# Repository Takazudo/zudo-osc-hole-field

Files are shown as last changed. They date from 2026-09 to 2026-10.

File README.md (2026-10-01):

# zudo-osc-hole-field

A standalone, cable-patched analog synthesizer on one flat 318 × 298 mm front panel, with 180 jacks above 144 controls and 33 module instances. Documentation domain: [zudo-osc-hole-field.zudolab.dev](https://zudo-osc-hole-field.zudolab.dev).

**Status:** pre-release design; no fabrication release exists.

The site is built with [zudo-circuit-doc](https://github.com/Takazudo/zudo-circuit-doc) on top of [zudo-doc](https://github.com/zudolab/zudo-doc). Authored project documentation lives under `doc/src/content/docs/`; exact-component evidence lives under `.claude/skills/`, and the component pages are generated from that evidence.

GitHub Actions runs the evidence validation, documentation checks, site build and built-site checks, plus Python unit tests under `scripts/` and `design/`, for pull requests and pushes to `main`. CI also replays aggregate source regeneration, including pinned native schematic and display checks, and retains any generated diff when that replay fails. These checks need no secrets and do not deploy the site; they do not establish electrical or physical qualification.

## Commands

| Command | What it does |
| --- | --- |
| `pnpm install` | Install dependencies |
| `pnpm dev` | Dev server, regenerating component pages as evidence changes |
| `pnpm build` | Publish selected models, generate component pages, build the site |
| `pnpm check` | Validate evidence, check generated output is current, type-check the site |
| `pnpm check:site` | Post-build checks: references, publication scope, links |
| `pnpm circuit:check` | Validate the component evidence (offline) |
| `pnpm circuit:generate` | Regenerate the component pages and the preflight report |
| `pnpm circuit:doctor` | Report required and optional tools |
| `pnpm previews:generate` | Render footprint previews (optional; needs Docker) |

Agent-facing commands (new component bundles, online source refresh) are listed in [circuit/WORKFLOW.md](circuit/WORKFLOW.md).

## Tool requirements

| Tool | Required | Used for |
| --- | --- | --- |
| Node.js ≥22.18 | Yes | Everything |
| pnpm 11 (via corepack) | Yes | Install and scripts |
| Python ≥3.10 | Yes | Evidence validation (standard library only) |
| git | Yes | History and review diffs |
| Docker with the pinned KiCad image | No | Footprint previews |
| Chrome | No | Browser smoke check |
| Network | No | Downloading sources and assets only; the build is offline |
| easyeda2kicad | No | Importing CAD assets for LCSC-listed parts |

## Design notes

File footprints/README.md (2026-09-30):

# KiCad footprints

The project has one footprint library at
`footprints/kicad/zudo-osc-hole-field.pretty/`. Keep each `.kicad_mod` there
once; do not maintain a second byte-identical master copy. Place associated 3D
models under `footprints/kicad/zudo-osc-hole-field.3dshapes/` and use the
project's `${KIPRJMOD}` model prefix.

Footprint origins follow the part's functional datum. For panel hardware, the
origin is on the panel-hole axis so the fixed panel placement remains the
reference. This seed set contains generic parts and does not move any panel
hardware.

Courtyards are generated, never hand-drawn. `scripts/libgen/gen_courtyards.py`
replaces only `F.CrtYd` artwork with a rectangular outline enclosing pads and
body artwork plus 0.25 mm, using a 0.05 mm stroke. Run
`bash scripts/libgen/regen.sh` after footprint changes and regenerate after a
merge conflict; preserve any non-courtyard artwork edits.

Each imported symbol, footprint, and model is covered by a receipt in
`circuit/cad-receipts/`. A receipt records the pinned source path and commit,
hashes of inspected source bytes and output bytes, plus a fidelity class. The
seeded package footprints are classified as `family`; they are not proven
manufacturer-specific geometry. The white LED footprint's source model was
unavailable in the pinned commit, so that footprint has no 3D-model reference.

The seed importer refuses to overwrite existing assets. To intentionally
refresh them from the read-only sibling checkout, review the current diffs and
run `python3 scripts/libgen/seed_assets.py --source-repo <path> --replace`,
then run `bash scripts/libgen/regen.sh --check`.

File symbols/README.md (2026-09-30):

# KiCad symbols

Each authored symbol has one fragment at `symbols/src/<SymbolName>.kicad_sym`.
The committed `symbols/zudo-osc-hole-field.kicad_sym` library is generated from
those fragments in sorted symbol-name order.

Do not hand-edit the assembled library. Update the affected fragment, then run
`bash scripts/libgen/regen.sh`. If a merge conflicts in the assembled library,
keep either version long enough to resolve the fragments and regenerate it.

Every symbol carries `MPN`, `Manufacturer`, and `LCSC` properties. A blank LCSC
value records that no supplier code was verified; do not fill it from a guess.
Non-orderable utility symbols may use blank MPN and manufacturer values. Any
non-empty footprint reference uses the `zudo-osc-hole-field` nickname and must
resolve inside the project's single `.pretty` library.

Seed fragments were extracted from the pinned zudo-pd commit recorded in their
CAD receipts. `python3 scripts/libgen/seed_assets.py --source-repo <path>` is an
explicit import operation; ordinary regeneration does not read the sibling
repository.

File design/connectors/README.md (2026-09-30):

# JST GH conditional harness candidate

Issue #63 retains the JST eGH primary drawing and owns the exact BM top-entry 3-, 7-, and 8-contact header CAD and evidence. `jst-gh.json` is the machine-readable handoff to #35. The 7.3 mm mated height is a reference dimension, without an installed stack tolerance. The generated WRL is a nominal header body prism, with KiCad's model Y axis inverted relative to the mounting-surface footprint drawing; it is not a vendor solid or a housing/cable model.

The drawing's top-entry PC layout gives 0.6 mm pad width, 1.25 mm pitch, 1.0 × 2.8 mm reinforcement lands, 1.35 mm from pin 1 centre to the reinforcement land's inner edge, 5.6 mm total vertical land span, and 3.9 mm from the signal-land bottom to reinforcement-land bottom. These imply 1.7 mm signal-land length. No drills occur in this SMT pattern. The project courtyard adds 0.25 mm beyond the outer pad or body bound.

With the header centred on the adapter x axis, the unchanged selector mounting pad's inner copper edge is x=8−2.6/2=6.70 mm. The GH7 generated courtyard reaches x=6.35 mm, leaving 0.35 mm nominal x clearance. GH8 reaches x=6.97 mm after the courtyard generator's two-decimal rounding and overlaps copper by 0.27 mm. This is a nominal geometric comparison only; #35 owns connector y/rotation placement, routing, cable paths, support and packing.

The GHR housing and SSHL contact symbols/footprints named `EXTERNAL_NOT_FOR_PCB` exist only to verify cavity/contact numbering through the evidence pin-map contract. They must never be placed on a board. Primary ratings cover 1 A with AWG26, 50 V and −40..+105 °C including current rise. Simultaneous-contact derating, crimp quality, pull retention, loom bend/strain relief, installed stack and physical fit remain OPEN / NOT RUN. No board or harness is qualified.

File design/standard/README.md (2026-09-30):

# OSC-ES-1 electrical proposal

Authority is **PROPOSAL (planning, owner-delegated)**. These remain design inputs, not captured circuits, accepted system behavior, or manufacturing data. Issues #15, #18 and #21 retained source bytes, audited selected pin maps, ran draft cell checks, and promoted exact component evidence into the generated catalogue.

- `electrical-standard.json`: named role-to-part mapping, signal limits, 19 functional cell definitions, remote-control/island and calibration contracts, and explicit disposition of all fourteen planning defaults.
- `parts-shortlist.json`: 36 exact shared-family representatives. Blank supplier codes and `UNVERIFIED` availability are intentional. A listed identity does not establish factory stock.
- `rail-budget-preliminary.json`: planning module counts, conservative additions, package rounding, load assumptions and arithmetic. **The negative rail exceeds its design ceiling by 72.655 mA.**
- `source-receipts.json`: primary PDF byte receipts used for amplifier current choices and the retained Analog Devices Rev. C ADG5412F source. The exact selected identities and source facts are promoted in #21's component owner bundles.
- `../../project/osc-hole-field/electrical-decisions.json`: E01–E09. Existing D01–D12 remain untouched.

Run `python3 design/standard/check_standard.py` from any directory. A consistency pass includes an explicit over-budget finding; it does not certify a passing rail budget. It checks IDs, exact-family references, cell parts/values, amplifier allocation arithmetic, ideal threshold/gain/RC/fault calculations and truthful budget flags.

Cell terminals are functional names. The #21 component owner records map numeric symbol/footprint pins to #15 and #29's retained manufacturer evidence. ALFA RPAR's retained 2020 v.7 PDF confirms AS3340D SOIC-16 identity and pin functions; schematic nets, supply suitability, oscillator behavior, calibration, physical fit, and procurement remain open. Cells request amplifier roles; do not embed amplifier MPNs in Python cell implementations.

Passive entries are exact shortlist series representatives in one shared owner bundle. The generated catalogue publishes the real `RC0603FR-07100KL` record as that bundle's landing page; the other ten exact representative MPNs remain separate inventory/owner records. A 100 kohm representative is not the orderable MPN for a 10 kohm resistor. No pseudo family MPN or per-value expansion is introduced; unknown order codes remain open.

## Work note

Requested: decide the instrument-wide electrical standard and downstream contract. Initial `regen-all.sh` and `pnpm circuit:check` passed, with no tracked regeneration. Inventory and integration rules were empty; CAD checking was disabled. Read the imported R21 contracts and the planning size/current table, then recomputed a deliberately conservative package budget with every additional input, reference, remote-pot, wiper and indicator buffer charged explicitly.

The design adds source-facing power-off isolation, lowers bulk amplifier quiescent current, reduces the 48 DC pot loads, specifies factory calibration and keeps sensitive nodes local. No panel geometry, imported handoff, generated component page, or sibling-owned document was edited.

Remaining work includes AS3340D commercial orderability, full electrical/supply suitability and physical fit, exact Murata lifecycle/evidence gaps, the Fenghua exact-MPN gap, physical/temperature/tolerance checks and value-specific passive identities for precision-output stability, module capture, #24 power-off/rail sequencing and startup, #29 octave error and oscillator calibration, #33 a netlist-derived budget, and #34 resolving the 72.655 mA preliminary negative-rail deficit before #35 partition. The revised precision-output cell passes 12/12 TI OPAx197 model cases at 27 °C, but no hardware qualification follows from that result. The ADG5412F project-supply fault response/current budget, physical fit, cable stability, thermal behavior and procurement remain open. Full site build belongs to the manager's merged-base guarded verification.

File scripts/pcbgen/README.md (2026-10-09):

# PCB draft sync

Run `bash scripts/kicad/run.sh python3 scripts/pcbgen/sync.py <board-id>` after the matching KiCad schematic netlist has been exported. Board definitions live in `design/boards/<board-id>.json`; the checked-in `fixture-jacks` definition demonstrates the format. The generator reads panel hardware coordinates only from `design/grid/placements.lock.json`, then translates them with `scripts/geometry/panel_frame.py:to_kicad()`.

The definition contains a panel-frame outline polygon, optional convex corner radius, 2/4/6/8 copper-layer count, preliminary layer stackup and thickness, NPTH mounting holes, copper keepout polygons, board domains, and the exact selected lockfile UIDs. Those domains and UIDs are eligibility and coordinate inputs; the exported netlist controls which footprints are populated. A netlisted `FootprintOriginMm` seeds the exact panel-frame centre, and `KiCadOrientationDeg` sets the native angle after a `BoardSide` flip. Parts without a source origin begin on a bounded off-board staging grid. Fixed panel hardware must stay on `F.Cu`. `F.Cu` faces the panel and `B.Cu` faces away. The shared panel origin is translated to `(100, 50)` mm and used for both drill/place and grid origin. Board sheet size is A2.

A footprint belongs to this generator only when its UUID equals the UUIDv5 derived from the board ID and reference. The same rule applies to outline segments, declared mounting holes, and rule-area keepouts. Sync can remove those items when the source removes them. It never removes an unowned footprint, track, via, zone, text or graphic; a conflicting unowned reference fails before the generator takes it over. Existing free footprints retain their current location. Fixed hardware footprints return to their lockfile position and are locked. Library footprints are loaded once per type, then cloned. KiCad's random generated UUIDs are rewritten after save; the postpass also sorts only owned footprint/keepout blocks so repeated syncs are byte-identical. Schematic paths use the netlist sheet and symbol UUIDs.

Fixed hardware always returns to F.Cu before the exact lockfile angle is applied.
An explicit B.Cu or conflicting `KiCadOrientationDeg` fails without saving the
board; equivalent full turns are accepted but the lockfile angle is retained.
For free components, changing the library footprint preserves position, side,
native angle and locked state. Explicit `BoardSide` then applies KiCad's native
flip, followed by an explicit `KiCadOrientationDeg` if supplied. Source-origin
locking still applies when `FootprintOriginMm` is present without `BoardRegion`;
sync never unlocks an existing free footprint. Nonfinite source angles fail.
New hidden source fields explicitly use KiCad's 0.15 mm default text thickness
so their first saved form survives reload unchanged; existing field strokes remain untouched.

`bash scripts/pcbgen/check.sh <board-id>` runs the pinned KiCad 10.0.6 DRC with schematic parity, zone refill and all severities, then writes JSON, top/bottom PNG renders and an SVG to `boards/<board-id>/reports/`. The summary separates rule violations, unconnected items and parity issues, and exits nonzero for DRC errors or parity issues. It does **not** claim that a clean rule check qualifies the PCB or its mechanical fit.

Run `python3 -m unittest scripts.pcbgen.test_pure -v` for board-definition and UUID tests and `bash scripts/pcbgen/test_fixture.sh` for the ten-jack oracle fixture. The fixture tests exact lockfile placement, zero schematic parity issues, byte-identical repeat sync, owner track/via/zone/text/graphic preservation, component re-netting, and component removal. Its jacks are deliberately unrouted; unconnected items are expected. The synthetic circuit and board are unvalidated drafts and are never fabrication order files.

The fixture also runs `fixtures/check_sync_pose.py` through the pinned oracle:
saved B.Cu hardware is repaired to its fixed front pose, conflicting fields leave
board bytes unchanged, replacement preserves both lock states and B.Cu placement,
explicit source overrides take precedence, and repeat sync stays byte-identical.
`python3 -m unittest scripts.pcbgen.test_pose -v` checks the pure source policy.

Current limitations: the stackup JSON records intent while KiCad receives thickness and copper count; detailed dielectric/material rule values await the board-stack decision. Fillets require a strictly convex polygon. The fixture cannot establish physical jack-panel fit or electrical function.

## Reviewed routing translations

`design/partition/routing-placement-translations.json` is an explicit source input to the floorplan generator. Its default empty list changes no placement. A reviewed translation binds the complete expected source row, a nonempty evidence reference and a nonzero 0.1mm-grid delta within ±2mm. It is restricted to movable JL/JR resistors outside bypass clusters; side and orientation cannot change. The generator rejects stale source rows, duplicate entries, source-edge clearance below0.30mm and courtyard separation below0.35mm. It does not repack other components.

This source geometry mechanism does not accept routed copper. Any activation still needs native10.0.6 placement, DRC/parity, warnings, original pad-group membership, settled/fresh agreement and full retained-copper checks after schematic/source regeneration. Fixed panel hardware remains bound to the original lockfile. Never edit the generated floorplan JSON to adopt a movement.

## Region placement for repeated clusters

After sync, `place.py` positions generator-owned, unlocked free footprints within the optional `regions` in a board definition. Each region names a schematic `Block` instance and a repeated `family`, plus a panel-frame `rect` `[left, top, right, bottom]` in millimetres, `side` (`F.Cu` or `B.Cu`), `edge_clearance_mm`, and `mounting_clearance_mm`. See `fixture-place-six.json` for six 17 mm translated regions. One block may declare both faces when each part has an explicit `BoardSide`. A part with `FootprintOriginMm` is checked at that exact source coordinate against its native courtyard and obstacles; it is never searched onto a different position. The placement UIDs and fixed hardware coordinates still come solely from the grid lockfile. Locked or unowned free footprints keep their locations; an absent or moved fixed footprint is an error.

Export the schematic netlist, run sync, then run `bash scripts/kicad/run.sh python3 scripts/pcbgen/place.py <board-id>`. `--board`, `--netlist`, and `--report` select alternate paths. The report defaults to `reports/placement.json` beside the board. Each schematic `Block` must have a matching region. A family is placed once from its courtyard boxes, and each repeated instance receives the same relative positions translated to its region. A component with an `Island` field naming a selected panel UID is anchored near that hardware. `DecouplingOf` can name an IC `Role` or reference; otherwise shared signal nets assign nearby passives to an IC cluster. Courtyards, both-side through-hole pads, mounting holes, keepouts, and outline edges constrain legal positions. There is no spill outside the named region. An impossible placement exits nonzero and writes an `OVERFLOW` report with the instance, needed area, and available area; it does not save the board.

Courtyard containment checks every outline edge against the complete courtyard rectangle, including concave cutouts and the closest distance to an edge or notch tip. Boundary contact is rejected; positive edge clearances retain the existing 1e-6 mm comparison tolerance. Every chosen region must agree with the native footprint face and any explicit `BoardSide`. Explicit `FootprintOriginMm` anchors retain precedence over a searched template and are never relocated; an anchored base supplies the template for later repetitions without an explicit anchor.

Run `bash scripts/pcbgen/test_placer.sh` for one-instance, six-instance, island, and overflow oracle fixtures. It checks second-run byte identity, exact 17 mm translations, zero courtyard violations, and zero schematic parity issues in KiCad 10. The fixture is unrouted, so unconnected DRC items are expected. The placer uses conservative axis-aligned courtyard boxes and a 0.5 mm search grid. The suite also rejects repeated templates on the wrong native face without changing board bytes and checks anchored-base template reuse. Its report remains `PLACED DRAFT`; final layout and mechanical/electrical qualification require later checks.

## Draft routing pipeline

Add `routing` to a board definition with `min_track_width_mm`, `net_classes`, and `zones`. Each class names exact nets and gives `track_width_mm`, `clearance_mm`, `via_diameter_mm`, and `via_drill_mm`. The `Default` class covers all other nets. A zone specifies its net, copper layers, local clearance, minimum fill thickness, and `pad_connection` (`thermal` or `full`). Its optional `polygon` selects an explicit split-plane shape; absent it, the board outline is used. KiCad applies copper-edge clearance during fill. Two-layer fixtures use ground pours; the four-layer fixture uses `In1.Cu` ground and `In2.Cu` +12 V planes. The dense fixture additionally uses an `F.Cu` ground pour to join inner-plane regions cut by connector escapes. These dimensions are draft routing inputs, not fabrication limits.

Run `bash scripts/pcbgen/route.sh <board-id>` after netlist export, sync, and placement. `--board` selects a fixture or other repository-local board path; `--threads`, `--heap-mb`, and `--timeout-sec` override the defaults in `router.env`. The default router has at most half the host's CPU threads (capped at six), a 2 GiB JVM heap, a bounded container memory limit, and a 180-second wall limit. It disables Freerouting's optional optimization stage so a bounded autoroute can write its SES result. `--no-fanout` is available for continuation runs whose existing copper already escapes SMD pins. `route.sh` enters the machine-wide heavy-run queue. Freerouting runs offline in a digest-pinned container. The pipeline updates project net classes and minimum track width, creates owned zones without deleting owner zones, fixes existing tracks/vias, fills zones, exports Specctra DSN, routes headlessly (`-de`, `-do`, `-mt`), imports SES, checks every pre-existing track/via and zone, refills, and runs KiCad 10 DRC with schematic parity. Freerouting's 2.4.1 [CLI options](https://github.com/freerouting/freerouting/blob/v2.4.1/docs/command_line_arguments.md) and [release](https://github.com/freerouting/freerouting/releases/tag/v2.4.1) are the primary command source.

The default report is `reports/routing.json` beside the board, with routed/unrouted net counts and names, via count, total track length, run time, sampled container memory peak, and separate KiCad error/warning/unconnected/parity counts. `reports/ratsnest.json` also records the complete native KiCad unconnected-edge count; large-board DRC JSON can truncate its item and net-name list, so names from that JSON are only a sample when the counts differ. `ROUTED DRAFT` requires zero KiCad rule errors, unconnected items, and parity issues. Exit 3 means `TIMEOUT DRAFT`; the report names nets from the router's final log when available and otherwise labels the pre-route DRC snapshot. Other incomplete or failed routes exit 2. A fully routed board skips the router and leaves board bytes unchanged; rule and parity errors still fail. Prepared source copper and refilled planes are also checked before invoking the heuristic router. Silkscreen warnings can remain on synthetic fixtures and are reported separately.

`--max-passes` raises Freerouting's pass limit (default 20) for a single bounded run. Before importing a session, the pipeline drops its `(placement ...)` block: routing never moves footprints, and Freerouting writes board-only NPTH footprints without an image name, which KiCad's SES parser rejects.

`finish_routes.py` is an optional finishing pass for the few connections a heuristic run leaves open. Run it through `scripts/kicad/run.sh` after `route.sh`. It finds nets that still have more than one native connectivity cluster and adds tracks and vias with a two-layer 0.1 mm grid maze search. The search keeps each net-class width and clearance, the board hole and edge clearances, and track/via keepouts, and it never places a via over an SMD pad. When no path exists, it may rip up the tracks and vias of the fewest blocking signal nets, then route them again in a new process (bounded by `--max-rips`). Rail and ground copper is never ripped up. Pads, footprints, holes, zones and keepouts never move. It writes `reports/finish-routes.json`. Re-run `route.sh` or `check.sh` afterwards; only native KiCad DRC with schematic parity decides whether the result is acceptable.

`replicate.py` copies **local-net** tracks and vias from one `Block` to translated instances of the same region family. It matches source and target parts through their `Role`/footprint signatures, pin numbers, nets, and exact footprint/pad translations. Shared rail/ground tracks and already routed target nets are left alone. The remaining shared nets should then be routed by `route.sh`. Run it through `scripts/kicad/run.sh` with `--source` and optional `--targets`; it writes `reports/replication.json`. It refuses a placement that differs from the template.

`bash scripts/pcbgen/test_route.sh --quick` builds and checks the two-layer, four-layer, six-instance replication, rerun, and timed-out barrier fixtures. `--dense` reproducibly builds the full 3 × 10 jack stress slice from retained copper sources, adds the explicit ground stitching, checks the complete DRC gate, repeats generation, and exercises missing-via and stale-geometry regressions. `--dense-route` performs a new bounded source-column/full-slice heuristic experiment and archives prior cache attempts. The accepted repair, measured failures, and ownership boundary are documented in [dense-evidence/README.md](fixtures/dense-evidence/README.md). The fixture uses audited jack footprints, one OPA4196 quad-amp **section** per synthetic indicator (one package per cell for independent routing stress), an LED and passives, and one 40-pin KiCad stock connector. It is deliberately a routing stress topology, not the proposed indicator circuit or a package-count decision. The pinned KiCad stock connector symbol fragment is retained in `fixtures/Conn_02x20_Odd_Even.kicad_sympart` (SHA-256 `247f848336a03a540f21f6ca8cd6fd064ef3f38b89cdef1e6d7a947aa7ae2d57`). `fixtures/dense-slice-report.json` records measured completion and resource results. Every autorouted PCB remains an unvalidated draft for human routing, thermal, mechanical, and fabrication review.

## Draft ground extraction numerical setup

`bash scripts/pcbgen/test_native_prerequisites.sh` runs the standalone control/core
terminal-access, enabled-foil export and core package-field regressions through
the pinned KiCad oracle under the heavy guard. These executable native fixtures
use `*_native_regression.py` names; they are not ordinary Python unittest modules.
Each run retains fresh local fixture receipts and leaves earlier evidence intact.

Use a disposable local environment; the pinned KiCad oracle exports native
geometry separately. Numerical extraction never changes a PCB or qualifies
materials, soldering, temperature, or hardware.

```sh
python3 -m venv .circuit-cache/ground-solver-venv
.circuit-cache/ground-solver-venv/bin/python -m pip install -r scripts/pcbgen/numerical-requirements.txt
.circuit-cache/ground-solver-venv/bin/python -m unittest scripts.pcbgen.test_ground_access scripts.pcbgen.test_ground_annular
```

The pins are also installed before Python unit-test discovery in CI. The separate
`power_locality_native_regression.py` runs explicitly through the pinned oracle in
CI; it proves that a pad and orphan zone cannot pass a main-network audit. Full-board
resistance solves run through `bash $HOME/.codex/scripts/heavy-guard.sh --` and
retain the board/source hashes, finite interface definitions, material conditions,
convergence limits, and exact failure reason. Native electrical connectivity,
numerical screens, and physical qualification are distinct gates.

## Grid router and cut-line capacity

`grid_dump.py` (KiCad oracle, read-only) exports pads, tracks, vias, keepouts, the outline and the native open pad islands of a four-layer board. On the host, `grid_router.py` joins each open island to its net's largest island with a grid A* path over F.Cu/In1.Cu/In2.Cu/B.Cu and through vias. `--rip` removes and reroutes named signal nets around boxed-in pins. It writes an unchecked proposal of explicit segments and vias with stable UUIDs. `grid_apply.py` (KiCad oracle) writes that proposal into a candidate board copy. Accept a proposal only after native DRC/parity, refill, ratsnest and ground checks on the candidate. Put the candidate two directories below the repository root, for example `.circuit-cache/<name>/` with the board's `fp-lib-table`, `sym-lib-table`, project, schematic and `sheets/`. Elsewhere `${KIPRJMOD}/../../` does not resolve and DRC reports spurious `lib_footprint_issues`. The raster is conservative by one cell half-diagonal; zone pours are not obstacles because they refill around new copper, so cut pours need their own ground check.

`cut_capacity.py` reads the same dump and scans vertical and horizontal lines. Demand is the number of signal nets with pads on both sides; capacity per layer is the ideal number of track centrelines at the chosen width plus clearance in the line's free runs. A signal-layer ratio below 1 proves those layers cannot carry the crossing nets; ratios near 1 are still unroutable in practice. Both tools need `numerical-requirements.txt`. `python3 -m unittest scripts.pcbgen.test_grid_router` covers synthetic routing, via use, clearance, boxed pins and capacity.

## Neck-down areas at IC pin rows

`design/partition/neckdown-areas.json` holds the neck-down rule (0.15 mm Default-class track width and signal-to-signal clearance; rails and AGND keep their net-class clearance) and, per board, the ICs that get a rule area. Inside the KiCad image, `neckdown_areas.py <board> --select` records every IC (reference `U*`) with a pad on an open Default-class net; the board's `.kicad_pro` must sit next to the board so net classes resolve. `neckdown_areas.py <board>` then draws one rule area named `pcbgen:<board>:neckdown` (nothing disallowed) over each listed IC's pads plus 2 mm on the signal layers, and writes `<board>.kicad_dru` with the matching custom rules. `route_jack_grid.py` passes the rule to `grid_router.route` and `negotiate` for listed boards: raster cells inside the areas use the neck clearance to other signal copper and full clearance to the grown rail/ground nets, path points carry a neck flag, and `copper_rows` draws segments touching an area at the neck width. Stage workspaces copy the `.kicad_dru`. Each stage's native check refills zones until the per-net island counts settle, because a single refill of fresh copper can under-count open pour islands.

## Grid routing on CI

`.github/workflows/route.yml` runs `route_jack_grid.py` on a GitHub-hosted runner (4 vCPU, 16 GB, 6 h job limit) instead of the local machine. Dispatch it from the default branch with `board`, an existing `branch`, `from_stage`, optional `to_stage`, `workers` (default 3) and `max_minutes` (default 330, at most 335). The job uses CPython 3.10 with `numerical-requirements.txt`, compiles `grid_astar.c` with the runner's `cc`, and runs KiCad through `scripts/kicad/run.sh` with the pinned image. `--max-minutes` stops the driver between stages and caps negotiation deadlines, so resumable negotiate and region state (`.circuit-cache/<board>-*.pkl`) is saved to the Actions cache under the board and branch and restored by the next dispatch. Adopted stages are committed to `branch` with the stage range and open-edge counts; if the branch moved and a rebase fails, the commit goes to `ci-route/<board>-<run id>`. Logs, receipts and the host memory peak are uploaded as a seven-day artifact.

Pushes made with the workflow token do not trigger other workflows, so push again or reopen the PR to run the gate. `bash scripts/pcbgen/dispatch_route.sh <board> <branch> <from> [<to>] [--workers N] [--max-minutes M] [--no-wait]` dispatches the workflow and waits for the run. Pause local routing of the same board while CI routes it.

`.github/workflows/route-shards.yml` splits the hotspot-region stages of one board over parallel jobs. `route_jack_grid.py --shard I/N` plans the start board's stranded-pin regions once. Regions are spread over N shards by stranded-pin load, and every signal net is owned by exactly one shard, the one whose regions hold it most often. A shard renegotiates only its own nets in its own regions. Overlapping groups stop growing at an even share of the stranded pins. For a range of only signal/rrr stages (`signals-local`, `signals-NN`, `rrr-NN`, `signal-escapes`), the plan instead bisects net centroids by board area, balanced by open edges. A shard routes only its own open nets and passes `rip_only` to `grid_router.route`, so rip-up never touches another shard's nets. `route_shards.py delta` records the segments and vias each shard removed and added. In the merge job, `route_shards.py merge` applies all deltas to the pinned base commit, runs the native DRC/parity/refill gate once, reverts whole nets whose new copper fails or splits a plane, and promotes the result only if native open edges fall. It writes `reports/grid-routing/shards-<run id>.json`. Dispatch it with `gh workflow run route-shards.yml --ref main -f board=<board> -f branch=<branch> -f shards=<N>`. It shares route.yml's concurrency group, and shard state is not resumed between dispatches. `python3 -m unittest scripts.pcbgen.test_route_shards` covers the plan, the delta and the text merge.

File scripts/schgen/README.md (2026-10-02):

# Functional schematic generator

`bash scripts/schgen/regen.sh` writes the draft master project under `schematic/`. The source is `design/spec/instrument.py`. **Never hand-edit a generated `.kicad_sch`**; change the spec or generator and regenerate. The checked-in synthetic circuit is a generator fixture, not an electrical design.

## Spec API

`specification()` returns `(families, instances)`. A `Family(name, parts, global_nets, sensitive_nets)` owns one or more shared child sheets. Set `Part.page` to 2 or higher when the module is too large for one sheet; each instance receives the same page set. A local net cannot span pages; declare an intentional cross-page net in `global_nets` or redesign the split. An `Instance(family, name, index)` places that sheet in the master. The current example in `design/spec/modules/synthetic.py` has three instances of one family and a separate, single instance power flag sheet. Local labels acquire paths such as `/SYN1/AOUT`; names in `global_nets` stay global across instances. `sensitive_nets` is carried into each component's hidden `Sensitive` field for later partition checks.

Each `Part` has a stable `key`, library `symbol`, reference `prefix` and `ordinal`, explicit `unit`, position in mm, and a complete `pins` map. A pin value is a net name or `None` for an explicit no-connect flag. Set `rotation` to 0, 90, 180 or 270. `value`, `footprint`, `attributes`, `panel_ref`, `panel_refs` and `dnp` are optional. `panel_refs` maps sheet-instance names to exact locked references on a shared sheet; `dnp=True` emits a not-fitted schematic component. `attributes` accepts `MPN`, `Manufacturer`, `LCSC`, `Role`, `PanelUid`, `Island`; `Block` is `${SHEETNAME}`, expanded per instance by KiCad. `Family.paper` may choose a larger sheet such as `A1`. A package's units use keys `U1.1`, `U1.2`, etc., the same prefix and ordinal, and **every populated unit must appear exactly once**, including the power unit. Unused amplifier/comparator pins still need `None` entries.

Circuit designators use `<prefix><instance index × 100 + ordinal>`, so part ordinal 3 in instance 2 is `R203`. Reserve instance indexes 1–999 and ordinal 1–99. Panel hardware instead sets `panel_ref` to the exact designator from the placement lockfile; collisions are rejected. The package scheme makes each instance's local references stable even though the schematic file is shared.

`LibrarySymbol.from_fixture()` reads a complete stock symbol expression extracted with `scripts/kicad/extract-stock.sh`. The fixtures are solely for the synthetic example. The project's real symbol and footprint libraries are separate entries in the project-local tables, using `${KIPRJMOD}`-relative paths. Authors add real symbols through the library workflow; do not copy the fixture into the project library.

## Verification

```sh
python3 -m unittest discover -s scripts/schgen -p 'test_*.py'
bash scripts/schgen/smoke.sh
```

The verifier compares every exported component pin with the spec, including deliberate no-connect pins. KiCad excludes power symbols and flags from the exported component list, so ERC covers those. This proves connectivity parity and ERC rule cleanliness for the selected instrument spec; it says nothing about electrical suitability.

## How to write a module: H1/H2 sample-and-hold pilot

`design/spec/modules/sample_hold.py` is the first real family. Its `family()` composes the OSC-ES-1 functions from `design/spec/cells/` with explicit net mappings. `design/spec/instrument.py` instantiates that one family twice, as `H1` and `H2`; `scripts/schgen/generate.py` loads each project symbol fragment alongside the test-only power flags. `bash scripts/schgen/regen.sh` regenerates the root and shared `schematic/sheets/sample_hold.kicad_sch`. Do not edit either schematic by hand.

Start from `design/grid/placements.lock.json`. The pilot's `panel_bindings()` resolves three jacks, SAMPLE, SLEW and three magnitude LEDs for each instance, checks that all sixteen UIDs are unique, and provides exact per-instance designators. A `Part.panel_refs` map sets those exact references on the shared sheet: for example `J:H1.TRIGGER → J509`, `J:H2.TRIGGER → J510`. Panel parts carry `PanelUid` as a `${SHEETNAME}` template because KiCad shares their source file; the binding audit resolves the template for H1 and H2. Other components leave `PanelUid` empty. `Part.dnp=True` marks the parallel 100 nF hold-footprint option without fitting it.

Use `cell_parts(cell_id, panel_uid, nets, ordinal_start=..., instance_tag=...)` to allocate unique component ordinals and local keys. Map every port that joins another cell, such as LF398 `RAW_HELD` into the slew pre-buffer, by name. A cell's private nets are deterministically namespaced. Complete all physical units of each IC package, including power and explicit no-connect units. `Part.attributes` should carry source-backed MPN/manufacturer/LCSC where available, plus Role and any Island. When a passive value differs from the selected series representative, leave the instance MPN blank until an exact orderable part is captured.

Declare timing/storage nets in `Family.sensitive_nets`: this pilot marks `HOLD_CAP`, `SLEW_STORAGE`, `SLEW_POT_IN`, `TIMING_C` and `TIMING_RCX`. Its `C:${SHEETNAME}.SLEW` island groups the panel pot, 2.2 kΩ minimum resistor, five lag capacitors and both buffers on one board. Keep `RAW_HELD` local to each KiCad sheet instance. A global label used merely to span child pages joins H1 and H2; the pilot therefore keeps the handoff's capture and post-hold stages as separate circuit groups on one A1 family sheet. Rails alone are global until the real power interface replaces test flags.

Run `bash scripts/schgen/smoke.sh` after regeneration. It requires KiCad 10 ERC zero errors, exact identity parity for the 228 documented pin-type warnings in `design/reports/master-erc-warning-baseline.json`, full exported netlist parity, and rejection of a deliberate hold-node mutation in both instances. Warning identity compares the sheet path, severity, type, description, and sorted symbol/pin descriptions; it omits KiCad UUIDs and schematic coordinates. `python3 -m unittest scripts.schgen.test_core` covers the shared-sheet panel-reference and DNP generator features; `python3 -m unittest discover -s design/spec/modules -p 'test_*.py'` checks pilot binding and topology. These are connectivity checks, not bench validation. Canonical schematic regeneration also refreshes `design/reports/current/sample_hold.json` from the current family. `python3 -m design.spec.modules.build_sample_hold_current --check` and the pilot regression tests reject a stale package population. This report gives partial per-instance rail planning values and leaves complete maxima NOT ESTABLISHED; `design/reports/spice/sample_hold.json` records only ideal RC behavior.

## M5A/M5B and M4A/M4B mixer families

`design/spec/modules/mix5.py` and `mix4_vca.py` compose standard OSC-ES-1 cells through `mixer_common.py`. The two family sheets are each reused twice; instance indices 81–84 reserve collision-free internal component references while `panel_refs` binds the exact fixed M5A/M5B and M4A/M4B hardware. `panel_bindings()` asserts 19 unique UIDs per instance. Input and OTA current nodes are local; only instrument rails are global. Regenerate with `bash scripts/checks/regen-all.sh`, then export the KiCad 10 netlist and run `scripts/schgen/verify_netlist.py`. The module tests check panel identity, audio/CV isolation, protected input order, clip monitor, OTA termination and planned rail counts. `design/spec/modules/run_mixer_spice.py` generates bounded ideal and vendor OTA fixtures with one frozen in-range calibration across the command/input matrix. It exits nonzero on a model headroom, zero-bias shutoff or gain-law failure; the report retains feedthrough and real-hardware limitations.

## Whole-instrument integration audit

Run `bash scripts/schgen/regen-master-reports.sh` to regenerate the instrument, export its KiCad netlist, and write `design/reports/master-audit.json`, `design/reports/netlist-stats.json`, `design/power/rail-budget.json`, and `design/power/rail-ledger.json`. Run the same command with `--check` to fail on regeneration or report drift. `scripts/schgen/audit_master.py` gates the exact 35-instance roster, all 438 locked panel UIDs, designator and physical-unit uniqueness, KiCad pin-net parity, and sensitive panel-net island membership; its report lists every sensitive net and island member. It also rejects an all-NC active unit, a missing multi-unit package section, a blank island on a Sensitive pin, and a panel part outside its Sensitive island. `scripts/schgen/build_master_budget.py` sums the eleven authored module current reports and the power-inlet bleeders. It labels all sums as reported planning/assumed subtotals and leaves complete typical and guaranteed maxima unresolved where source reports do. `scripts/schgen/build_rail_ledger.py` checks the current fitted IC package supply-pin traces against exact worksheet package counts and audits all 347 per-load feed/rail assignments in `design/power/rail-allocation-input.json`; its separate conditional cases and extra inlet/SH assumptions never promote the original subtotals to guaranteed maxima.

Run `bash scripts/schgen/export-master.sh` for the 36-page hierarchy PDF, one root SVG, and one SVG for each of the thirteen distinct generated child-sheet sources under `schematic/exports/`. The child SVGs show the shared source sheet; the PDF shows every instance. KiCad exports are draft documentation, not fabrication files. `normalize_exports.py` replaces only PDF/SVG creation timestamps after the oracle export so repeated exports are byte-identical; SVGs otherwise retain KiCad's whitespace formatting.

## Source I/O allocation (#60)

The module family decorators in `design/spec/modules/io_partition.py` assign candidate jack/control/core regions and repack equivalent physical amplifier/Schmitt channels. Every source function is compared by canonical channel signature before and after packing. The A/B control driver uses local unity feedback plus two 499 ohm isolation resistors into its jack-region precision receiver. The native source now has 640 fitted IC packages. `design/reports/io-partition.json` is the source-level package/unit/island/area handoff to #35; it is not a selected PCB partition.

After aggregate and master-report regeneration, run `python3 scripts/checks/io_partition60.py --netlist .circuit-cache/master-audit/netlist.net --require-cut` and then the same command with `--check`. Run `python3 -m unittest scripts.checks.test_io_partition60` for missing/duplicate package assignments, swapped units, raw-TIP and sensitive-island crossing, and impossible-area mutations. `python3 -m design.spec.modules.run_manual_ab_spice` screens the fixed A/B path with the retained TI model. Exact protection stays OPEN in #59 and no physical fit is inferred.

## Current power documentation

`build_supply_documentation.py` renders marked current requirement, rejected-source
comparison, return/loss and master-capacitance sections from
`design/power/supply-architecture.json`. It runs after that report's producer in
`regen.sh`; use `--check` to reject documentation drift. Edit the authored contract
or producer, then regenerate those sections. The surrounding historical narrative
remains authored. These source-derived planning values do not establish source
capacity, complete load maxima or physical qualification.

`build_schematic_status.py` renders marked rail and family-current tables from
`design/power/rail-budget.json`. Canonical regeneration refreshes the mixer
worksheets and master budget before these tables. `--check` rejects publication
drift; unknown complete maxima and partial worksheet scopes remain explicit.

Canonical `bash scripts/checks/regen-all.sh` now runs full-master ERC, exact warning-identity checks, native netlist parity and the complete master audit through `smoke.sh --generated`, then refreshes the retained draft PDF/SVG exports. The `--generated` flag avoids a second source generation; direct smoke use still regenerates by default. Export checks require exactly the active child SVG set plus the root view, and one PDF page per hierarchy instance plus the root. `regen-all.sh --check` rejects stale exports through its tracked-byte comparison. These source/consistency checks do not establish electrical or physical qualification.

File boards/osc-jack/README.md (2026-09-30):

# Historical single-J experiment

This directory retains the rejected #38 nine-board-era schematic, PCB and route receipts at base commit `1fc6e5347308fe5e8166d5828ba3ba6fa8e101c7`. It is excluded from the current ten-board manifest. No copper was imported after 180-second fanout and 900-second no-fanout attempts; 5,611 native open edges remained.

Current source projects are `osc-jack-left` and `osc-jack-right`. The historical definition is retained at `design/partition/history/osc-jack-before-66.json`; use the original commit for exact historical lock metadata/reproduction. Do not run current generation over this historical board or treat its reports as half-board evidence.

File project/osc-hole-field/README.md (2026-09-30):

# Project source inputs

`current-spec.json` is the scope/constraint summary; the workbench grid is geometry authority. Block and board contracts, decision log, issues and sheet plan are engineering task inputs, not a native netlist or a second component-evidence validator. Preserve the official `circuit/WORKFLOW.md` as the agent entry contract.

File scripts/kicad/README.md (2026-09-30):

# KiCad 10 oracle

All headless KiCad commands for `zudo-osc-hole-field` run through `scripts/kicad/run.sh`. The wrapper requires KiCad 10.0.x and selects an available oracle in this order: `KICAD_CLI_BIN`, Docker with the digest in `pin.env`, then the standard macOS application path. If it cannot find a compatible oracle, it exits with an error. Missing KiCad is never treated as a skipped check.

## Use

From the repository root:

```sh
bash scripts/kicad/run.sh kicad-cli version
bash scripts/kicad/run.sh python3 -c 'import pcbnew; print(pcbnew.GetBuildVersion())'
bash scripts/kicad/run.sh ngspice -b path/to/model.cir
bash scripts/kicad/extract-stock.sh Device R
bash scripts/kicad/smoke.sh
```

`run.sh` mounts the repository at `/work`, sets it as the working directory, uses the caller's UID and GID for Docker, and gives KiCad a temporary writable home. Docker runs with `--rm --platform linux/amd64 --network none`. The temporary home is removed after each command, and files written into the repository remain owned by the caller.

`extract-stock.sh Library Name` prints a stock symbol S-expression if that symbol exists, or a stock footprint S-expression otherwise. For example, `bash scripts/kicad/extract-stock.sh Device R` prints the resistor symbol and `bash scripts/kicad/extract-stock.sh Resistor_SMD R_0603_1608Metric` prints that footprint. The command does not copy or modify project files.

## Platform notes

- **WSL/Linux:** install Docker and use the pinned image from `pin.env`.
- **macOS:** Docker Desktop runs the pinned `linux/amd64` image with emulation. A native KiCad 10.0.x CLI can be selected by setting `KICAD_CLI_BIN` to its executable path. Native `python3` and `ngspice` commands also need to be available on `PATH`; for Python board generation, that Python must import `pcbnew`.
- **CI:** install Docker and run the same scripts. Do not silently skip oracle checks when Docker or the image is missing.

The schematic and PCB files produced by these tools are unvalidated drafts. A clean ERC or DRC result reports rule checks only; it does not validate circuit behavior or board fit. Never generate or send fabrication order files from this workflow.

## Known pitfalls

- KiCad 9 cannot open the project's KiCad 10 file formats. The wrapper rejects versions outside `10.0.x`.
- ERC results can change when a fresh user home has no KiCad library tables. Keep project-local symbol and footprint library tables in fixtures and projects that reference stock libraries.
- KiCad CLI has no command to update a PCB from its schematic, and the IPC API needs a running GUI. Build or synchronize boards through `pcbnew` in the oracle.
- The pinned image contains KiCad, `pcbnew`, and `ngspice`, but no Java. Java-dependent tools do not belong in this oracle workflow.
- On macOS, native `KICAD_CLI_BIN` selection checks the CLI version. Commands such as `python3` and `ngspice` still use the corresponding executables on `PATH`.

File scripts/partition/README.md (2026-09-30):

# Conditional board partition generation

`bash scripts/partition/regen.sh` exports the current master with pinned KiCad10.0.6, checks native source parity and generates the I/O, stage, exact GH, courtyard, loom, support, ten-board definition and decision reports. It ends with an in-memory native footprint transform oracle. `--check` rejects drift. No KiCad PCB is drawn or saved.

Inputs are `design/partition/partition-input.json`, `stage-optical-input.json`, current schematic sources, retained mechanical/connector/wire evidence, and the fixed placement lock. Edit those inputs/generators, then regenerate. The aggregate `scripts/checks/regen-all.sh` calls this sequence after schematic generation; #35 itself intentionally leaves panel regeneration to #37.

The floorplan's source rotations are clockwise after an X reflection on B.Cu. Use `kicad_orientation_deg` when creating actual footprints. The native oracle verifies all used footprint/face/rotation classes. Drawn courtyards get a 0.35 mm free-placement separation and 0.30 mm board-edge allocation; KiCad's observed0.045 mm cached expansion per edge is bounded by 0.05 mm. Do not shrink a footprint or lower these margins to force a placement.

`floorplan-candidate.json` is a complete capacity proposal, not a routed PCB or a locality-optimized final layout. #38 must consume the new halves through its merged per-reference source-placement tooling; the current strict board-definition parser already accepts the regions. Preserve all whole packages, same-board Sensitive islands and close bypass loops while doing actual placement/routing.

The historical `diagnostic35` and reference-fanout records are superseded snapshots. They are not current BLOCKED verdicts. Physical #55/#57/#64/#65 gates and exact #59 protection remain open independently of conditional source arithmetic.

Issue #66 uses0.10 mm J search cells without changing0.35 mm drawn separation/0.30 mm edge. IC/bypass clusters use actual supply pads and all414 same-face capacitor pad distances are <=3 mm (project screening, not a manufacturer guarantee). Native full J clearance is0.260 mm after0.045 mm expansion per facing edge. Exact handoff: `design/partition/downstream-handoff-66.md`.

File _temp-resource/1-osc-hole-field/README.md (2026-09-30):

# OSC Hole Field — planning resources

Input for the OSC Hole Field epic, committed so every implementation session reads the same bytes.

| Directory | Content |
| --- | --- |
| `handoff-r21/zudo-osc-playground-r21-handoff/` | The pristine R21 design handoff, 161 files, with its own `SHA256SUMS.json`. **Do not modify it and do not run its scripts in place**: they write report files. Work on a copy. |
| `exploration/` | Nine planning-time research reports. |

The handoff carries the project's former name, `zudo-osc-playground`. The project is `zudo-osc-hole-field`.

This directory is temporary. It is removed before the epic's root pull request merges; by then the handoff is imported under `project/osc-hole-field/`, `research/osc-hole-field/` and `doc/`, and the reports live under `research/osc-hole-field/planning-exploration/`.

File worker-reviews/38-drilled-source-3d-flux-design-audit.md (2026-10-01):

# Issue 38 drilled-source 3D flux: smallest constructive next step

Read-only design audit, 2026-09-30. No code or board source was changed. The retained nominal receipts report 213 single-drill SMD, 5 multiple-drill SMD, and 305 PTH geometry certificates with zero unresolved rows. They certify historical geometry only; the PTH receipt reports zero qualified finished walls. Current-epoch UUID/geometry transfer is a separate obligation.

## A common cut-plane contract

Make one *source-to-foil cut* per local field, with a source trace on the actual exterior metal boundary and a specified **pointwise** return profile on an internal copper cut. These are field interfaces, not necessarily disjoint partitions of material: a PTH wall field and a face field can occupy the same metal. The downstream conductor field must supply the opposite **sum of all local profiles** at every geometric cut. Record its physical face, orientation, support, and exact source/native epoch. Current equality alone is insufficient. Charge all fields on overlapping metal by a Gram bound or by `(sum sqrt(E_i))^2`; do not sum diagonal energies. For the paired lower witness, use one continuous H1 potential, constant over the **entire possible wetted support** of a terminal (including the PTH wall and both exterior annular faces), with that same constant through its lead/contact metal. The constant is a trial-space restriction, not a physical equipotential assertion. Its trace on every cut must equal the downstream potential trace; otherwise supply a finite-energy transition and charge it. The source functional then equals `I*V_terminal` for every allowed flux shape.

### Drilled SMD: one planar cover lift extruded in actual foil

For each of the 218 certificates, let `D` be the union of its actual same-face annulus and convex domains, excluding every drill; let `S` be the exact disjoint first-domain partition of the possible source support. Choose a positive contained reference patch `O` on an *internal cut within the same foil*, and `b=1_O/|O|`. Its cut must be below a strictly positive source slab thickness `h` and leave strictly positive foil thickness for the downstream conductor. For any signed external `q in L2(S)`, `I=int_S q`, set `f=q-I*b` on `D` (zero extension). Thus `int_D f=0`, including `I=0` with nonzero redistribution. Solve `Delta psi=f` with insulated boundary on each cover domain, using the existing exact overlap tree to cancel all internal mean transfers. With local depth `z=0` at the internal cut and `z=h` at the exterior, use

```
J_xy=grad(psi)/h,       J_z=-I*b-(z/h)*f.
```

It has zero divergence; exterior outward trace `-q`, internal outward trace `+I*b`, and zero trace on the actual drill wall and lateral boundary. The field may live on the union of pad and via-land copper; all overlaps are one metal volume, not duplicated copper. `finite_cover_flux.cover_poincare_upper` provides a conservative planar `C` once each local convex/annular Poincare bound, an upper bound on the **whole support of f** (including O), and every exact overlap-square lower area are supplied. The 3D energy satisfies

```
E <= rho_max * ( |I|*sqrt(h/|O|)
                + ||f||_L2(D)*sqrt(C/h+h/3) )^2.
```

This form includes base/correction cross energy. The declared flux-shape class must bound `||f||`, either directly or by a proved transformation from the existing `q-I/|S|` norm. Do not substitute a sampled q. Verify the actual foil band, face reversal on B.Cu, cut location, and the reference patch against the current native board; historical cover digests alone cannot admit it.

### PTH: close the wall-to-foil trace, then use the same face lift

The existing `barrel_source_flux` mean-wall field exits at **the exterior B annulus**. Its B-face positive trace cannot be treated as a downstream foil port: it must be cancelled or rerouted in real copper. A finite constructive reroute is possible without a point electrode. Let `ri` be the actual finished inner radius, `ro=ri+t_plating` a proven contained full shell, `L` the board depth, and choose `0<d<t_B` in the actual B foil band and a complete annular land radius `R>ro`. Let `q0=I_wall/(2*pi*ri*L)`, `D=ro^2-ri^2`, `s(r)=(r^2-ri^2)/D`, `g(z)=1/d` on `[L-d,L]` and zero elsewhere, `G(z)=int_0^z g`. The stream function and shell field are

```
Psi=q0*ri*((1-s(r))*z+s(r)*L*G(z)),
J_r=(1/r)*partial_z Psi,
J_z=-(1/r)*partial_r Psi,       J_theta=0.
```

These give `div J=0`, wall outward trace `-q0`, zero end-face trace at `z=0,L`, and outer-shell radial flux `q0*ri*L/(ro*d)` only inside the upper `d` of B.Cu. Add the existing periodic/Neumann mean-zero wall correction for `q_wall-q0`; it has zero outer/end traces. On the adjacent physical B annular sleeve `ro<r<R`, `L-d<z<L`, let `D2=R^2-ro^2`, `C0=q0*ri*L/d=I_wall/(2*pi*d)` and

```
J_r=C0*(R^2-r^2)/(D2*r),
J_z=2*C0*(z-L)/D2,             J_theta=0.
```

Its inner radial trace matches the shell **pointwise**, its outer radial and exterior B-face traces vanish, and it exports `I_wall/(pi*D2)` uniformly through the internal B-foil cut at `z=L-d`. The exterior wall is never replaced by top-face injection. A simple safe wall-mean resistance coefficient is `rho_max*D/(4*pi*ri^2*L)*[max(1,L/d)^2+(2*ri*L/D)^2]`; the sleeve coefficient is `rho_max*D2/(4*pi*d)*[1/ro^2+(2*d/D2)^2]`. Evaluate with outward rational bounds, then apply the square-root sum across shell, sleeve, wall correction, exterior-face fields and downstream field. These are deliberately loose coefficients; improve only after a verified need.

Treat the F and B **exterior** annular source densities as two independent L2 traces. Apply the drilled-face cover lift above to each real exterior foil band, with cuts inside those bands and their own current `I_F,I_B`. At B, superpose the face field with the wall/sleeve fields on the same actual conductor and charge the cross energy; at F reverse the local depth. Retain all interior foil attachments but assign no external source there. The wall field continues through the shell below the B cut; its axial trace there must be retained when summing all fields on that section. The sleeve's stated uniform port is only on `ro<r<R`, not the whole cut. The downstream model sees every exact composite cut profile, and the terminal current is `I_wall+I_F+I_B`. If the current model accepts only one numerical port, construct and charge a further real-foil transfer to that port instead of identifying profiles by their totals. Validate the full physical domain/ownership and interface cancellation: shell/foil overlap is shared material, not two copies.

## One finite fixture and failure gates

Start with a synthetic two-drill rounded SMD pad whose exact receipt has two annuli and at least one convex child, plus a PTH fixture with `ri=.61 mm`, conditional `ro=.635 mm`, `L=1.6 mm`, `R>.635 mm`, `t_B>d>0`. Use signed trigonometric modes with nonzero mean and a nonzero zero-mean mode, and independently set `I=0` with a nonzero mode. Check analytic divergence and **all** normal traces (both drill walls, exterior faces, internal cuts, annulus outer radius, shell/foil radial interface, F/B orientation, angular seam) by symbolic expressions or interval-backed quadrature; integrate interface flux exactly and compare the energy integral with the outward bound. Test source partition and every overlap edge with exact rational predicates. Mutate one drill radius, remove one overlap square, set `d>=t_B`, reverse B orientation, omit B face flux, and perturb a radial interface profile; every mutation must fail before publication.

After this finite fixture, build per-contact receipts for all 523 drilled contacts at the **current** native epoch. Require complete source and material dependencies, unique UUIDs, exact source-to-cut profile hashes, no unresolved geometry, and replay rejection after a source/board mutation. The local construction alone does not qualify manufactured plating, etch/registration, solder/wetting support, resistivity intervals, lead and contact currents, or joined electrical limits. Those remain `NOT RUN`/open pending independent physical evidence and the paired whole-network model.

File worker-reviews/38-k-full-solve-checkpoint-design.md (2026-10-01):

# K full solve: restart-safe column checkpoints (read-only design audit)

## Finding

`current_trial_matrix.current_matrix` and `potential_trial_matrix.potential_matrix` already compute the 2,287 finite profiles in fixed, eight-column batches. Each batch finishes a rectangular `energy[:, start:stop]` block plus per-profile residual-work inputs and numerical gate receipts. The expensive per-column solve can be resumed after reconstructing the same mesh, full operator, factorization, source projection, and initial current source-lift Gram. The current `solve_conductor_volume.py` only caches meshes; losing its process loses all completed profile columns. A completed batch is **not** a result certificate by itself: the full unsymmetrized Gram must still pass reciprocity, the assembled current/potential matrices must pass the final bracket eigenvalue gate, and the existing source/prerequisite rechecks and exclusive result publication must still occur.

## Recommended implementation

1. Add one optional checkpoint sink to each matrix function, called **after** all existing per-batch work and the `local_residual <= 1e-8` gate. Do not alter source projection, LU/refinement, current reconstruction, correction, residual-work calculation, profile order, batch size, or summation order. On resume, place a verified column block directly into the same preallocated `energy` matrix and restore exactly the arrays and receipt rows that the existing loop would have appended. Keep the current starting `S.T @ diag(reciprocals) @ S + lift` and potential zero matrix recomputed afresh; checkpoint the **post-addition** columns so the original `+= basis.T @ field` is not repeated.
2. Bind one immutable run key to SHA-256 of frozen native export; the complete `model_source_sha256` map (including the new checkpoint code); all prerequisite receipt bytes/hashes; exact `profile_bytes` and ordered `(layer, patch.wkb, signed current)` profiles; all mesh parameters, `rho`, thickness, mode, batch size, and NumPy/SciPy/Shapely/Python versions. Also hash the **constructed operands** before admitting any checkpoint: canonical CSR/CSC shape, dtype, `indptr`, `indices`, `data` for solve matrix, energy matrix where distinct, `basis`, and `S`; hash the initial current source-lift Gram or its components. This detects changed mesh or operator construction even when the source inputs appear equal. Existing mesh cache keys alone are insufficient to bind completed numerical columns.
3. Save one file per exact `[start, stop)` range, containing the entire `energy[:, start:stop]` float64 block, per-profile `field_max`, residual-work one-norm, current correction energy where applicable, and the existing refinement, residual-work, physical KCL, and conservation receipts. Use a non-pickle format (`np.savez` with `allow_pickle=False` on read, plus strict JSON for receipts). Commit with a temporary file, flush/fsync, atomic rename, and a small manifest containing run key, range, schema version, payload byte count, and SHA-256. A batch whose file/manifest pair is incomplete, corrupt, nonfinite, wrong shape/dtype/range, or has a mismatched key is rejected and recomputed; it must never be counted as passed. Reject duplicate or overlapping ranges. Do not write a checkpoint before the batch's numerical gate passes.
4. At resume, verify every checkpoint against the **newly assembled** operands and profile receipt, then restore only a contiguous prefix of full eight-column batches (the last batch may be shorter). Refuse gaps or overlaps; recompute the first incomplete batch. Restore each per-batch receipt at its original index and verify `start`/`stop`. Recompute the scalar maximum residual from the restored physical-gate components (current) or full equation residual receipts (potential), checking every restored component against `1e-8`. Recompute `residual_work_diagonal`, `conserving_upper`, reciprocity, gap eigenvalue, and publication gates using the complete matrix, exactly once, after all columns are present. No precomputed accepted final Gram should be loaded.
5. Recheck the run-key source hashes and native/prerequisite bytes before **each** checkpoint commit and at final publication. Keep checkpoint files under the ignored `.circuit-cache` output stem, never publish them as result receipts. Preserve the existing fresh-stem rule for the final JSON/profile pair; a restart may reuse the same stem only while both final files are absent. A completed or partial public receipt still requires a fresh stem or explicit investigation.

## Practical guard interaction

Use `bash $HOME/.codex/scripts/heavy-guard.sh --max-run <bounded-seconds> --min-mem-mb <normal-gate> --label ... -- <solver-command>` in the foreground. The guard holds the machine-wide slot for each attempt and kills the command tree on timeout or daemon death; a checkpoint committed before that interruption survives. Exit 75 means the solver never ran. `ENV_SUSPECT` is not a numerical pass and receives the policy's one rerun; an actual residual, conservation, reciprocity, or bracket failure is `FAIL` and must be fixed. Choose a max run that includes the expected batch work or use the policy's bounded attempt; never bypass or weaken the guard merely to complete K.

## Risks and validation before relying on it

- The key must include the checkpoint implementation itself. Adding it to the source hash list invalidates historical receipts by design; do not rebind them.
- Hashing only source filenames and the native board is inadequate because mesh cache corruption or changed numerical libraries could otherwise reuse incompatible columns.
- A resumed run must match an uninterrupted run within the existing numerical enclosure; exact float equality is a useful test on a small fixture, but the real contract is preserved gates and no narrower bounds. Test interruption after one batch, deliberate mutation of payload/manifest/operator/profile/source hash, duplicate/gapped batches, current KCL failure, potential residual failure, and final reciprocity/bracket failure.
- Atomic files with a checksum protect interrupted writes and accidental corruption, not a malicious actor able to rewrite both payload and manifest. These checkpoints are local diagnostics only; final source and native gates remain mandatory.

No solver edits or heavy runs were made for this audit.

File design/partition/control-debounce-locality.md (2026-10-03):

# Envelope debounce placement proposal

The source moves all thirty complete envelope debounce triplets (ninety
non-panel passives) beside their existing SN74HC14DR input pins. Each triplet
contains the contact pull-up, series resistor and input-to-ground capacitor.
All six Schmitt ICs, their bypass capacitors, panel hardware, headers, net
assignments and component identities stay unchanged.

The prior first-fit packing placed the thirty capacitors 30.127–144.626 mm
from their corresponding input pads, with a median of 93.580 mm. The proposed
source placement has a maximum of 7.665 mm and median of 4.039 mm. These are
straight-line pad distances, not routed lengths or a functional result.

The 8 mm capacitor-to-input and 4 mm resistor-to-neighbor limits are project
layout targets. They are not manufacturer limits. Input identities use the
retained `fact-schmitt-pinout` / `src-schmitt-datasheet` evidence for Texas
Instruments SN74HC14DR, SCLS085 revision L. The source helper derives each
complete triplet from actual IO pin/net records and refuses changed input
identity, incomplete groups, fixed hardware moves, courtyard conflicts or
out-of-bounds positions.

The source courtyard study preserves the existing board and support geometry.
Fresh native construction and all 418 reference placements pass with zero
DRC/parity findings. Native comparison covers all 1,740 pads: exactly the
180 passive pads move, while all other pads and every pad identity, net,
shape and layer remain unchanged. The bare layout still has 872 open edges.
Compatible-copper rebuilding starts at 199 open edges; separately checked
routing batches reduce this to 0, retaining all 344 grounds, 81 source
AGND copper objects and sixteen local bypass pairs after independent refill.
The previous 72-open-edge checkpoint remains the recovery source in git.
Old routes to moved pads are not accepted for this proposal. Current/resistance, protection, component qualification and
installed fit remain open; no fabrication or order files are generated.

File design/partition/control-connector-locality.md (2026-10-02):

# Paired K/P connector locality proposal

The source assigns 123 K/P harness pairs to existing connector sites using the
explicit bijection in `control-connector-locality.json`. Both ends move together.
The exact JST BM03B-GHS-TBT(LF)(SN), GHR-03V-S and SSHL-002T-P0.2 identities and
all pin maps remain unchanged. The four JL/P utility headers stay fixed.

The initial assignment consumed alphabetically sorted signal chunks in physical
site order. Against baseline commit 141b508e89030e8465bf750147d529426c60b91f,
a nearest-signal-pad distance study selected a paired-site assignment with a
summed estimate of 6,664.254 mm on P and 25,747.667 mm on K, compared with
29,898.178 mm and 29,695.754 mm. P used retained native pad positions; K used
current source footprint-pad transforms. These are placement-distance proxies,
not routed lengths, noise measurements or proof of routability.

`control_connector_locality.reassign` requires the complete bijection, checks
the baseline header digest and exact part identities, preserves every non-geometric
header field, and proves identical multisets of occupied header and service-hole
geometry. Native P comparison covered all 1,740 pads: exactly the five pads of
each of the 123 headers move; all non-header pads and occupied AGND pad geometry
remain unchanged. The generated netlists retain every pin/net assignment and
change only 123 header origin fields on each board. The component floorplan is
byte-identical. All 195 modeled cable-route geometries and 18 load-power routes
remain unchanged as sets.

The JST eGH evidence bundle retains nominal mounting and mating geometry; it
does not qualify installed clearances, retention, crimping or derating. The
existing K depth and enclosure allocation remain proposals. Old header routes
and electrical receipts are not accepted for the new source. Native K and P
routing, actual copper compliance and installed assembly remain open.

The source-only transition is retained in `peripheral-source-epoch-20261002-connector-locality.json`. It proves complete partition equality after the declared permutation, keeps EL/octave geometry unchanged, and preserves historical native/model receipts. The historical K field audit is checked against its original netlist and explicitly rejected for the new source; the current source has a separate field projection.

Native K comparison also covers all 13,406 pads and 207 physical hole sites.
The 123 moved header groups and their service-hole ownership follow the exact
permutation; occupied geometry and non-header component pads are unchanged.
Both bare K projections report 9,650 open edges, zero DRC errors and zero
parity findings. They retain 477 reported annotation warnings, with capped
categories; neither annotation nor routing is complete. This comparison does
not reuse or update historical current/resistance receipts.

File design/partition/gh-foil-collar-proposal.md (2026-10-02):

# Proposed isolated foil collars for JL–K return 1, pin 2

**UNSELECTED engineering proposal.** The retained native local projection admits the finite geometry below without moving a header, panel item or existing pad. This is not a reconstructed board, qualified process, tested assembly, source/model admission or closure of issue #38. The proposal adds no canonical copper and changes no accepted electrical target.

The companion JSON is the source for `python3 -m scripts.pcbgen.foil_collar_geometry`. The command emits proposed copper polygons, named zone set differences, current-cut coordinates, conservative interval clearances and an open cost ledger. Its portable mode checks the retained projection and source hashes. It explicitly reports native revalidation **NOT RUN**. Add `--native-root /path/to/preserved/recovery/worktree` to verify the exact full board/export byte hashes and recompute the complete local item, hole and zone projections. Even that mode checks archived geometry only; new native reconstruction remains **NOT RUN**. Ignored native artifacts are not portable test dependencies.

## Actual source and native binding

The selected conductor is `JL-K-1`, AGND pin 2: BM08B-GHS-TBT(LF)(SN) headers, GHR-08V-S housings, SSHL-002T-P0.2 contacts and Alpha Wire 6821 BK005 wire. Other AGND pins are not merged with this test domain. Native coordinates below are millimetres, translated from the partition source by `(100, 50)`.

| Endpoint | Source connector / native reference | Face / native footprint pose | Native pad centre | Pad UUID |
| --- | --- | --- | --- | --- |
| JL | JL-K-1-JL / J900001 | B.Cu / (123, 86.05, 180°) | (119.875, 86.05) | 3f388439-96b8-5e20-aa1d-16ee31561d83 |
| K | JL-K-1-K / J900002 | F.Cu / (123, 89.95, 180°) | (119.875, 89.95) | 835eae24-7f0d-5918-8d54-859e5053df59 |

Both pads retain their full native 0.6 × 1.7 mm rectangle. Footprint UUIDs, native/export SHA-256 values, faces, rotations, board outlines, stackups and exact nearby item identities are retained in the JSON. The JL artifact is `osc-jack-left-white-current-v1.kicad_pcb`; K is `osc-core-ground-feasibility-v7.kicad_pcb`. They are historical unselected drafts, not replacements for current canonical geometry. The JSON separately hashes the source partition, locked placements and exact GH footprint; a changed source epoch fails rather than silently borrowing this projection.

## Finite geometry and actual conflicts

| Parameter | Nominal CAD | Prospective finished interval / bound |
| --- | --- | --- |
| Straight neck width | 0.200 mm | [0.180, 0.220] mm |
| Straight neck length | 0.760 mm | [0.740, 0.780] mm |
| Outer foil thickness | 0.070 mm | [0.063, 0.077] mm |
| Pad-side shoulder length | 0.330 mm | [0.310, 0.350] mm |
| PCB-side flare length | 0.480 mm | [0.460, 0.500] mm |
| Flare end width | 0.600 mm | [0.580, 0.620] mm |
| Neck centre displacement | −0.050 mm in x | Additional relative registration ±0.025 mm |
| Existing copper/pad edge uncertainty | — | ±0.025 mm |
| Copper isolation | — | At least 0.250 mm |

These are positive proposed acceptance intervals, not manufacturer guarantees. Nominal 0.200 mm meets the retained K native minimum-track rule; finished etch width is a separate requirement. A finite geometry/material pullback, full-section inner containment, outward envelope and dielectric/etch capability still need evidence. The connected copper pattern is one source union: joins are not independently displaced solids. No zero-tolerance fit is claimed.

The nominal neck centre is x=119.825. JL runs from y=84.870 to 84.110, outward in −y. K runs from y=91.130 to 91.890, outward in +y. The worst dry-collar boxes are JL `[119.690,84.045,119.960,84.915]` and K `[119.690,91.085,119.960,91.955]`. Complete nearby explicit copper is tested using conservative outer bounding boxes, including opposite-foil pads. Minimum axis separation is JL 0.270 mm and K 0.265 mm, leaving margins of 0.020 and 0.015 mm over 0.250 mm. No Euclidean diagonal clearance is invented from overlapping boxes. K's rear U4218/U4219 pads explain the −0.050 mm neck offset: the unshifted nominal gap can look adequate while its finite interval fails.

JL's existing AGND stitch overlaps the pad and bypasses the collar. The proposal explicitly retires only via `0e98d896-7f4b-529e-bb8d-5d0672d24f52` and its B.Cu segment `a93acaf3-1753-5d6e-b340-4ae1bc5472cc`. They remain untouched in the preserved board. Omitting either proposed retirement fails the screen. No existing component pad may be retired.

All native zones intersecting the bounded region receive explicit proposed local set differences. Own-face pours are removed around the full pad/shoulder/collar island; other-foil pours are removed around the full collar projection. The proposed pad, shoulder, neck and flare are retained as connected AGND copper. Every unretired barrel entering the island/collar is rejected. Cross-layer XY overlap by itself is not a DC short: this candidate deliberately uses the stronger clear-projection condition at the collar. Dielectric isolation and absence of other conductive coupling still need physical qualification.

The interval flare reaches 0.080 mm beyond its own-face pour exclusion in the worst case. This is geometric reach, not proof of filled-plane connectivity or a zero-resistance boundary. The exported target-plane identity only identifies the intended landing; filled-contour intersection and actual topology must be proved after reconstruction.

JL B.Cu is **+5V**, not AGND. Its paid return therefore needs a new 0.200 mm dogleg through `(119.825,83.750) → (120.750,83.750) → (120.750,84.500)` and a proposed 0.700/0.300 mm via at the last point to In1.Cu AGND. Finished drill [0.280,0.320] mm and barrel copper [0.025,0.035] mm are prospective. The compiler emits +5V clearance for the entire flare/dogleg and new-via antipads on F.Cu +12V, In2.Cu −12V and B.Cu +5V. It preserves the intended In1 AGND landing. New via and dogleg stay outside the isolated island and require native routing, mask, annular, plane-access and electrical proof. K's flare targets actual F.Cu AGND; spreading into that foil is also paid.

## Dry support and complete trace

Retain existing pad mask openings only. Add no opening on the shoulder, collar, flare, dogleg or new via. The full possible wet support is each same-face pad's entire copper box, expanded by 0.025 mm copper-edge uncertainty + 0.050 mm mask expansion + 0.050 mm mask registration + 0.050 mm over-mask solder extent. It remains at least 0.110 mm from the worst dry collar, above the required 0.100 mm separation. The live archived check verifies zero native baseline mask expansion and no nonzero local pad/footprint overrides. Actual mask seal, three-dimensional solder support, component-metal interference and process capability remain unqualified. The unknown header interior is not replaced by invented metal dimensions.

The output cut is the collar's complete actual width through its complete actual foil thickness. Nominal native depth is JL [1.530,1.600] mm and K [0,0.070] mm. The signed trace is `I / (actual width × actual thickness)` over the entire section, with normals JL `(0,−1,0)` and K `(0,+1,0)` and opposing endpoint net currents. It is not a trace on an ideal plane, pad centre or partial surface. A potential comparison must be constant on the complete possible cut support and extend through the adjoining real domain; this is a trial restriction, not a claim of physical equipotential. Geometry/material metric bounds and both matched field constructions are still open.

## Once-only cost and test boundary

The possible future tested assembly contains both isolated pads, both pad-side shoulders, both full collars, the actual contacts/crimps and the entire selected wire. Each collar is included in that assembled test domain once; its separate axial estimate must not be added again. The reference prism calculation at the proposed worst resistivity 0.000023 Ω·mm gives 1.582011 mΩ per neck. This is only a straight homogeneous reference diagnostic, not a manufactured-class upper bound or a whole-branch result.

JL's PCB-side flare, dogleg, new barrel, annular transfer and In1 spreading lie outside that tested domain and require separate finite current/potential energy bounds. K's flare and F.Cu spreading likewise remain paid. The other branch/K copper remains in the common network. The original combined 0.5 mΩ common requirement, GH 0.5 A/contact, rail 1 mΩ, distribution 20 mV and full-path 0.20 V requirements are unchanged. Parallel paths require a joined network proof; equal sharing cannot be assumed.

**No qualifying harness certificate exists.** Every excitation ampere must cross both selected collars, with no other electrical ports or unmodelled internal interface energy. Other GH AGND pins, other harnesses, board planes and main wires create bypasses in the installed system. A whole-board `V/I_total` cannot certify this conductor. The fixture must isolate the selected path or provide an independently valid local power certificate. A detached fixture test does not automatically certify later remated contacts: temperature/current/contact-state coverage, fixture power, instrument terminals and test-to-installed process applicability remain open. No catalogue contact maximum is promoted to this assembled-domain certificate.

The next constructive step is a bounded native reconstruction of these exact named retirements, zone clips and source copper/mask unions, followed by refill, local and whole-board connectivity/DRC, and full-section extraction under the pinned oracle. It must verify the PCB-side landing and preserve all fixed pads, obstacle copper and nets. Only then can this pair supply actual cut geometry to an isolated-assembly fixture/process design and a matched access-energy proof. This proposal supplies neither that reconstruction nor electrical/hardware acceptance.

## Source-owned K native priority correction

The first native realization is retained in `foil-collar-native-receipt.json` as a rejected historical experiment. Its K collar and F.Cu AGND landing both used priority 0, causing a real `zones_intersect` error. The source now specifies K collar priority **1**, with retained landing priority **0**. The compiler rejects equal priorities for a same-face landing, and the native constructor checks the actual target priority before applying the owned value. JL's explicit planned priority remains 0; its historical candidate is neither refilled nor rebound to this revised proposal hash.

K's declared native scope is `full_refill_draft_epoch`. A native rule/connectivity result may pass while the historical local-only criterion remains failed. This does not suppress any KiCad rule or admit a material class, electrical model or physical build. Every refilled copper change belongs to the new K artifact, and fresh whole-geometry electrical witnesses remain required. All dimensions, fixed hardware, source copper allowances and original electrical limits are unchanged by this priority correction.

## JL frozen-source replay

JL now also declares `full_refill_draft_epoch` before a new native run. The
historical local-only delta failure and failed in-flight source-stability check
remain in `foil-collar-native-receipt.json`; neither is relabelled as passing.
The new run must freeze its source inputs and check the entire refilled board,
including nonlocal copper changes, complete connectivity and the full untrimmed
dry section. This scope change makes no dimensional, net, clearance, priority
or electrical-limit change. The completed source-stable native result is
recorded separately in `foil-collar-jl-replay-receipt.json` and its Markdown
companion. Its rule/connectivity scope passes; its local-only, electrical and
physical admission do not.

The historical K receipt keeps its original global proposal hash. K-local
construction is unchanged, but no K replay or rebinding is implied by this
JL-only continuation. Fresh electrical witnesses remain required for each
candidate's complete geometry, and no physical or material admission follows
from a passing native rule/connectivity result.

The 2026-10-02 paired K/P header-source transition is separately bound in
`peripheral-source-epoch-20261002-connector-locality.json`. The complete partition
comparison permits only that explicit pair/site permutation and its service-hole
associations. Both collar endpoint records are unchanged. This updates only the
portable source binding; the retained native projections remain historical,
unselected drafts. It does not rebind a native or electrical model receipt.

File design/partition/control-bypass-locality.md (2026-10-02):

# P-board bypass locality repair

A fresh native inventory of the partial control-board copper found all sixteen
assigned IC/bypass rail pairs disconnected. Twelve bypass capacitors were
22.53–171.01 mm from their own IC supply pads. The four previously compacted
slew-amplifier bypasses were within 2.30 mm. The existing generic capacity
packing did not enforce local P-board bypass groups.

The source now places the remaining ten complete IC/bypass groups together:
eight logic ICs with one capacitor each and two quad amplifiers with two each.
All twenty-two moved parts are unfixed internal B-side packages. All panel
centres, headers, supports, the other packages and the existing slew groups
remain unchanged. The source guard checks complete group membership, retained
geometry, courtyard clearance and all sixteen same-face supply-pad distances.
The source geometry puts the logic pairs at 2.535 mm and the analog pairs at
2.2975 mm. This 3 mm project screen is not a manufacturer qualification.

A disposable native placement comparison found zero rule errors and zero
schematic-parity findings for this candidate. It initially retained 42 silkscreen
warnings. Source-driven label regeneration then placed all 418 references
and the full native layout replay passed with zero violations. Obsolete
signal routes and dangling rail branches were removed. Sixteen local bypass
connections and ten signal links were added, followed by seventeen additional
local signal links using short layer changes. The bypass-repair checkpoint has
905 segments, 278 vias and 389 open edges, zero DRC/parity findings, and all
344 ground contacts connected after independent refill. Combined final
replay, 26 targeted tests, documentation build and publication checks passed
in 83 seconds, with the existing workbench link exception retained. All 482 PCB tests and 281 source/check tests pass. CI is pending. The previous 366-open-edge copper checkpoint remains in git
history and is not evidence for the new placement. Current-source connectivity,
resistance/current limits, protection and physical qualification remain open.
No fabrication or order files are produced.

The seventeen layer-change links passed a separate full replay, 26 targeted
tests and publication checks in 81 seconds. All sixteen bypass rail pairs
and all 344 ground contacts remain connected after independent refill.

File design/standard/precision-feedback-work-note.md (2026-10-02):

# Exact precision-feedback passive identities

The 16 captured precision-output feedback networks now select Yageo
RC0603FR-07100RL (100 ohm, 1%, 0.1 W at 70 C, 0603) and KEMET
C0603C102J5GACTU (1 nF, 5%, 50 V, C0G, 0603). Their retained manufacturer
product sheets were generated and inspected on 2026-10-02. Supplier order
codes, stock and factory allocation remain unverified.

Dedicated `r_feedback` and `c_feedback` roles preserve the previous generic
100 kohm and 100 pF representative identities. Circuit values, connectivity,
footprint geometry and all fixed panel positions are unchanged. Derived
symbols use the existing R0603 and C0603 family assets. The existing models
are nominal body illustrations, not maximum tolerance or installed-fit
proof. In particular, the capacitor's existing land geometry and model offset
remain unqualified; neither is promoted to exact vendor fidelity.

The resistor's 0.1 W rating applies at 70 C. The family voltage ceiling is
not permission to apply 75 V across 100 ohm; power, derating and fault duty
must all be satisfied. Physical output stability, tolerance, temperature,
protection, thermal behavior and assembly qualification remain open.
No fabrication or order files are created.

Validation completed before the first commit:

- Clean baseline regeneration: PASS, 268 seconds. Final full regeneration:
  PASS, 303 seconds, including native board ERC (zero errors, 673 retained
  warnings). The first runs exposed missing receipt hashes and stale master
  statistics; both were corrected from actual source/native outputs.
- Component contract: PASS, 68 manual inventory lines, no declared placement
  binding. Exact shortlist capture: 38/38. Fresh isolated native ERC: all 38
  symbols, 71 units and 244 pins, zero violations.
- Fresh simulations: 12/12 precision cases, 24/24 protection-candidate
  diagnostic cases and 13 mixer cases, PASS in 39 seconds. None is physical
  stability or protection qualification.
- Publication, regenerated footprint-selection manifest, documentation build
  and strict site checks: PASS, 39 seconds, retaining the existing single
  workbench-link allowlist exception.
- All 1,122 discovered unit cases are covered by passing group runs and
  targeted reruns. The legacy blank-MPN assertion was replaced with the two
  exact identities. Python 3.12 was used for report comparisons, matching
  regeneration; the retained numerical environment is Python 3.10. Its two
  floating-result report differences were not adopted. Three genuinely stale
  dependent candidate reports were regenerated and their tests rerun.
- The complete IO comparison changes only 32 symbol/MPN pairs and the bound
  native-netlist hash. A separate source-only epoch proves that the peripheral
  definitions remain unchanged. Historical native/model receipts are retained
  unchanged and are not made current by this proof. Historical local-artifact
  integration was NOT RUN in this clone.

The first CI run caught a stale generated standard-cell precision-output
sheet. The harness was regenerated from the exact roles, and its generator
was added to the aggregate regeneration command so future identity changes
cannot omit this output. A fresh native cell-harness check and CI rerun are
pending. Supplier allocation, factory solderability, installed
clearance, fault/thermal duty and physical output stability remain open.

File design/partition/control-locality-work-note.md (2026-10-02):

# Control-board slew locality and current native placement

The P source previously scattered the H1/H2 slew capacitors across the upper packing strip, with one capacitor more than 136 mm from its fixed control courtyard. This change groups each complete nine-package slew circuit near its unchanged potentiometer. The 18 moved packages are the two complete quad-amplifier packages, their four bypass capacitors, two minimum-resistance parts and ten storage capacitors. Every other package and all 438 panel centres are unchanged.

The source generator requires both complete circuit groups, exact source roles, no fixed/DNP/non-P parts, finite orthogonal poses, courtyard/through-hole/reservation clearance, 25 mm component-centre locality and 3 mm supply-pad distance. The resulting maximum centre distances are 21.8597 and 21.3594 mm; all four bypass supply-pad distances are 2.2975 mm. These are geometric screens, not routed parasitic or physical qualification.

The entry component contract and 288-second baseline regeneration passed. Post-change aggregate regeneration completed, retaining zero master ERC errors/228 exact warnings and zero board ERC errors/673 warnings. The combined 272-second preflight wrapper then failed because the final ratsnest command used an unsupported --output option. Correcting that invocation and running the actual placer passed in six seconds: 146 free footprints retain their source poses; all 418 source packages, 36 support footprints and 139 fixed controls match. Full native connectivity finds 872 open edges. The unmodified outline/reservation draft has 35 native rule errors, 428 silkscreen warnings and 12 representative-field parity warnings.

A fresh candidate with the existing reviewed local RV601 tab and six individual power-terminal reservations clears all rule errors. Its exact source-backed per-unit field projection clears all schematic-parity warnings. This native candidate run passed in seven seconds; it remains unrouted and cannot enter a conductor model. Historical ground/contact/current results have not been rebound to the moved contacts.

Silkscreen placement is being improved using visible references outside same-face courtyards, pad projections and board edges. Initial 0.8 mm trials cleared native DRC but are not the final proposed text policy. The 0.8 mm rotation-aware candidate fits all 418 references outside same-face courtyards and has zero native DRC/parity findings. The 1 mm trials still have placement failures, so the label work remains local and unselected. No native board from these experiments is included in this source checkpoint.

Remaining work includes canonical adoption of the reviewed P outline and reservations, source-bound board generation, routing and actual copper/current analysis, exact protection and supply implementation, manufacturing process selection and physical qualification. The original four-layer 2 oz stack and fixed mechanical depth remain proposals. No fabrication/order files are created.

All 1,117 portable unit tests pass. The first run passed 529 cases then stopped at missing NumPy in system Python; the remaining six discovery directories passed in the existing environment with pinned NumPy 2.2.6 and SciPy 1.15.3. The 66-line component contract passes before and after. Integrated CI remains pending.

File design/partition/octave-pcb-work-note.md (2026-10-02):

# Five passive octave adapter PCB drafts

The five source-defined SRBV160803 adapters now have actual two-layer PCB layouts. Each contains the fixed switch and two JST BM07B-GHS-TBT(LF)(SN) headers. Source outlines, stack proposals, component/pad poses and all panel centres are unchanged. These are unvalidated drafts, not fabrication files.

All five routed on their first bounded attempt. O1/O3/O5 use 33 tracks and 7 vias, with 111.7603 mm total track length; O2/O4 use 22 tracks and 3 vias, with 69.9345 mm. Each has eight connected functional nets, zero actual native open edges, zero all-severity DRC findings, and zero schematic parity findings. The complete current checker also verifies all 30 native pad/net mappings, source poses, fixed outline, zones and full project rule/class settings. It runs fresh DRC after capturing source bytes and rejects stale clean reports, physical changes and weakened rules. CI rechecks disposable copies without heuristic routing.

The placer now accepts boards whose entire inventory is already source-anchored, while rejecting unaccounted/free footprints and incomplete/nonfinite poses. It does not serialize a board when it moves no footprints. Untouched rear-switch reference labels are moved onto the existing top tongue; edited label positions are preserved.

## Validation history

- Initial aggregate baseline: PASS, 364 seconds, no tracked drift.
- First O1 preflight: FAIL, 2 seconds, because the placer unconditionally required a region; no routing occurred. The fixed-only path corrected that contract.
- Five-board native preflight: PASS, 20 seconds; each initially had 14 expected open edges over eight functional nets.
- First O1/O2 routes: PASS, 27 seconds. O3–O5: PASS, 34 seconds. No subsequent heuristic routes were required.
- Early stability harnesses: FAIL at 10 and 16 seconds. Raw native serialization needed deterministic owned-item ordering; complete parsed item comparisons found no geometry changes. A transient intermediate was not retained, so no speculative normalizer defect is claimed or patched.
- Two complete standalone sync/place/check passes finished for all five boards with byte-identical PCBs and clean DRC. That 285-second wrapper subsequently failed in the new terminal checker because KiCad UTF8 wrappers were compared directly to Python strings. The checker now compares full library-qualified string identities.
- Fourteen native fixed-only controls and eight current-board rejection controls exercise the actual KiCad oracle. The latter include a copied clean report plus a new short, altered drill, ignored short rule, extra assignment, moved outline, added cutout and changed zone clearance.

Historical peripheral ground receipts remain byte-identical and stale for physical/current acceptance. A separate routing-only transition proves that the five canonical board definitions change only by the declared routing object; it does not promote those historical model results. Actual current PCB evidence is separate.

## Remaining scope

The SRBV body and stepped carrier/shaft assembly, final solder process, harness handling and installed fit remain NOT RUN under #55/#65. The three front and two rear adapters preserve the selected mechanical proposal; renders are not physical qualification. The control board P is still incomplete under #39. Jack/core ground-current limits, rail/protection implementation and whole-instrument electrical acceptance remain open. No Gerber, drill, BOM or placement order files are generated.

Latest corrected native finish: PASS, 51 seconds; all five unchanged routing gates, 14 fixed-only and eight current-geometry/rule controls, fresh source checks and rear-label renders.

Final aggregate validation passed in 275 seconds. It legitimately changed AGND's exported net class from Default to Ground in the five netlists; the final native source checks are repeated against those actual outputs. No connectivity or component value changed. A high-quality fresh O3 top render replaced a basic render that omitted portions of the visible model/text; its board bytes did not change. All ten native copper SVG views and all front/back body arrangements were inspected.

Post-regeneration native/source checks and documentation build/site checks: PASS, 49 seconds. The existing single allowlisted workbench link exception is unchanged. Twenty-six related portable tests pass; label and native rejection controls pass. Source and DRC hashes were checked again before commit. Final integrated CI is pending.

Integrated-main verification found the source transition also needed to account for the five regenerated AGND net-class declarations. The transition now permits exactly `Default` → `Ground` on the single AGND declaration and rejects every other byte change. Historical receipts are unchanged. All 46 integrated portable checks pass; all five native source/DRC receipts still match current bytes. One attempted direct script invocation lacked the repository module path; regeneration was rerun successfully as `python3 -m scripts.pcbgen.peripheral_source_epoch`.

Initial integrated CI run 36991212915 failed in the existing face-disagreement fixture: it rewrote fixed panel hardware to B.Cu while intending to test only free repeated parts. The fixture now preserves fixed source faces. The complete native placer suite passes (20 seconds), including the intended opposite-face rejection, anchored-base translations, unchanged bytes after a rejected plan, overflow, and manually locked parts. Component evidence validation also passes. The corrected integrated CI run remains pending.

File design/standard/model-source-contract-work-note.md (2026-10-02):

# Captured circuit to model binding

This batch repairs two reproduced correctness gaps in the precision-output and
MIX4 model producers. Grounding the captured precision amplifier's noninverting
input previously left the simulated input unchanged. Changing captured MIX4
TIA feedback from 100 kΩ to 200 kΩ also left its simulated 100 kΩ resistor
unchanged. The current captured circuits and retained decks agree; these were
missing guards against circuit/model drift, not observed hardware failures.

The precision producer now checks the complete five-part template and its nine
compiled units, including exact selected amplifier, primitive types, physical
pin maps, supplies and instance identities. The 100 Ω feedback resistor and
1 nF capacitor still have unresolved exact-value MPNs. A change to a valid
feedback value reaches the deck; unsupported topology or identity changes fail
before invoking the oracle. The historical 10 kΩ/100 pF failing fixture remains
independent of the current source.

The MIX4 producer now checks the captured summer, OTA divider, offset trim,
IABC series resistor, physical OTA1 pins and TIA connections. Its resistor
values and trim ranges are intentionally locked to the reviewed fixture;
retuning the source requires reviewing and regenerating that fixture. Extra
fitted branches on modeled internal nodes fail. Four coherent input sources,
ideal references, imposed current servo, ideal amplifiers and the 100 kΩ load
at SUM_POSTVCA remain explicit model substitutions. This is not a complete
input-to-jack or servo/headroom model.

Reports retain the evaluated source projection and exact model/deck hashes.
Portable checks compare those projections and decks with the current source;
missing or duplicate vectors and nonfinite simulator measurements fail. Source
bytes are checked for changes during execution. This does not reinterpret
historical source epochs or extend the model boundary to excluded circuits.

Validation results are recorded after the fresh pinned runs. The original
failure fixtures, fixed calibration, numerical limits and all physical gates
are preserved. Issues #49 and #50 remain open pending acceptance reconciliation;
actual protection in #59 and physical circuit/PCB qualification remain open.
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

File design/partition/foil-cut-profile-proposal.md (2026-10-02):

# Finite foil-cut current and potential functional

Status: **standalone source primitive and synthetic analytic checks only**. No actual candidate cut, physical geometry/material/contact/current class or assembled solver is admitted. Historical model files and receipts are unchanged. This supplies a missing mathematical interface for the unselected [foil-collar route](./gh-foil-collar-proposal.md); it does not select that route or establish issue #38 electrical acceptance.
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

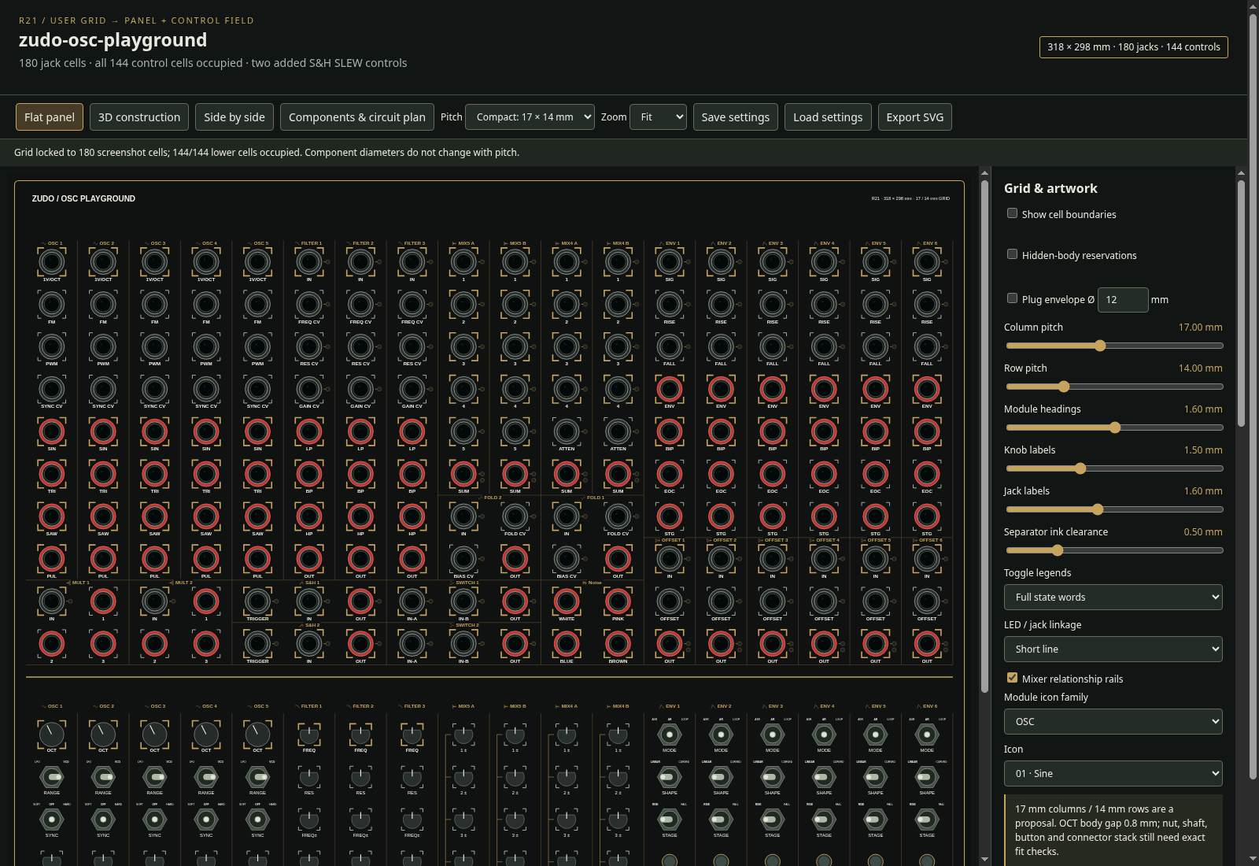
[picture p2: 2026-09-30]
_temp-resource/1-osc-hole-field/handoff-r21/zudo-osc-playground-r21-handoff/payload/project/osc-playground/workbench/reports/desktop.png

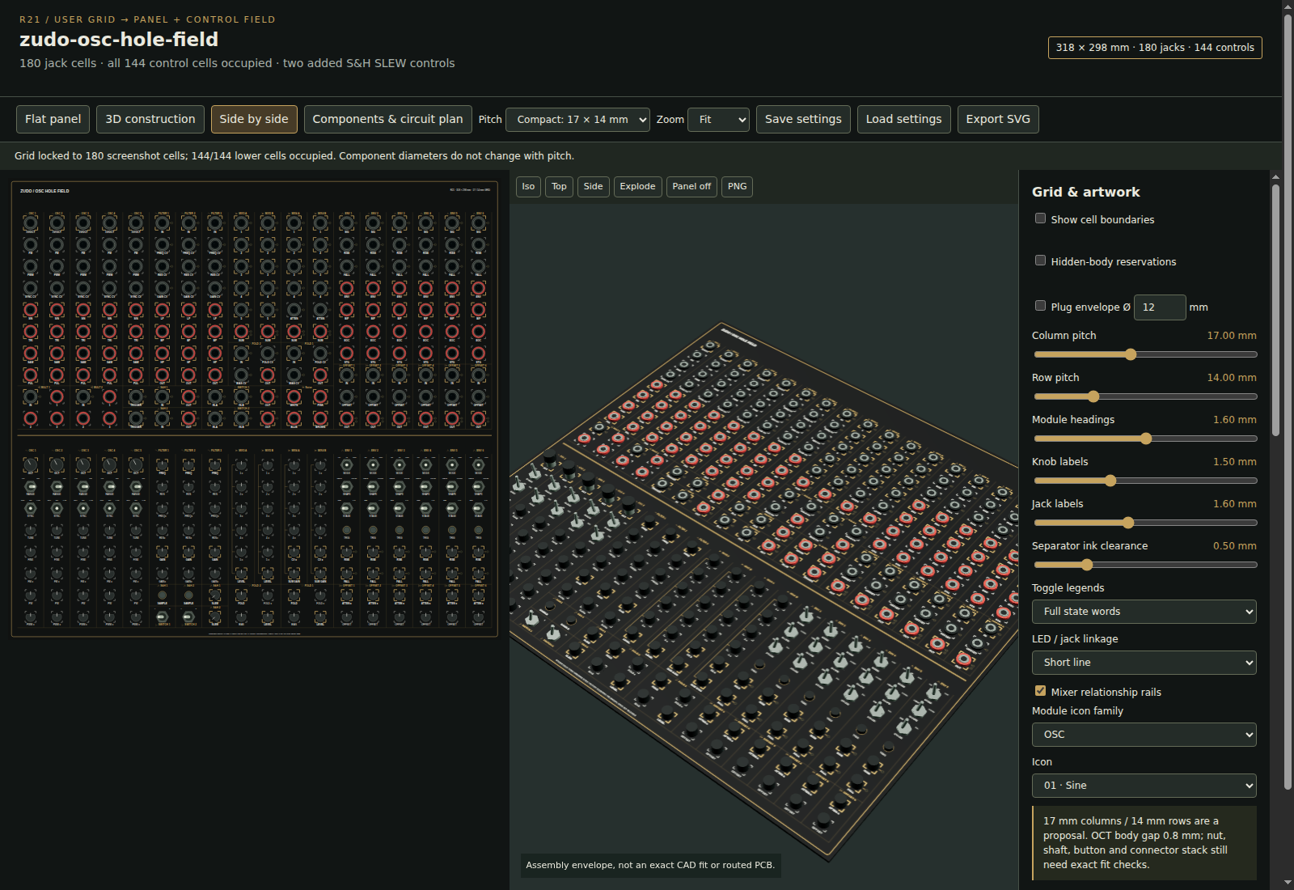
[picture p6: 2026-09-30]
project/osc-hole-field/workbench/reports/split.png

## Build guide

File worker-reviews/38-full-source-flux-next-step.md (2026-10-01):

# Issue 38 full source flux: next bounded step

**Status: NOT ACCEPTED.** This is a read-only gap audit of the current worktree. Native geometry and nominal conductor diagnostics do not establish manufactured contact support, physical source flux, 3D transfer, a paired primal witness, material/process bounds, current classes, or joined electrical limits.

## Smallest useful source-first implementation

Build a fail-closed **current-epoch own-source boundary manifest** before applying another flux coefficient. Reconcile every fitted own AGND source contact from `design/partition/partition.json` and `design/reports/io-partition.json` through `scripts/pcbgen/source_contact_inventory.py` and `scripts/pcbgen/source_flux_boundary_inventory.py` to the *current* native board/export/receipt. Retain exact board, source, stack, outline, pad and hole digests and each ref/pad/net/UUID/face/primitive/drill identity. Require 4,143 distinct contacts: JL 1,070, JR 896, K 1,903, P 214, EL 60. The recorded historical family split is 3,620 drill-free convex SMD, 218 drilled SMD (213 single drill and five multiple drill), and 305 PTH; recompute it from current authoritative exports and fail on any difference rather than carrying it forward as an assumption.

The result should distinguish **current nominal geometry verified** from **physical support NOT QUALIFIED** per row. Only after the current manifest passes, calculate conditional local bounds for the drill-free convex subset with `scripts/pcbgen/convex_source_flux.py:coefficient_bounds`. That function still requires a source-selected contained profile, a positive actual foil slab height/material interval, and a drill-free domain. If those physical inputs are unavailable, record the row as unresolved; do not supply a guessed value or infer a physical slab from a KiCad pad.

## Existing receipts and admission APIs

- Historical source/family map: `.circuit-cache/issue38-recovery/own-source-flux-boundaries-v2.json` (SHA-256 `bc766e053d76791c68afd41f65ea9ce184b93fdf11725d9b019c7d018e9b9ad4`). Historical local geometry: `single-drill-cover-certificate-v2.json` (`9750c2e223e963e2ce2bf344967a5a78fb687be9fd263369cd1568e8e461dd79`), `multi-drill-cover-certificate-v2.json` (`1e2bd5decc29c5ed003e92222c5952a7a5cc1b5ce7ba47715ca5f036b090fc53`), and `pth-source-geometry-certificate-v2.json` (`777af6fb22334f140a9b4a649e843c62957ed093ba4004835f45933d330cd245`), all under `.circuit-cache/issue38-recovery/`. Their constructors bind the frozen `.circuit-cache/issue38-recovery/white-land-review/` source epoch; they are not current model-entry receipts.
- JL/JR current native exports and receipts: `.circuit-cache/issue38-recovery/white-current-boards/osc-jack-{left,right}/native-geometry.json` and `current-native-receipt-v6.json`, with `current-own-source-inventory-v1.json` beside each. `scripts/pcbgen/jack_white_current_binding.py:verify` checks the current native authority. `scripts/pcbgen/verify_jack_source_geometry_epoch.py:verify` binds the historical local covers to the current J geometry; retained result `.circuit-cache/issue38-recovery/jack-ground-source-epoch-bridge-v4.json` says local nominal geometry equivalence only.
- K v7 current export/receipt: `.circuit-cache/issue38-recovery/core-feasibility-v7/ground-feasibility-geometry.json` and `ground-feasibility-native-receipt.json`. `scripts/pcbgen/core_model_gate.py:require_native_prerequisite` is its native admission API; `.circuit-cache/issue38-recovery/core-feasibility-v7/full-ground-basis-v2.json` is the separate complete nominal contact basis. A source-bound K v7 bridge for historical source-family cover rows still needs an explicit retained check in the new manifest.
- P current export/receipt: `.circuit-cache/issue38-recovery/control-feasibility-v3/ground-feasibility-geometry.json` and `ground-feasibility-native-receipt.json`; source definition receipt `design/partition/control-ground-feasibility/osc-control.receipt.json`. `scripts/pcbgen/control_model_gate.py:require_native_prerequisite(native_path, receipt_path, manifest_path)` checks the full current P prerequisite, including all 344 native ground contacts; 214 are own source contacts. Check historical family rows against that current export.
- EL current export/receipt: `.circuit-cache/issue38-recovery/optical-ground-prerequisite-v3/native-geometry.json` and `native-receipt.json`; source definition receipt `design/partition/peripheral-ground-feasibility/optical-ground-v2/osc-stage-optical.receipt.json`. `scripts/pcbgen/peripheral_model_entry.py:enter(source, native_bytes, receipt_path, manifest_path, include_loads, port_limit)` checks the 72-contact native basis, including 60 own source contacts; call with complete loads and port limit zero. Check historical family rows against that current export.

The manifest should recheck dependency bytes at entry and before publication, reject duplicate/omitted identities and contradictory digests, and never rewrite any historical receipt. Existing tests to extend are `test_source_flux_boundary_inventory.py`, `test_jack_ground_source_epoch.py`, `test_convex_source_flux.py`, `test_pth_source_geometry.py`, and `test_barrel_source_flux.py`. Useful mutations include a deleted/duplicated source contact, changed UUID/face/primitive, moved or inserted foreign drill, changed stack/outline/board after initial read, and nonzero redistribution at zero net current.

## What remains after this step

The finite drilled-SMD and PTH covers are nominal 2D geometry. `scripts/pcbgen/barrel_source_flux.py` supplies inner-wall zero-net and mean-to-one-annulus fields, but there is no complete annulus-to-foil/reference transfer or exterior annular-face source lift. The shell/foil overlap square in `scripts/pcbgen/pth_source_geometry.py` proves positive nominal geometric overlap, not a 3D current field, material ownership, or cross energy. A complete dual source field must be glued to the full conductor and accompanied by a continuous primal witness. Actual lead/solder/GH/main support, process tolerance, plating, material and flux/current class evidence remain unqualified; the 25 µm finished plating in `design/partition/pth-boundary-geometry-class.json` is a conditional project requirement. The independent 4.6 A current and redistribution budgets in `design/partition/contact-flux-class.md` are project requirements, with physical qualification NOT RUN (#57/#65).

References: `design/partition/source-boundary-lifting.md`, `design/partition/pth-source-boundary-geometry.md`, and `design/partition/contact-flux-class.md`.

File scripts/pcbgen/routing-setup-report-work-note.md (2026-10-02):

# Routing setup failure report lifecycle

Issue #23 requires a report for failed routing runs. On main 0673460, malformed retained JSON raised before the report lifecycle began, and an invalid heap bound left a previous ROUTED DRAFT report untouched. Pure temporary-fixture reproductions performed no KiCad or router work. The prior dense/native acceptance from #53 remains separate and unchanged.

The setup phase now starts after resolving safe repository-local board/report paths. Prior report parsing/type checks, board definition/load availability, router configuration and resource bounds either prepare a normal run or return a fresh PIPELINE FAILED DRAFT report. A setup failure explicitly marks DRC, parity, native connectivity and routing NOT RUN and leaves unmeasured counts null. Explicit zero bounds fail rather than silently selecting defaults. Valid routing/native results still use the existing mandatory final native gate.

Before replacing a previous report, its exact bytes are retained in a content-hash archive. If that archive cannot be created or conflicts with an existing artifact, the fresh failure report includes the prior bytes as base64 plus their hash and an archive-error diagnostic. Conflicting retained artifacts are never overwritten. Report destinations that collide with native CAD/net files, the selected board definition, or hardlinks to the board/project/schematic/net are rejected before writing. If the destination itself cannot be written, the command fails with an explicit stderr diagnostic; it cannot claim to have produced a fresh report.

Regression scope covers malformed/non-object retained JSON, resource bounds including explicit zero, absent previous reports, circuit-file collisions, archive conflict/permissions and an unwritable report. Setup failures must invoke no native checker, KiCad process or router. Existing native gate tests retain their statuses and coverage. No board geometry, component facts, copper, routing targets or retained dense/failed native evidence changes.

Verification receipts are recorded in the PR. Hardware, electrical, thermal, mechanical and fabrication qualification remain NOT RUN; all boards remain unvalidated drafts.

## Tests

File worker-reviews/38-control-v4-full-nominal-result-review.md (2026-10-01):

# P v4 complete nominal matrix — independent bounded artifact review

## Conclusion and limits

No concrete artifact/source/profile binding defect or unsupported acceptance wording found. This closes the bounded retained-result review only. The receipt correctly says NOT ACCEPTED: nominal finite-profile full-native diagnostic only. Physical contact classes, manufacturing/registration/material envelopes and common/private/K allocation remain unaccepted or NOT RUN. No actual source-current/terminal-flux, full physical 3D/primal, joined J/P/K or electrical-target acceptance follows.

No full solver, native run, mesh or field reconstruction was rerun. Checked actual retained files, source/native hashes, contact/profile identities and a small343×343 dense matrix consistency calculation with one BLAS thread. The latter is a floating diagnostic check, not a new outward numerical certificate. Root's guarded563s execution is separate retained evidence; receipt runtime536.577s excludes guard/process overhead.

## Exact bindings and basis

- Result: `.circuit-cache/issue38-recovery/control-feasibility-v4/ground-full-nineteen-v1.json`, SHA `d3c701ba9688011e31d253c167564967e8e496ece63493ea0801b1b924760a52`.
- Exact sidecar path/name and SHA `84e256396be65e616ed2a66dc94cf68f202f60a3328bc33e793872c2c5e426c2` matched.
- Native export SHA `977997bd280e438940f5b39916233e355f2834cb903845524bb50d33e1d693f9`; PCB SHA `781b2e2c9b6d28c103a644281334f4dbb0b07d2455a11ad9e6bf958f301b00b0` matched actual fresh P v4 artifacts.
- All43 model-source and111 native/source prerequisite hashes independently matched, with a final repeat check. Full P include-loads authority is True; unrelated K/J/peripheral/rail prerequisites are None.
- Sidecar/native/model/prerequisite/reference/layer metadata equals the matrix receipt. Exact ordered sidecar profiles equal matrix ports plus one final reference entry.
- Complete344 unique native/source contacts:214 fitted loads,127 GH,3 mains. All native UUIDs, kinds, physical foil memberships and main-component memberships match the current source inventory. Excluding actual reference TP990031:1/B.Cu gives343 balanced functions. No fitted P load or utility GH is omitted.

Every saved patch is valid, nonempty, finite and positive-area, and is covered by that contact's inward native analytic pad envelope. Three main patches each consist of19 disjoint0.24mm squares(total1.0944mm²); main_strands=True. This independently checks finite profile geometry within the pad, not manufactured support or a replacement for full drill/collar/source-continuity proofs. Minimum saved profile area is approximately0.04mm².

All195 barrel ownership UUIDs are unique and their count matches195 actual AGND holes in the native main component. All344 native ground contacts are retained in the mapping; source-free component omission audit is empty. The potential receipt explicitly labels the three maximum-wetting terminal restrictions as H1 trial restrictions, with no physical equipotential claim.

## Numerical receipt consistency

Both matrices are finite343×343 and exactly symmetric as stored. Independently calculated eigenvalues of sym(U−L) have minimum `3.229086209026091e-5` ohm and maximum `0.013558413096056786` ohm, satisfying the existing−1e−9 ohm diagnostic check. This checks internal bracket consistency, not mesh convergence or actual electrical targets.

| Mode | Maximum equation residual(A) | Maximum residual-work allowance(ohm) | Nodes | Triangles |
|---|---:|---:|---:|---:|
| Current | 5.906901731313595e-10 | 7.690057556796692e-7 | 282497 | 421225 |
| Potential | 2.2203694072404067e-9 | 9.473168966451175e-7 | 282982 | 422232 |

Both residuals are below the unchanged1e−8A gate. Both have43 batches and zero refinement corrections. Reported current physical-gate maxima: operator5.906901731305125e−10A; shared-face continuity5.906901731313595e−10A; sheet source balance5.551115123125783e−17A; barrel balance2.0435042547006788e−15A. These are read from the hash-bound producer receipt, not independently recomputed fields.

Parameters are adaptive coarse2mm/fine0.25mm, refinement1, origin[0,0], four physical/active foils and nominal material assumptions. No refinement/convergence, manufacturing, real terminal-current density or common-path allocation conclusion is implied by process PASS or the PSD-gap check.

## Principal model source hashes

- solve_conductor_volume.py: `3b8c536bfb2b92b3bef8959845b51543cfd3c5b4d3b9fedb73ca3ac1f58ed1de`
- control_model_entry.py: `d262936612c9d5ea5ba8226514800504b1c092c24808dbdf0323b40bd6f393d5`
- ground_volume_geometry.py: `94ff1bc7f7f315566cb401e016ba867cc61624a7891390cb9f09ea3385573b84`
- sheet_volume.py: `b9dd9579d0d79b34beaf867725f0076ab13a9a5b36498077a147272e9f8cc035`
- current_trial_matrix.py: `f5e1d92543b53bdaf181a6463de5ac1a95e2057ea3d0d01c47baf25f7afd3fd5`
- potential_trial_matrix.py: `0fcdaceada6df26f73a2dd60cda1236cec1fdb5bfcadd437d9b144bde06871e2`

No shared code or retained result files were edited. Review notes only; circuit:check PASS49 before writing.

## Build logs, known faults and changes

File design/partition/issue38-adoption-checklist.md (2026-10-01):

# Issue 38 source-adoption gates

Status: **OPEN / unselected source variant.** The canonical boards are unchanged.
Numerical diagnostics and native connectivity passes do not yet establish the
required electrical limits. All CAD remains an unvalidated draft.

## 1. Complete the numerical coverage

- [x] Source-replay native equivalence: JL/JR rule and parity errors zero,
  exact 507/475 warning identities, 599/553 fitted rail feeds, 214/200 complete
  bypass loops/feeds/returns, zero open AGND pads, and unchanged complete named
  signal-edge inventories of 1063/1109.
- [x] JL full nominal ground basis: 1176 profiles. The latest paired result has
  explicit original-current/new-potential provenance. Its unrestricted
  all-reference upper intervals are 0.497505 / 0.492558 / 0.511111 mOhm.
- [x] JL +5 full nominal rail basis: 59 profiles. R3306:1 is the worst full
  pad-to-main upper, 8.429654 mOhm, or 4.214827 mV at the full 0.5 A envelope.
- [x] Historical JL +12: the reviewed current refinement completes all 271
  profiles. Worst U1416:4 full upper is 5.124917301 mOhm. The actual shared
  IC/bypass exit then motivated source-owned parallel feeds.
- [x] Historical JL -12: all 269 profiles complete; worst U109:4 full upper is
  4.752883211 mOhm. These values retain their original geometry hashes.
- [ ] New parallel-feed JL/JR geometry: recompute applicable ground/rail
  witnesses. The 214 JL and 156 JR added vias change holes and fills, so none
  of the earlier electrical receipts is rebound to the new geometry.
- [ ] JR +12/-12/+5 full fitted-contact matrices and path accounting.
- [ ] JR full ground basis, including every physical load/observation/main
  contact and the source-independent UUID inventory.
- [ ] Fixed physical geometry/profile refinement and origin checks with a
  positive numerical margin. Do not change a physical contact when refining.

The smallest useful numerical improvement is to reduce demonstrated trial
error, not invent lower currents. In the actual 0.3 mm drill / 25 um barrel,
a local fixed-geometry diagnostic gives F-to-In1 upper/lower gaps of 0.141694,
0.098275 and 0.076956 mOhm for 2/4/8 radial subdivisions with other subdivisions
fixed. B-to-In1 gaps are 0.059826 / 0.043091 / 0.035633 mOhm. These are template
diagnostics, not whole-board results; they identify a concrete convergence
cost. Current row-specific work bounds are now available as well. Use the
full unrestricted load envelope first so resistor caps are unnecessary if a
tighter certificate suffices.

## 2. Select a finite material and manufacturing class

**Computation required before electrical acceptance:** define the actual
conditional class and evaluate valid upper and lower witnesses across it.
Nominal F/In1/In2/B copper is 70/140/70/70 um and the seven-band stack totals
1.6 mm. A valid class needs finite positive foil/dielectric/plating intervals,
maximum conductivity as well as minimum conductivity, and compatible drill,
etch/registration and collar/interface geometry maps. A minimum copper or
barrel thickness alone cannot justify the potential witness for thicker metal.

Do not promote the unselected 100 MS/m normal all-metal ceiling or a uniform
70 C hot floor to a guaranteed all-temperature class. Fixed-domain global
resistivity scaling is only an enclosure diagnostic: a +/-5% pointwise range
already widens the resistor-conditioned JL intervals to 0.508885 / 0.523013 /
0.542353 mOhm. This is not a physical failure and does not justify narrowing a
material floor to fit the target. Correlated material/process parameters or
more precise matched-domain witnesses must be represented explicitly.

**Later physical qualification (#65):** supplier/pressed-stack feasibility,
actual copper and plating, etch/registration, solder/process coverage and hot
measurements. No service is selected and no manufacturing claim is made. Any
as-built re-extraction obligation must be named separately from the finite
class actually proved by the design calculation; it cannot replace that class
with impossible zero tolerances.

## 3. Close the physical contact and current functionals

**Computation required:** the lower and upper operators must represent the
same actual source and observation functionals. Current numerical GH/load
patches are not a solder or lead-current guarantee. A 0.25 mm square cannot
be asserted to fit the nominal 0.2 mm GH lead width.

The preferred existing route is a constructive finite contact/wire class:

- Compose the nineteen supported main currents through finite solder, tips,
  fans, adapters and complete wires. Keep the continuous primal constant over
  the complete allowed wetting support. These are trial constraints, not an
  ideal physical pad or cut.
- Extend the same principle to actual GH and fitted-load interfaces using
  supported finite contact geometry. Preserve both minimum current-path
  support and maximum possible contact-metal extent. Include every finite
  transfer charge and possible passive contact shunt.
- Prove which resulting observable is common PCB/K spreading and which terms
  are separately paid private access/wire/termination costs. Do not subtract
  private uncertainty from an unrelated transfer interval.

A profile-independent continuum alternative needs a real finite-to-continuum
bound. Covering the pad with sample patches, a surface average, or zero net
terminal current does not alone establish that bound. Do not add another
whole-board nominal run merely to disguise this applicability gap.

**Current scope required:** map the normal signed branch currents to actual
source contacts, with every actual boundary flux included. The original 4.6 A
whole-return envelope applies to the sum of absolute load-to-balancing-source
coefficients, not to the L1 norm of the fully balanced contact vector. For one
+I/-I pair these norms are |I| and 2|I| respectively; 4.6 A of one-signed
returns plus its balancing source gives 9.2 A of full-contact L1. The exact
external incidence E and coefficient budget are defined in
`ground-network-composition.md`. Capacitive, leakage and permitted external
circulation coefficients require explicit mechanisms and total-variation
allowances; input rail caps alone do not bound them. Prefer circuit KCL,
source rail cuts and exact resistor/voltage mechanisms over planning currents.
If a local access cost needs a smaller current, establish that specific bound.

The example 75 V / operating R >=0.9 nominal resistor conditions bound only
resistive current. A total-terminal cap at the same value is a separate
unselected requirement, or needs additional quantified parasitic/leakage/edge
terms. The 153 exact source shunts preserve 112 x 100k and 41 x 5.6k values;
blank MPNs inherit no exact-part guarantee. Bypass, sleeve, input and IC currents
are not reduced by that example.

**Later physical qualification:** normal source/waveform realization #57,
patch/fault/transient limits #59, and actual material/contact/current behavior
#65. These links do not waive a computable design failure or imply fitted
current-limiting hardware.

## 4. Derive usable common and K allocations

**Computation required before #38 acceptance:** common branch plus K ground
spreading/shared neck/main transfer <=0.5 mOhm, with finite positive common
and private K requirements. The resistor-conditioned nominal JL screen leaves
only 0.016608 mOhm at its worst reference before K and class/interface additions;
that leftover is not an accepted or demonstrated feasible K allocation.

Use the exact K source port locations and intended conductor class to assess a
constructible allocation. The actual K PCB in #43 must then extract and verify
that allocation. GH proof must include all individual accesses once, all four
utility returns, and candidate PCB/contact resistance zero. The retained
alternative wire/contact allowance is +0.100 Ohm, not +0.010 Ohm. The joined
operator requires actual J-GH to K-GH observations and compatible full traces;
the algebra helper does not supply an ideal K board.

The retained K v7 full nominal ground calculation now covers 2,287 profiles:
1,903 fitted own contacts, 376 GH returns and nine main lands, with 219 barrels.
Its completed paired result and historical source scope are recorded in
`core-nominal-checkpoint-20261001.json`. Earlier v6/214-profile coupling screens
remain historical subsets. No result completes K rail/signal routing or the
physical/joined common-current proof. The four utility returns still require
P/rest-network coverage. Native connectivity supplies no resistance or
equal-sharing credit. The latest partition epoch changes one retained native
prerequisite hash; no old receipt is rebound to it.

## 5. Close every voltage budget with the same source scenarios

**Computation required:** combined common rail <=1 mOhm, hot distribution
<=20 mV and total source/rail/return <=0.20 V. Include all land/foil/shared-neck,
barrel, local pad/escape, wire and termination costs. Local access may be charged
at a supported actual branch-current bound or conservatively at its applicable
source envelope; it cannot disappear as a private zero term.

For +5, adding the full nominal 4.214827 mV JL access result to the existing
12.1075 mV baseline gives a conservative 16.322327 mV screen. This intentionally
takes no credit for overlapping common terms. It does not prove the separate
common-rail/K cap, material/contact class or omitted return-access costs.
The +12 and -12 scenarios have different original baselines (16.6275 and
16.345 mV); do not reuse +5 headroom. Keep worst single main return at 4.6 A.

The proposed finite whole-wire witness can be used only after its physical
class and matching traces are selected. Its shorter geometric path does not
permit unproved extra credits against its historical 125 mm / 13 mOhm per m /
0.2 mOhm termination model contract. The current partition separately selects a
110 mm maximum main-wire cut requirement and checks preparation allowance.
That new source requirement improves the conditional distribution arithmetic;
transfer it to a complete wire witness only after proving matching length
boundaries and traces. The physical wire/contact model has not been rebound.
The wire helper compares all 18 conditional registered-reference bounds
against the current source-derived 1.630 mOhm whole-wire budget. Approximate
margins are 0.223412 mOhm (JL), 0.247414 mOhm (JR), and
0.268324 / 0.269829 mOhm (offset / zero-offset P). These are not physical
acceptance: mean strand arclength does not establish a finished cut-length
class, and endpoint containment, terminal traces and material requirements
remain unqualified. The mechanical and electrical helpers now share the
[registered geometry](main-wire-reference.md), including solder height and
axial endpoint tangents. The historical 125 mm comparison remains separately
labelled; the global joined certificate remains open. A separate
[individual-core certificate](individual-wire-cores.md) now checks global tube
injectivity, core separation and each registered reference length including
solder and preparation. Its worst reference allowance is 103.944852 mm;
actual containment and finished-cut qualification remain open.

## 6. Promote only the proved source and refresh all receipts

- [ ] Parent records the exact selected plane/stack/contact/current/class and
  downstream #39/#43/#57/#59/#65 contract deltas before canonical promotion.
- [ ] Regenerate the selected source and canonical native boards through the
  pinned KiCad 10.0.6 oracle; preserve fixed hardware, prior copper, owner style
  and every explicit retirement receipt.
- [ ] Bind electrical models to the final board/native/project/definition,
  source/current/profile/operator and model hashes. Reuse only explicitly
  proved physically identical inputs, never a blind hash substitution.
- [ ] Refresh native full named signal edges, warning identities, exact source
  placements, power/return inventories, renders, source documents and reports.
- [ ] Run required affected checks and foreground self-review; commit only the
  concrete reviewed result. Remaining routing must be precisely bounded SIGNAL
  routing with the issue-policy follow-up, not a power/model waiver.

The current critical path is physical-function/class applicability plus a
meaningful common/K certificate. Additional nominal matrices provide coverage
and expose concrete access costs; they do not by themselves close that path.

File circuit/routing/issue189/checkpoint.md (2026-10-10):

# Current continuation — 2026-10-10 02:49 UTC

Canonical **JL118 / JR134 / core1441**, zero native DRC/parity errors; warnings remain. Main bf2daa9a62d3ce173363b5f3f25211965926fc02. Issue189 stays OPEN. PR220 branch agent-fix/189-jr-neighbour-pilot contains this correction; no board changes.

JR full-warning38016800065 at86a4233a01a2244a16c8eabe65821e5e1de9a46b is TERMINAL REJECTED. Bot386760705321ae33da416fe59e55e690199aeb5a adds two receipts only. Artifact11656548075 SHA256eea30c08925c060754a521868ef8f8b3766864bb2237d1efcd2212b8e7ca3dfd independently reconciled (guardPASS97s):134→133/fresh133,0DRC/parity, all51177old objects+79new,zero cuts,1080nonrouting objects unchanged. Both hole results exist; silk only started, zones did not produce a result. Exact failure: mask auditor hard-coded382copper/38vias. Raw gate eligibility does not override missing complete warnings. See jr-neighbour-return-repair/full-audit-rejection.json and reconcile_rejected_full.py.

Correction derives exact additive UUID/type scope from both source boards, rejects old copper changes/removals and ambiguous new UUIDs (retained historical duplicates allowed), writes source-SHA-bound scope manifest, and passes exact counts to native audit. Native objects must match the source scope. Legacy standalone defaults remain382/38. Every mask fixture, native version, text/context, report cap, holes/zones, original findings, retained copper and promotion gate remain required.32 targeted regressions pass. Both exact saved native source pairs also pass the scope regression (guardPASS77s): JR79/5 and core382/38, pinned archive and before/after hashes, complete UUID/type maps in saved-source-scopes.json. This is source coverage verification; new native acceptance is NOT yet run.

**CI approval blocker:** exact bot-head run38017605765 is action_required with zero jobs. Its GitHub page says “This workflow is awaiting approval from a maintainer in #220”. No approval or replacement CI dispatch was submitted. A repository maintainer must review and approve the pending workflow in https://github.com/Takazudo/zudo-osc-hole-field/actions/runs/38017605765 (or the current pending PR run after this reviewed fix). Do not bypass this gate. Source86a4233's all-five successful CI38016779017 does not cover bot3867607 or this correction. See ci-bot-approval-required.json and ci-86a4233.json.

**Sole core writer38011194282 remains active at44d1151cd41f285d5168c433c76664c44a3d97ac / PR218; do not duplicate, cancel or push its branch.** Other concurrent session refs remain unchanged. Preserve its terminal output even if rejected. The independent full-adoption checker is /tmp/issue189-reconcile-full-adoption.py; it is prepared, not yet executed on this run.

Next JR replay, only after verifying no active JR writer and resolving applicable workflow approval, uses the corrected immutable branch head:
`gh workflow run routing-benchmark.yml --ref agent-fix/189-jr-neighbour-pilot -f board=osc-jack-right -f replay_jr=true -f jr_replay=d7604-return-joint`
This starts all native passes and all four fresh audits with zone batch16; never use cached pilot evidence for adoption. Record exact run/source immediately and own it through terminal reconciliation. Compare artifact, receipt, retained copper, complete reports and bot blobs; require all five exact final-head checks/current base before authorized integration. /tmp full-adoption checker's JR run/source constants must be updated to the actual new run first. Keep original rejected receipt in history. No router budget increase, physical/electrical requirement change, Docker retry, recurring automation, fabrication or qualification.

---

# Current continuation — 2026-10-10 02:22 UTC

Main `bf2daa9a62d3ce173363b5f3f25211965926fc02` merges PR219 exact `c393ea416877950a064917a1c7f46b1a6b6ff8d9`; exact38014043304 and post-main38015093504 both pass all five checks. Canonical boards remain **JL118 / JR134 / core1441**, zero native DRC/parity errors, warnings remain. #189 remains OPEN; no qualification/fabrication claim.

**Sole active core writer remains38011194282 at44d1151cd41f285d5168c433c76664c44a3d97ac, PR218. Do not duplicate, modify or cancel it.** All complete audits and native gates must finish; cached1402 evidence is not canonical. The earlier checkpoint below gives exact artifacts and reconciliation order.

PR220 (`agent-fix/189-jr-neighbour-pilot`) preserves20current-input signal probes and a rejected three-case pilot, then prepares one explicitly repaired transaction. Rejected38014685459 at4c462ea:134→135 with original -12V/AGND splits, all51177old objects+118additions,0DRC/parity, no fresh check. Artifact11656065119 SHA25689d3b9b245998063c77e031190bd123e5b2abcb868129773626e75e5b57eb2d1; independent guardPASS45s. Do not replay the three cases unchanged.

Changed joint pilot38015774133 at0867a05a01f321d890847c5fa4b1bd6a8d6e866d passes baseline134x3/candidate133x3/fresh133x3: D7604.1–D7603.1 plus explicit U7607/C7615/C7622 ground return, all51177old objects retained+74segments/5vias, zero cuts/moves,1080nonrouting objects unchanged,0DRC/parity, no splits/new raw warning identities. Artifact11656122445 SHA256a42f92f62ba59b71b9321e0e1dce50e47c468ef5039c5fc49c5b236744ca9365 independently reconciled (guardPASS75s). Candidate22189b127579271b2f2c219da5e4b7e2af59673cb04e002b0dc4966afe2170dd and replayc4b7910f964b56f9231bf6dd3e21b07b4ce8c8bbca430f09f80ea08acdd34411 are **NOT canonical**. Complete silk evidence is still required because both raw categories cap at199.

This source prepares the dedicated `jr_replay=d7604-return-joint` fresh adoption with mandatory `--complete-native-warnings --native-zone-batch-size 16`, all original native/retention/publication gates and120-minute command bound.28 focused workflow/merge/warning tests pass. Before any dispatch, inspect PR220's current body and branch run list: **if an adoption run is already active, own that run and never duplicate or push over it**. Exact active run/source are recorded in the PR body after dispatch. A successful workflow alone is not adoption; reconcile complete fixture/report/context hashes, original groups, native counts, exact retained/new copper and bot blobs, then run all five checks on the final resulting head and current base before an authorized incremental merge.

Optional owner bundle is local `.circuit-cache/issue189-owner-pilot-20.zip`,19,200,162bytes, SHA256866d48c077fd38012efce88d58d7b694c6378879369395b0656b90c84a975227.209files/20signal-component pairs with exact accepted board/project/rules/schematics/libraries/native evidence/endpoints/failure traces; manifest verified. No human pilot performed. `jack-post-adoption-neighbours/bundle.py` reproduces it. Keep ZIP local/ignored; no LFS.

Continue bounded JL/JR/core work after terminal reconciliation. Full connectivity and final P/EL/O/regeneration/docs/renders remain unmet. Local pinned-image extraction remains blocked under214; supported native CI is available. No more Docker unpack/cleanup/auth/daemon changes or recurring automations. Do not restart unrelated watches.

---

# Issue 189 current checkpoint — 2026-10-10 01:33 UTC

**Issue #189 remains OPEN.** Canonical native connectivity is **JL118 / JR134 / core1441**, each with zero native DRC/parity errors, settled/fresh agreement and no original pad-group splits. Warnings are not zero. No qualification or fabrication claim is made.

Main is `fab639d790e453d4ff7af4a61d896f83730edf6f`. PR217 merged exact `c9d11adf4f302760bd82574ebd5019ce5a79c767` after all five checks in38008620676 passed; post-main38011121272 also passed all five. PR217 adds opt-in native paired zone batches, strict complete-evidence consumption and source-bound exact resumption;46 focused regressions passed. No canonical PCB changed.

## Sole active core writer

Draft PR218: https://github.com/Takazudo/zudo-osc-hole-field/pull/218
Branch `agent-fix/189-core-batched-warning-worker`, immutable source `44d1151cd41f285d5168c433c76664c44a3d97ac`.
Run https://github.com/Takazudo/zudo-osc-hole-field/actions/runs/38011194282 began00:57 UTC and remains in native recovery. Its command bound is335minutes, job355minutes. **Do not duplicate, cancel, modify or push to this worker while it runs.** All four complete warning audits rerun against this worker's exact native boards with zone batch16; no cached proof substitutes for acceptance. Initial source CI passed all five, but this does not certify a future bot commit.

The proposed1441→1402 change retains all133169 previous copper objects and adds344segments/38vias, zero cuts. The candidate is NOT canonical. Terminal reconciliation must verify source/artifact hashes, three settled baseline/candidate/fresh passes, all original pad-group memberships, zero DRC/parity errors, complete holes/silk/zones, warning identities and publication equivalence. Workflow success alone is insufficient; require the receipt's adoption result and exact published blobs.

## Completed independent warning evidence

Original core37984573591 was rejected with incomplete zone evidence (exit137, cause unknown); no PCB changed. Its exact artifact11650664778 has SHA256 `b5c112a5c9336a27cb08369ec42a11b7cc51a39bb569215d24075ccd3ab11567`. Reassembly/reconciliation is preserved under `core-complete-terminal/`.

Read-only paired38005209241 timed out after35/42batches. Exact continuation38008640020 at `ca1e681b7905dc76d735adff1582dab3c79c3569` completed all42 (35 exact reused,7 fresh), covering both stages of all144front/177back selected items with zero new zone identities. Artifact11653113141 SHA256 `f63fff8145c2033a7ab0d3da38f49e1aed6ff735f80aaafbf3cd435f6c8d9cd4` passed independent complete validation (guardPASS124s). Combined unchanged promotion-gate evaluation also passed (guardPASS330s): all1407hole identities and382added-copper silk fixtures retained,619original findings extended additively to1827each, no new identities or splits/errors. This is exact saved evidence eligibility, explicitly NOT adoption. Full receipts and replay scripts are in PR218's `native-zone-paired-batches/`.

Same16saved native fixture timing: single638.280514482s, batch4 174.569181217s, batch16 57.869251212s. Native positive controls preserve both injected identities and negative controls remain negative. This is an audit timing improvement, not a router speedup claim.

## JR changed-method results

Draft PR219: https://github.com/Takazudo/zudo-osc-hole-field/pull/219
Branch `agent-fix/189-jr-paired-placement`, evidence commit `eb4eb0a7fd1e269495e02a16008a050d5a135a1b` (checkpoint may advance it). No board/source placement changes.

Paired movement:1152 joint cases screened on identical saved JR134 inputs;40 static candidates. Twelve round-robin proposals tested direct/plane (24 bounded trials):zero complete,18search_exhausted,6no_legal_via_site; max43623 expansions of300000. The remaining28 static candidates are untested, not negative. Anchored90/180/270-degree rotations:27 cases,zero viable candidates. Four source-legal poses have foreign pad/via blockers; no small track-only restoration scope. Exact integer native/source centre binding handles the recorded1nm conversion effect without widening tolerance. Preserve negative evidence and change diagnosed cause/method before repeating; do not implement a source rotation or native pilot without a qualifying proposal.

Plane-fanout follow-up: the default hard-coded3mm window omits legal6mm via sites in the saved failed cases. An opt-in `plane_window_mm` retains the default and all constraints. Identical unchanged R8490/RB4615 comparisons at3/6mm produce zero complete routes;6mm searches exhaust21187/43982 states below300000.32router+15bounded/driver tests pass. `jr134-plane-window-diagnostic/` preserves hashes and results; no native pilot or geometry change is warranted.

## Exact continuation order

1. Refresh main, PR218/219 and concurrent branch heads before any adoption. Preserve unrelated work. Do not rerun the already consumed personal loader or attempt local Docker unpack/cleanup/auth/daemon changes. Supported pinned KiCad10.0.6 CI works; local image storage is still blocked under issue214.
2. Observe `gh run view 38011194282 --json status,conclusion,jobs`. Once terminal, obtain its exact artifact and native receipts; reconcile all gates above and the bot's published file blobs. Do not equate workflow success, cached1402 evidence or source CI with adoption. Keep the worker branch frozen until terminal.
3. For a successful adopted result, integrate only exact accepted copper/receipts into current main on an isolated review branch, preserving intervening copper and excluding worker-only workflow changes. Require all five exact resulting-head checks and review before an authorized incremental merge, then verify post-main checks. If rejected, retain exact native failure identities and change the cause/method, never waive the gate.
4. Only after terminal reconciliation, evaluate the prepared `core-supply-away-from-splits/rebase_proposal.py --accepted-sha256 ACTUAL_ACCEPTED_SHA256`. It requires exact known whole accepted additions and preserves all copper. Against the known ground382 additions it excludes the entire conflicting U4439.4 proposal, leaving93cases/118segments. This is not native acceptance. Use one isolated subsequent core writer with all full native gates; never overlap writers.
5. Continue JL/JR/core bounded routing to zero, final required P/EL/O/regeneration/docs/renders and repeated native evidence. The rejected JR source move RB4413[0,-0.2] violates header courtyard clearance (0.06<0.25mm); do not replay/apply it. Fixed panel/electrical constraints remain unchanged. Keep #189 open until all completion criteria, and keep all designs explicitly unqualified drafts.

---

# Historical checkpoint (superseded by the current checkpoint above)

# Issue 189 exact continuation checkpoint

Updated 2026-10-09 23:22 UTC. **Issue #189 remains OPEN.** Main `b850687830eb2a4c31b14f138aacf2288d223c81` accepts **JL118 / JR134 / core1441**. PR215 merged exact`5420104c164d748d8094bfd76761d01ab2ed7b92` after all five checks passed in38002434995 (`ci-5420104.json`). Post-main38004002105 is pending. PR213 exact803bba6 attempt2 and post-main d644b52 also passed all five checks. CI pinned-native access recovered; local image storage remains blocked. No canonical copper or source placement changed in PR213/215.

JR source pilot37999678014 at`acabdda6118fde6623defe811a0493ba3eeef830` is **REJECTED**: it reproduces ordinary nativeJR133, then partition regeneration finds J900069/RB4413 courtyard clearance0.06mm<0.25mm. Artifact11649741925 ZIP`d22721f7545bf34ef439805c6dbe61d8e78f1368b21478e7dc7051b2ff8acce7` is independently reconciled. Do not apply the partial source patch or rerun that move unchanged. Source sync/further native repeats did not run. Every canonical PCB still matches the inputs. Connector preflight now rejects the real case;14focusedtests and floorplan--check pass. Identical savedJR134 inputs:15,120 moves screened,30→26static candidates, no new candidates. RemainingRB4413 moves plus controls fail all6direct/plane comparisons. See`jr-source-adoption/rejected-receipt.json` and`jr134-movable-ground-connectors/summary.json`.

**Active ownership:** preserve sole core writer37984573591 at`a89ff33adc26675b7cdf2f22616dcb1a9826cb59`; no duplicate/cancel/change. Its335-minute command bound ends around01:40UTC Oct10. Reconcile its terminal ZIP/source/context/fixtures, full warning coverage, original pad groups, settled/fresh native gates, all133169prior objects+382proposed additions, and any published blob before adoption. Workflow success alone is insufficient.

Read-only native zone timing comparison38002541870 at`b19d387d62bb2a016638efff740051b8a0f15eb5` is running (native step23:05:06UTC,40-minute bound). It compares1/4/16batches on the same16saved before-board fixtures. No publishing step; not complete paired zone evidence. Independent reconciliation is prepared in`native-zone-batch-probe/reconcile.py` but NOT RUN until a terminal artifact exists. The134saved native fixtures have no zone-linked positive findings. Separate F.Mask/synthetic-silk positive/negative controls are prepared on`agent-fix/189-zone-batch-controls` (initialec3345c, now refreshed to main);11unit tests pass, nativeNOTRUN. Run once with10-minute bound only after the timing probe demonstrates exact identities and at least2x improvement. A missing positive must fail. Production acceptance is unchanged. Full connectivity and qualification remain unmet; no fabrication claim.

## Active work and hard gates

- **JL adoption37978945582 completed and independently verified**, isolated branch `agent-fix/189-jl-r8276-adopt-worker`, source `8b0a7701a680a9df7fd3272c4749365a5911ad74`. Bot534dd3e60985799502420dd326fe41bca9e15875 cherry-picked asd50853d3d56984c204c45ae5918dfa87d8956fee after exact3file blobs matched the SHA-verified artifact. Temporary worker-only workflow is excluded. No jack writer is active.
- **Read-only zone classification37976003780** was cancelled at its90minute job limit, and partial upload failed on a disappearing KiCad lockfile; no artifact exists. Source `bacd089f36a12d839a96cb6888640918cefe1e35`, worker `agent-fix/189-complete-silk-worker`. Same-input serializer-optimized comparison37983410773 timed out at its80minute bound at `d19bfa4bbcd91ee7534818d4e705f753d3d00a31`, worker `agent-fix/189-zone-classification-fast-worker`. It uploaded artifact11644814747, ZIP925d83879571b2127af73526ead4cef86472138f3093fc909dfcf19a22f54c1b:134completed before-board reports,135exact project/rule pairs, no completed paired coverage. ZIP and context are independently verified. Neither run publishes copper. Preserve the terminal receipt and inactive batching probe on `agent-fix/189-zone-batch-preparation` at821cffa66ecb2d0eb9bcedfaa71b8eef75ce34bf; eight focused tests and16byte-identical offline fixtures pass, native batching was not run at that historical preparation; active comparison38002541870 is tracked above. The saved core1402 candidate remains provisional until complete native warning evidence passes.
- Core19run37965185751 is terminal and rejected, fully reconciled below. Remote active/queued runs were reviewed at20:02: no competing core writer. **Sole active core writer:37984573591**, branch `agent-fix/189-core-complete-warnings-worker`, immutable source `a89ff33adc26675b7cdf2f22616dcb1a9826cb59`, uses exacta0e3cff1; rebasePASS20s preserves all133169prior objects and382proposed additions. It will generate every complete audit before the ordinary gate may publish on its isolated worker. This safely moves evidence collection inside the mandatory pre-publication gate; it does not treat the old provisional reassessment as eligible or skip any check.
- CLI API authentication expired at19:08 and recovered after host runtime refresh at19:25; a harmless repository API read succeeded. Git/connector access remained functional. Same container and snapshot verified; bridge already valid; loader not repeated. Regular workflow dispatch is available again. The temporary JL worker push trigger retained identical gates and is not part of PR211.

Parent steering at18:34UTC explicitly authorizes incremental merges once exact gates pass and requires core19reconciliation before a ground writer. Preserve other sessions and all branches. No unrelated watches. Previously checked other-session heads: `core-rrr-escalate`8315af554132b283e4e6e9b62d76bbfdcea560c0, `jack-replace-region-2`30db43e0c63cc4e380fd1525e74e76d27d8b0694, `jack-replace-jl-1`470b3f0e074b7f1254b529c58932e57ed456d195. Refresh them before any adoption/merge.

## Merges and validation

PR211 merged as835f4036c82aed4333f6323cf8571f085d1d767d at19:49UTC after all five exact-head checks37980437155 passed (`ci-57aa524.json`), with clean state and no comments/reviews. Other-session refs were unchanged immediately before merge. All five post-merge37982818544 checks passed (`ci-main-835f403.json`).

PR209 merged head2c3afdedf9e999ef0b091db74805d10fc5687d44 as98820acfefa293f7c2558aacb2059d3de8da5ae8 after all five exact-head checks37972341588 passed. It adopted JR134. Its post-merge run37975245292 was cancelled/superseded, **not passed**.

PR210 merged heada95f936cca551742267e36dde9276a8b813739f1 as2ca29f2550366d5b31f6eb2ce9dbdbfd9a6b27c2 after all five exact-head checks37974947048 passed. It changed verification, not canonical boards. Post-merge37977274128: all five checks passed, including native regeneration (`ci-main-2ca29f2.json`). Exact-head receipts are `ci-2c3afde.json` and `ci-a95f936.json`. Earlier main4db1d3c all-five post-check proof is `ci-main-4db1d3c.json`.

## Accepted immutable boards

| Board | Published SHA256 | Latest accepted evidence |
| --- | --- | --- |
| JL118 main | `a01df89dcab3d4fab8eb0ae80195b2825d2d47adc517cd73452d9b9aa6ea079a` | 37978945582:119→118,+75segments/2reviewed cuts,all33346uncut objects identical |
| JL119 historical | `554fa85a44d74c2ad2105e34f1bbc4de9b674e46dd7531ddc3e00c6d8e1c1291` | 37960073108:120→119,+58segments/4reviewed cuts,all33290uncut objects identical |
| JR134 | `35b52972dd70b4186cf3f3b7ee2ac3d70432f3476c2f56c9fcf9c1c4d7d4d445` | 37967123290:135→134,+37segments/5reviewed cuts,all51140uncut objects identical |
| Core1441 | `a0e3cff1ebc211564b8be10f6a993d50fb6d4372edde86a056ebc8dda3ea5932` | 37895925149:1509→1441,+216segments/zero cuts,all132953original objects identical |

All three have0native DRC/parity, no new reported warning identities, no original pad-group splits and fresh agreement. Reported warnings477/520/619. Native10.0.6 is pinned by `scripts/kicad/run.sh`; local9.0.2 is not acceptance. Fixed panel/placements/pads/outline/rule areas/layers and project/rules remain unchanged. Jack rails are fully joined. JL103signal+15AGND; JR111signal+23AGND; core80+12V/80−12V/252AGND/1029signal edges.

JR134bot a59ef3669cdac3d6ca31131722c082aefd92b507, cherry133f2f6; replay3c3495b6442d463366c39ccdee4c010f9ca3c030cb321cda4d1780c4a6971c61; artifact11633969149,ZIPafa07c7a1c2315162bcc62fa780a0e6e805f0082c4f59e5739ec000a097b8b5a. Proof `jr-c7413-endpoints/`.

`retention-ledger-d50853d.json` uses full-object multisets including legacy duplicates. From issue baseline: JL32607original retained/138reviewed changed or removed/814new; JR50287original retained/24reviewed changed or removed/890new; all132953original core retained/216new. Latest stages preserve every uncut object. Do not claim all original jack copper survives.

## JL118 native adoption verified and integrated

Pilot37976521780 atd1dd53fea72278434ae40e6ef4c4d02ac2c54afd:119→118,+75segments/zero vias/2reviewed cuts,all33346uncut full objects identical,33348→33421. Native0DRC/0parity,477unchanged warnings,no original splits,fresh agreement,physical/context invariance. Candidate `a01df89dcab3d4fab8eb0ae80195b2825d2d47adc517cd73452d9b9aa6ea079a`; replay `b1678187a5365202fe12a97e80ff4f33bc264a0616b8269af0ffa84aaa253f67`. Artifact11639497498,ZIP0d643e9bfa906f9f45f2daa8ec87835a64ca2ec8c05bbc9ad2d3071fb5fd12b6.

`jl-r8276-joint/` contains proposal, native pilot, full retention proof, exact source/UUID preparation and adoption plan. First reserve the permanent AGND join, then restore both actual native cut victim groups within the same14.9×16.45mm frame, F/In2/B at0.0125mm/300k. The earlier cut-and-restore pilot37973959441 was119→119 and rejected; the changed joint method is material. Adoption37978945582 reproduced both hashes and all native gates. Artifact11641021167,ZIP83335f6ba6e189458a6d5b66caa5ba0f96590a7838dabaf92f6d5b7f70f56610. `reconcile_adoption.py` passed under the guard in8s: all start/merge/fresh DRC/parity0,warnings477,exact physical/context invariance and full copper retention. Published candidatea01df89d is now on main viaPR211/835f403. All five post-merge checks passed.

## Native zone geometry profile and audit runtime

Read-only profile37983217779 at661f96a584e2944354725852a66935ee1c621ccd passed on four immutable native10.0.6fixtures. All source/fixture geometry is equal under both bidirectional native Boolean subtraction and exact native-coordinate fingerprints. Each1nm vertex mutation is detected; all shapes havezeroarcs. For420374–441282vertices per zone, old comparison1.40–1.88s versus fingerprints0.066–0.074s. Artifact11641402938,ZIPa53de5ab09df60f59ffb6102c3c67d90c0b30b6f123efa4433cabf65c5820686; all fixture hashes/context independently verified. See `native-zone-profile/` for primary-source hashes, results and scope.

Future audits use exact native-coordinate fingerprints and reject arcs because the native formatter omits them. Receipts bind per-stage source/fixture fingerprints; regressions reject unsupported arcs and mismatched signatures. Native DRC classification, full pair coverage and all ordinary gates remain unchanged. Progress scope/JSONL receipts are diagnostic only, never complete acceptance.26focused tests and100affected router tests pass; circuit/documentation checks pass.

## Core19 rejected and reconciled

Run37965185751 at08aec29e83d24d291f4d41a7bb10300e072a7260:1441→1432 rejected. All133169old full objects unchanged,+19outer segments/11nets/zero cuts or vias.0DRC/0parity,619unchanged warnings,fresh agreement. Original1928-padAGND group splits into1/1/2/1924: J900311.2, C4445.2, and U4606.5/C4623.2 isolated. AGND252→255. No board adopted.

Candidate40ace01e555e637a1faa369990fecc715ba8ee9b49dd5d717fddef004ddf8233, replayda1d5262b945e51aa45eb500e1296efd2324d515b164132c4da9e36cec67cf49. Artifact11638511202,ZIP60524fca152e069c17d8880e0a740df9b6a082273f7a879a88764d17f509e414. `core-short-no-via/{reconcile.py,retention,artifact}.json`. Bot9ac2677 contains exactly two receipt files, both whole blobs matched verified artifact; receipt-only cherry7028f17. Do not retry unchanged. `core-short-no-via/split-proximity.json` measures nearest new copper4.95–7.22mm from the four split pads: a3mm exclusion would miss them. `core-short-split-filter/` holds8whole cases/13segments after excluding the three closest transactions; this is a hypothesis only, not causal attribution or native acceptance, and must rebase after the current ground work.

## Complete core warning evidence: provisional, NOT eligible yet

Saved run37950004600:1441→1402,AGND252→213,+344segments/38vias/zero cuts,all133169prior objects retained.0DRC/parity,no original group splits,fresh agreement. Raw gate rejects a newly reported pair of unchanged old vias because native warning domains cap at199. Candidate `b9f5ca13f83c7ffdbe5836fd271e7c1099e04b901ca1798a7be06f025bd02d66`, replay25a3de5583c9bb61611a4e46d9463a581a09cba43c1dc23bf2d45c5203a3b08c. Artifact11631867897,ZIP8919c769bba2f17fc3d695a80590f6e75e618d8767f464baf2d39fb027ca90d6. Baseline native-filled hash95c815b2178511621f97cd7021938023b96d4ee19c9282ae99b35fb387ba10c5. Canonicalcore stays1441.

Exact10.0.6 source proves hole and both silk domains cap at199, and native silk checks include tracks and outer filled zones. `native-hole-audit/silk-scope-sources.json` pins URLs/hashes. Complete scope requires all of the following:

1. **Hole audit37972238437 PASS**,source2c3afde:9815/9853holes,128fixtures each,1407identical UUID and geometry-object identities,zero new/removed. All256raw reports and exact project/rules independently verified. Artifact11637606039,ZIP48c8b07dea13eeb4f2e257908e2ee49a80e460e6582e011a5d57cf8047d3e8db. `context-*.json` authoritative. Earlier37967430188 is invalid-context diagnostic, not acceptance.
2. **All382added-copper audit37975999346 PASS**,sourcebacd089:344segments/38vias,zero new silk_overlap/silk_over_copper identities;maximum80/0reports below199. All382raw report hashes/contexts verified. Artifact11639436792,ZIP9a3cd7c803a956cc5d5d82c426543f3f9717b6b4994dac0620dd3e2b6c7ef5f0. `all-copper-silk-{result,artifact}.json`. Earlier38via audit is partial and cannot establish complete scope.
3. **Zone classification37976003780 INCOMPLETE/NO ARTIFACT** (90minute limit; upload ENOENT on temporary KiCad lockfile). Optimized37983410773 also timed out; its verified artifact has only134before-board fixtures and is not acceptance. Growth-only37975143005 proves F.Cu grows25.535mm²/four regions and B.Cu23.415mm²/six regions. Metadata/outline unchanged; shapes are not subsets. Artifact11637879760,ZIPf676bb4b70145249e9f948df1410bc4749fbb20cc5c53aa6d44b752166b804a4. Current paired fixtures retain complete native zone shape and exact context, select conservative native bounding-box artwork near growth, and compare uncapped native identities.

`complete_native_warnings.py` fails closed on missing/stale/incomplete evidence, changed context, new native warnings, unsupported domains, missing copper or zone scope. It only appends complete hole observations and removes no original finding. Ordinary DRC/parity/membership/fresh/source-publication gates remain. Opt-in `route_shards.py merge --complete-native-warnings` regenerates all audits on actual sources. No core board has been adopted using this option. Conditional validation37984573591 is active; it must generate and pass all audits before publication. The saved core1402 candidate is still provisional.

`reassessment-before-zone-scope.json` is explicitly provisional. Current `reassessment.json` records the zone-scope block. Updated `reassess.py` expects both full382copper and zone classification evidence; do not run it against old partial evidence. 25focused audit/workflow tests and100affected router tests pass; `pnpm circuit:check` and `pnpm check` pass. A new serializer regression also passes. The exact saved-input fixture benchmark produces byte-identical outputs: two fixtures per source take11.106→7.125s and10.776→6.770s; no native acceptance is inferred from serialization timing. See `zone-fixture-benchmark/`.

## JR rejected successor and changed-method controls

Run37974220440 atb3ba58e8e4c1363efe08e55324cecd68455c9625:134→133 rejected,+22segments/2cuts,all51175uncut full objects identical,0DRC/parity,522unchanged warnings,fresh agreement. AGND joins improve but original X67A5B6E02FA33495DE9E splits: R7628.1/R7627.2, native groups4/58. Candidate d8765ecc82f188e7302ea4525b2aa446ac4aa68e4cf92b06e0577f837d02ab0b; replaye1e3011e587df334a6a44782311f526b70a08bb3d931c2ca14add11ffe257d57. Artifact11638981471,ZIPed1c64bb976d116756344c672d7743e8df811236f7df235b04bb24d488ce9f4b. `jr134-rb4614-2-ground-cut/` full proof.

Explicit endpoint routing at0.025and0.0125 finds no path; joint permanent-ground-first restoration at0.0125fails both declared victim orders. `jr-rb4614-endpoints/`, `jr-rb4614-joint/` preserve negatives. The additional `jr-rb4614-plane-joint/` control restores signals first then attempts explicit In1 AGND fanout; both declared orders still fail X67A5B6E02FA33495DE9E (guardPASS12s). No partial proposal submitted or unchanged-budget retry. JL C8142 joint/fanout and R8127/R8276 bounded source-defined move comparisons also preserve negative controls; no actual placement moved.

## JL118 source-defined movement controls

`jl118-r8127-placement-screen/` expands physical translations to±2mm at0.1mm steps:1,680cases, only the same seven feasible moves as the older±0.8mm screen; no unchanged route rerun. `jl118-movable-ground/` screens seven other source-defined movable resistors outside bypass clusters,1,680translations each, unchanged orientation/side, fixed outline,0.35mm source courtyards,0.25mm copper and full0.2mm signal landing bridge. R8105/R8173havezero static candidates; R8273/RB2214/RB2315/R8270/R8107have1/4/8/10/86. All228direct/plane-fanout comparisons including unmoved controls fail (guardPASS697s). A changed-target R8107→actual isolated R8105group comparison also fails all87cases (guardPASS280s). Diagnostics are exhausted searches/no legal via sites, not expansion-limit failures. No footprint moved, no copper changed, no native moved-board acceptance claimed. Preserve results and do not repeat unchanged scopes or raise the budget.

Future standalone zone-audit steps now have an80minute command timeout inside the90minute job, leaving time to upload incomplete evidence. This does not alter the active old run or classify incomplete evidence as passed.

## H1/H2 and identical-input benchmarks

Baseline1fe06ad50248d6434876fbf2bd6e32e1bfbb13bb. `hypotheses-before.txt` reproduces ghost drill occupancy after via removal(H1) and soft traversal through an immutable foreign pad(H2). Fixes/regressions are merged. Paired saved native inputs:

|Board|Old result/wall time|Fixed result/wall time|Acceptance|
|---|---|---|---|
|JL|140→140/325.5136s|140→139/328.8692s|one accepted edge|
|JR|162→162/327.2931s|162→162/321.9534s|no gain|
|Core|1509→1499/3545.3150s|1509→1499/4729.8022s|both rejected for2AGND splits|

No speedup claim. Immutable inputs/toolchain/source/results: `jl-benchmark.json`, `jr-benchmark.json`, `core-benchmark.json`, `benchmark-artifacts.json`. Later bounded raster optimization is separately tested; it does not imply whole-router speedup or native acceptance.

## Workspace recovery and continuation

Execution recovered at20:17UTC on October9. The local checkout was clean at a89ff33 and safely fast-forwarded to ffbe6698. Runtime snapshot a4fd2a5b and its instruction bridge are valid; no managed links needed restoration and the already-consumed loader was not repeated. A fresh saved-environment task is not needed. The earlier transport failure was real but is no longer blocking.

PR212 merged exact headffbe6698 as c1de561 at20:31:58 after all five checks37985352173 passed (`ci-ffbe669.json`). Main and all other-session heads were refreshed immediately before merge; no comments/reviews or concurrent-head changes. All five post-main37987629750 checks passed (`ci-main-c1de561.json`). The other-session heads above are unchanged and PR212 has no review objections. The sole active core writer37984573591 remains unchanged. Read-only zone audit37976003780 terminated at its job limit with failed artifact upload; optimized audit37983410773 remains active. No pending result is acceptance.

New isolated branch `agent-fix/189-jr-movement-continuation` preserves bounded JR134 movement comparisons in `jr134-movable-ground/`; these do not alter PR212 or worker refs. Static screening is complete (15,120 translations,30 compatible candidates across seven of nine eligible resistors); route comparisons completed:67trials,66negative and one complete virtual RB4413 route at[0,-0.2]mm, six segments/one via. Its unmoved direct control failed. No component or copper moved. `jr-rb4413-move/` pilot37986929982 is terminal/rejected and independently reconciled (guardPASS25s), isolated worker `agent-fix/189-jr-rb4413-move-worker`, immutable source6f516b09ff03845554f18fd4a5e451c6cacfdbed. Worker-only workflow delta must not be merged. Canonical hashes are guarded; no publication path exists. Source regeneration remains NOT RUN. The native result is134→134: one AGND join but original signal split/new dangling warning;0DRC/parity,fresh agreement,all51177old objects retained,7new,only reviewed footprint translation changes. Changed edge-landing pilot37988525124 at9a934f0484d369c0f95810743a6e44ee63be2b4b on `agent-fix/189-jr-rb4413-edge-worker` is terminal and independently verified (guardPASS33s):134→133,0DRC/parity,no new warnings/splits,all51177old blocks+8new,only reviewed physical translation,fresh agreement. JR133 remains provisional until source regeneration/native sync/placement and adoption.

## Exact continuation

1. Exec access has recovered; inspect local status and refresh the current continuation branch without discarding local work. Refresh main, PR212 and other-session refs. Query core37984573591 plus read-only zone37976003780/37983410773. Main835f403 post-CI37982818544 is fully passed. Never restart unrelated watches or create a duplicate core writer.
2. JL adoption is already integrated asd50853d; do not replay/cherry-pick twice. PR211 is already merged; verify post-merge37982818544 rather than replaying it. Keep worker-only workflow out and verify post-merge main.
3. For terminal zone classification: download SHA-verified artifact, retain raw DRC/project/rules and `result.json` at `.circuit-cache/issue189-downloaded/native-zone-classification/`. Run `bash "$HOME/.codex/scripts/heavy-guard.sh" -- .circuit-cache/route-venv/bin/python circuit/routing/issue189/native-hole-audit/reassess.py`. Full382copper data is at `native-all-copper-silk`, holes at `native-hole-context`, candidate at `core-finer-ground-batch/.circuit-cache`, under the same download root. Any new zone warning rejects; preserve exact identities and change the proposal, never waive them.
4. **Do not redispatch core37984573591.** Wait for its terminal result, download the artifact and verify its published ZIP SHA. Its input is a0e3cff1ebc211564b8be10f6a993d50fb6d4372edde86a056ebc8dda3ea5932; reviewed proposal382objects=344segments+38vias,zero cuts,all133169old objects retained. Reconcile raw and complete warning evidence, every source/context/fixture hash, all original-group memberships, native DRC/parity and settled/fresh agreement. A workflow success alone is not adoption. Compare the exact bot commit files against artifact blobs and preserve newer main copper before cherry-picking. If rejected, retain exact identities/splits and change the proposal/method; never waive or resubmit unchanged. The saved older candidateb9f5ca13/replay25a3de55 remain provisional and must not be published directly.
5. PR212 is merged; do not merge it twice. Current draft PR213 is https://github.com/Takazudo/zudo-osc-hole-field/pull/213 on `agent-fix/189-jr-movement-continuation`; mainc1de561 was merged into the continuation branch. Keep PR213 draft until all exact-head gates and review complete. After an authorized merge, verify main and post-merge checks; distinguish cancelled from passed. Preserve issue189OPEN until all3boards are zero edges with required settled/fresh repeats, final regeneration/P/EL/O/docs/renders.
6. Continue remaining JL/JR signals/grounds and core supplies/signals through bounded native checks. `core-supply-away-from-splits/` is only prepared:94wholecases/120segments,zero cuts/vias; conditional ground conflict removes one whole U4439.4 case only if ground is actually adopted. No native acceptance claimed. After two negligible comparable trials change cause/method, not just budget.

7. First JR movement pilot37986929982 is already rejected and reconciled; do not replay it. Changed landing pilot37988525124 is already reconciled; its proof is reproducible using `jr-rb4413-edge-bridge/reconcile.py`, a SHA-verified download.json and `.circuit-cache/issue189-downloaded/jr-rb4413-edge-bridge/`. Verify all51177old objects plus exactly8new, only RB4413[0,-0.2]mm movement, context, warnings, original groups and settled/fresh agreement. A positive native pilot is still not adoption: activate its reviewed source translation only after that proof, regenerate source/schematics and verify the resulting native board. No duplicate pilot while active.

## Native audit timeout evidence

Old serializer run37976003780 reached only F.Cu stage0 item88/144 at20:27:32, then its90minute job limit cancelled classification at20:28:22. Artifact ZIP creation failed at20:29:09 when a temporary ~osc-core.kicad_pro.lck disappeared; GitHub reportszero artifacts. No acceptance evidence was recovered. `native-hole-audit/zone-timeout-37976003780.json` records immutable source, times, full-log hash and diagnostic excerpts. Future adoption/local/zone uploads exclude transient ~*.lck only; required boards, native reports and context remain included. Two workflow regressions pass. Active optimized audit and core writer refs are unchanged.

## JR movement rejection and changed landing repair

Pilot37986929982 artifact11643528926 ZIPd039362231964844efbd9dc631f15000b44b5c62fc28008ce4052ff4662056ce is SHA-verified and reconciled. Candidate/fresh1244eabbc7210d0961c7fbe27a1d39cdb71972f5822d6570cd9536e871a2cd81. AGND23→22edges, but X34EC684E00B004F73024 splits and existing track34f3b8b3-14db-5078-9909-c5d7b4d35488 dangles. Total134unchanged, so rejected. All51177old full copper blocks retained,7added,0cuts; nativeDRC/parity0,fresh agreement; exact project/rules and all physical blocks except reviewedRB4413[0,-0.2]mm unchanged. `jr-rb4413-move/native-result.json` is authoritative; no source regeneration/adoption.

The dangling track landed at the old pad edge(385.7,92.7), not its centre. `jr-rb4413-edge-bridge/` adds a full0.2mm segment to(385.7,92.4), inside the moved pad. Exact rejected native input static foreign-copper minimum0.605mm;guardPASS1s. Proposal now7segments+1via,0cuts. Changed-method read-only pilot37988525124 is terminal and passed all disposable native gates at immutable worker9a934f0484d369c0f95810743a6e44ee63be2b4b; first pilot was terminal before dispatch. Same native/source/physical/retention gates; no publication path. Reconcile its artifact with the sibling script after creating its SHA-verified download.json. Source regeneration remains mandatory before any adoption, even if its native gate passes.

## Deterministic source translation preparation

`routing-placement-translations.json` is present with an EMPTY list: no placement is changed. The floorplan generator now supports tightly reviewed JL/JR resistor translations with full expected-source rows, nonempty evidence references, ±2mm bounds and0.1mm increments. It rejects fixed/bypass/nonresistor/wrong-board parts, stale rows, side/rotation edits, duplicate requests, boundary violations and the original conservative0.35mm courtyard margin (including diagonal cases). Other source rows are never repacked.

15focused placement regressions pass. `partition35_floorplan.py --check` completed under the shared guard in263s with byte-identical generated output. `pnpm circuit:check` and `pnpm check` pass; inventory scope remainsmanual,68lines,no schematic/placement binding performed by that documentation validator. No native moved-board/source adoption is inferred. If the changed JR pilot passes all native and independent checks, its plan's complete source_part and[0,-0.2]mm delta can form the one reviewed source record; deterministic full source/schematic regeneration, native sync/placement, original copper/groups and all ordinary acceptance gates still follow before canonical adoption.

## Verified JR133 candidate and current verification blockers

Artifact11644272337 ZIP1aa605b8e4a72efebf4716b991f3b0999eec2eae71ba938275269c66b02eb96a is verified. Native candidate/freshae6e998c8b490394c6d3f7e2749e7d1521b4f9c6120067358a6bdf766cead5ff is133edges with candidate/fresh promotion gates true,0DRC/parity,no new warnings/splits,all51177old copper blocks+8additions,zero cuts,only RB4413[0,-0.2]mm physical change and exact project/rules. Independent reconciliation guardPASS33s. `jr-rb4413-edge-bridge/{native-result,download,pending-source-translation}.json` and source-adoption-plan.md define the next complete transaction. Canonical JR stays134 and the source translation list staysEMPTY. Do not publish the pilot directly.

PR213 exact-head CI37989870090 at23bf617 and follow-up37990346648 ata9241c6 both fail before native DRC on Docker Hub unauthenticated pull-rate limits for the pinned10.0.6image. The Python PrecisionVendorSweepGate also fails with empty stdout; it invokes the same oracle but captured stderr was not emitted, so shared-cause attribution is plausible, NOT proven. Receipts ci-23bf617-failed.json,ci-a9241c6-failed.json andci-oracle-rate-limit.json preserve actual failures. No failed check is waived; PR213 must remain draft and unmerged until exact-current-head verification succeeds.

The local pinned version probe failed unpacking an image layer with no space left on device. To preserve evidence while recovering space,249task-owned extracted PCB copies were compared byte-for-byte with68SHA-verified retained ZIPs, then removed only after re-verification (guardPASS80splan/57sapply). Released7,831,323,387bytes; all canonical/current candidate inputs, ZIPs, reports and project/rules remain. `extracted-archive-retention.json` records every exact member/hash/path. Use `python3 circuit/routing/issue189/restore_extracted_pcb.py <evidence-root>` before rerunning historical scripts needing removed boards. It refuses differing existing bytes. Current accepted roots and JR133/core candidates were protected. The retry also failed registering a layer with no space left (guardFAIL70s), despite8.6GiBfree and94%inodesfree. Docker usesvfs at/var/lib/docker on the32GiBworkspace; no image is installed. `local-oracle-blocker.json` and related deferred-verification issue214 preserve the exact blocker. Shell execution is healthy: no fresh task is necessary just for exec recovery. Further local native work requires larger compatible Docker capacity; CI can resume when pinned-image pull access recovers. Do not alter shared daemon configuration or substituteKiCad9.

Deferred verification: https://github.com/Takazudo/zudo-osc-hole-field/issues/214. Third exact-head CI37990930994 atd5522cb also failed with the same pinned-image rate limit and Python empty-output assertion. PR213 remains draft; do not merge on old-green PR212 checks. The sole core worker37984573591 and optimized read-only audit37983410773 remain active at the latest read. No active local heavy process or terminal watch remains after the native probe ended.

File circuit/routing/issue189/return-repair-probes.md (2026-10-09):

# Supply/return repair probes

These probes do not change a canonical board. Native gates rejected both fixed
signal proposals after plane fanout failed to restore original supply membership.
The main branch retains JL139/JR162. Do not repeat that unchanged fanout method.

- JR run37875619974, artifact11592851696, ZIP SHA256
  `0a74c371c14b3b4b2b67547db013d9edc61d4a02eabbaa2c00a4fdec63d9aac5`.
  Extract under `.circuit-cache/issue189-downloaded/jr-coupled/`.
- JL run37877201397, artifact11593520062, ZIP SHA256
  `0bd16fa13d1bc30adb33d4a9eeb5398593dd238d66e99e7344da6245da401415`.
  Extract under `.circuit-cache/issue189-downloaded/jl-coupled/`.

From the repository root, using the pinned numerical environment:

```sh
bash "$HOME/.codex/scripts/heavy-guard.sh" -- .circuit-cache/route-venv/bin/python circuit/routing/issue189/jr-rail-link-probe.py
bash "$HOME/.codex/scripts/heavy-guard.sh" -- .circuit-cache/route-venv/bin/python circuit/routing/issue189/jl-rail-link-probe.py
```

Both use the existing rail-link dimensions:0.4mm width,0.25mm clearance,0.05mm grid,
6mm window, original expansion limit, and original layer/fill restrictions. JR:
zero paths/six failures in31.04s. JL:two paths/four failures,20 objects in50.05s.
The JL paths include its newly detached supply group and a pre-existing supply
obligation. Native validation of these added rail paths is NOT RUN yet.

`jr-fill-attribution.py` uses the earlier native-cut JR dump from local pilot
37873299470, documented in the artifact ledger. Its approximate fill screen marks
multiple new target In3 segments and the victim's new via as individual split
risks. Removing any one object from that screen is insufficient; this is not
native causal proof or an eligible proposal. It cannot justify dropping necessary
signal copper or changing electrical constraints. Exact diagnostic JSON is saved.

The follow-up JL native pilot selects the existing `rail-links` stage to connect
components rather than fan out into a disconnected plane fragment. It must restore
all original supply membership, optionally stitch AGND, pass the independent
reload, and improve the original canonical result without warning regressions.

## Terminal direct-link outcome and isolated segment

Native JL run37878622291 (artifact11593858317, SHA256
`f51ba63f0596d048a0fa680222d8b693426860c03dec81b0f30cf7e9420fb57a`)
finished139→138, zero native errors/parity/new warnings, but rejected because
C2148.2 remains split from original AGND. Extract under
`.circuit-cache/issue189-downloaded/jl-links/`. The direct ground-link probe uses
that exact fresh dump and original ground dimensions0.3mm/0.25mm/0.6mm via; zero
paths, no copper. Its narrowed search scope is never an acceptance metric.

`jr-rail-blocker-probe.py` uses the frozen original JR dump. It permits only the
three signal nets with source tracks within2mm of U7106.11, max2 victims/one round,
with original dimensions and limits. All five supply probes failed, no copper
was added/removed. Detailed reasons remain in its JSON; failure does not prove
physical impossibility.

The next leaf proposal selects only the native0.65mm -12V segment at(258,183)mm,
far from the rejected C2148 repair. It adds one track and removes nothing; all72
nearby original physical objects are unchanged. It is NOT independently native
checked yet and must never inherit the rejected parent's lower count as accepted
progress. Its plan rejects any supply/ground split without extra repairs.

## Explicit ground corridor pilot

The opt-in `repair_ground_pad_uuids` field permits an AGND target only with an
explicit `repair_source_uuids` list. It is bounded to four source pads, twelve
signal-copper objects and two victim nets. Existing supply/ground copper cannot
be selected for removal. Default signal-only repair behavior is unchanged.

After the exact cut, KiCad supplies the victim component boundaries, including
padless retained fragments. Only the ground search is narrowed to the selected
source groups and the largest ground group; the complete native dump remains the
acceptance baseline. Mixed ground/signal search still uses the existing signal
layers, so a victim cannot acquire access to a reserved plane. AGND matches the
existing stitching dimensions (0.3mm track,0.25mm minimum clearance,0.6mm via)
and is excluded from signal neck-down. Signal victims also receive at least the
0.25mm clearance in this mode. Original pad membership, warning identities,
DRC/parity and independent native reload remain mandatory.

The first case is R1301.2 on accepted JL135: remove only signal via
`fa171022-b139-55ce-8e09-dd3ae02497b0` at143.5,122.7mm, retaining the other69
objects on that victim net and all unrelated copper. Source selection and native
pilot are pinned in `jl-ground-corridor-selection.json` and the checkpoint.
The whole-net experiment failed victim reconnection and rolled back; that failure
is why this case uses native local boundaries instead.

A subsequent read-only four-source screen identified candidate selections of
2objects for R8105,7 for RB2217,1 for R2209 and14 for R8276. R8276 exceeds the
new mode's twelve-object bound and is not eligible for that pilot unchanged.
No follow-up selection has native acceptance yet; do not reuse its JL135 input
hash after a successful adoption without reconciling against the new board.

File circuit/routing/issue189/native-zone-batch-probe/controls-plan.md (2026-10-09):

# Native batching controls — prepared, not run

The134 completed saved zone fixtures have no zone-linked silk findings. Timing
equality on that archive alone therefore cannot demonstrate detection of a
positive finding. No production batching or acceptance change is authorized by
an all-negative sample.

`probe_zone_batch_controls.py` prepares an independent native control: copy the
exact full zone polygon coordinates from SHA95c815b2178511621f97cd7021938023b96d4ee19c9282ae99b35fb387ba10c5,
deliberately map its layer to F.Mask, and insert two synthetic silk lines inside
that exposed mask region plus one outside. A fifth control keeps the original
F.Cu zone layer with the same two interior silk lines and requires no zone-linked
finding. This directly tests the layer-applicability inference; any unexpected
finding rejects it. This is a deliberately modified test
fixture, never a source/candidate board. It requires pinned10.0.6, original
project/rules, exact native polygon coordinates, exact artwork IDs and below-cap
reports. Single-positive, single-negative and joint reports must detect exactly
the expected IDs, and the batch identity set must equal the single-item union.
A missing positive finding fails the control; it must not be relabeled a pass.

Eleven unit tests pass for serialization, explicit layer mapping, identities,
invalid scope, native version and capped report rejection. **Native NOT RUN.**
First reconcile performance run38002541870 on b19d387. If batching meets the
predeclared2x threshold with identical scope/identities, run these controls once
with a10-minute command bound on the supported pinned runner. Do not retry local
image unpacking. Keep core writer37984573591 untouched.

```sh
timeout --signal=INT --kill-after=2m 10m \
  bash scripts/kicad/run.sh python3 scripts/pcbgen/probe_zone_batch_controls.py \
  PATH_TO_VERIFIED_BEFORE_BOARD .circuit-cache/issue189-zone-batch-controls
```

A successful control still does not certify core1402. Production batching would
need exact before/after coverage, per-batch source/geometry/context/report
binding, both report caps, complete identity unions, coverage rejection tests,
and a fresh full native audit. The existing acceptance path is unchanged.

Pinned-source review motivates the extra copper control; it is not acceptance
proof. The silk provider evaluates rules on the target layer, forces mask overlap
checking for individual mask items, and skips a pair when no nonnegative
clearance applies. The implicit board silk rule is restricted to silk layers.
The current core rules contain only clearance/track-width custom constraints.
The inference is that a copper-only zone has no applicable silk constraint here;
the native controls must test it, and production gates are unchanged.

- [KiCad10.0.6 silk provider](https://gitlab.com/kicad/code/kicad/-/raw/10.0.6/pcbnew/drc/drc_test_provider_silk_clearance.cpp)
- [KiCad10.0.6 implicit rules](https://gitlab.com/kicad/code/kicad/-/raw/10.0.6/pcbnew/drc/drc_engine.cpp)

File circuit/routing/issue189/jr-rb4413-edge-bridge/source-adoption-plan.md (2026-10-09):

# Exact source/copper adoption continuation

JR133 is a native-checked disposable candidate, not canonical. Source input remains EMPTY. Do not copy the pilot board straight onto main: its source footprint-origin field/schematic regeneration has not been performed.

1. Refresh main and other-session heads; current accepted JR SHA256 is35b52972dd70b4186cf3f3b7ee2ac3d70432f3476c2f56c9fcf9c1c4d7d4d445. If that changes, rebase/revalidate the whole transaction. Preserve the active core worker37984573591.
2. Read native-result.json and download.json. Re-extract the immutable ZIP1aa605b8e4a72efebf4716b991f3b0999eec2eae71ba938275269c66b02eb96a if needed. Candidate/freshae6e998c8b490394c6d3f7e2749e7d1521b4f9c6120067358a6bdf766cead5ff is133edges with0DRC/parity,no new warning/split,all51177old blocks+8new and only RB4413[0,-0.2]mm movement. Independent guardPASS33s.
3. Use an isolated adoption branch/workspace. Preserve a native settled baseline and its original schematic/project/rules before regeneration. pending-source-translation.json is the complete proposed source record; activate it only in that isolated branch. Do not hand-edit generated floorplan JSON.
4. Run source generation with the pinned10.0.6 oracle: `bash scripts/partition/regen.sh`, then `bash scripts/schgen/regen-boards.sh`. Inspect the complete generated diff; only the reviewed placement/source-field consequences may change. Update the real-placement integration regression to compare pre-translation expected_source with the generated translated row, rather than translating an already-translated row twice. Preserve all unrelated source rows and fixed lockfile geometry.
5. Create a disposable candidate through route_jack_grid.workspace so updated schematic/project/rules and library-relative paths are correct. Copy the SHA-verified pilot board there, then run native `scripts/pcbgen/sync.py osc-jack-right --output .circuit-cache/osc-jack-right-grid-189-source-adoption/osc-jack-right.kicad_pcb` and `scripts/pcbgen/place.py osc-jack-right --board .circuit-cache/osc-jack-right-grid-189-source-adoption/osc-jack-right.kicad_pcb` using the regenerated default schematic/boards/osc-jack-right.net. Existing copper must remain intact. Sync may update the reviewed FootprintOriginMm field; inspect every other physical/source delta rather than waiving it.
6. Re-run native settled/fresh checks and the ordinary promotion gate against the original baseline. Require all original pad memberships, no new warnings,0DRC/parity,strict edge gain,all51177prior copper blocks,exact8additions and no cuts. Verify project/rules, zones/stackup/fixed hardware, and repeat source generation/sync determinism. The earlier native pilot does not substitute for these post-source checks.
7. Only after those gates pass may the isolated candidate and its generated source/replay receipts be adopted together. Independently compare every worker/artifact blob before integration. Keep other canonical boards unchanged. Exact-head CI and repository review must pass before merging; issue189 remainsOPEN.

CI37989870090 currently fails on all three pinned-image pulls due to Docker Hub unauthenticated rate limiting. The Python sweep test also fails with empty stdout; it invokes the same oracle, but stderr was not printed, so its infrastructure attribution remains an inference. Preserve the failure, do not weaken checks or substitute KiCad9, and require a successful rerun after oracle access recovers. Two local pinned-image probes failed registering a layer with no space left, including after reclaiming7.8GB of verified redundant extracted boards. Docker usesvfs on32GB; see local-oracle-blocker.json and issue214. Do not assume native availability until a pinned version probe actually prints10.0.6.

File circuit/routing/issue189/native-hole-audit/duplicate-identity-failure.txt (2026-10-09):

hole-audit	Audit every potentially violating hole pair with pinned native fixtures	2026-10-09T17:31:54.2379342Z ##[group]Run set -euo pipefail
hole-audit	Audit every potentially violating hole pair with pinned native fixtures	2026-10-09T17:31:54.2379843Z [36;1mset -euo pipefail[0m
hole-audit	Audit every potentially violating hole pair with pinned native fixtures	2026-10-09T17:31:54.2380246Z [36;1mfor stage in start merge; do[0m
hole-audit	Audit every potentially violating hole pair with pinned native fixtures	2026-10-09T17:31:54.2381043Z [36;1m  bash scripts/kicad/run.sh python3 scripts/pcbgen/audit_hole_pairs.py \[0m
hole-audit	Audit every potentially violating hole pair with pinned native fixtures	2026-10-09T17:31:54.2382049Z [36;1m    ".circuit-cache/hole-audit-input/.circuit-cache/osc-core-grid-shards-$stage/osc-core.kicad_pcb" \[0m
hole-audit	Audit every potentially violating hole pair with pinned native fixtures	2026-10-09T17:31:54.2382885Z [36;1m    ".circuit-cache/hole-audit-$stage"[0m
hole-audit	Audit every potentially violating hole pair with pinned native fixtures	2026-10-09T17:31:54.2383323Z [36;1mdone[0m
hole-audit	Audit every potentially violating hole pair with pinned native fixtures	2026-10-09T17:31:54.2474258Z shell: /usr/bin/bash -e {0}
hole-audit	Audit every potentially violating hole pair with pinned native fixtures	2026-10-09T17:31:54.2474661Z ##[endgroup]
hole-audit	Audit every potentially violating hole pair with pinned native fixtures	2026-10-09T17:31:54.3380632Z Unable to find image 'kicad/kicad@sha256:18693567392b80da435f9fa952ce3a3e534c66eb5a6033f5b9c80aa3b19dd3ec' locally
hole-audit	Audit every potentially violating hole pair with pinned native fixtures	2026-10-09T17:31:54.5440059Z docker.io/kicad/kicad@sha256:18693567392b80da435f9fa952ce3a3e534c66eb5a6033f5b9c80aa3b19dd3ec: Pulling from kicad/kicad
hole-audit	Audit every potentially violating hole pair with pinned native fixtures	2026-10-09T17:31:54.6203913Z f072f58012e5: Pulling fs layer
hole-audit	Audit every potentially violating hole pair with pinned native fixtures	2026-10-09T17:31:54.6206264Z 7a697221ed08: Pulling fs layer
hole-audit	Audit every potentially violating hole pair with pinned native fixtures	2026-10-09T17:31:54.6207080Z 2a725967b0c1: Pulling fs layer
hole-audit	Audit every potentially violating hole pair with pinned native fixtures	2026-10-09T17:31:54.6208074Z d59c8d6b4ee3: Pulling fs layer
hole-audit	Audit every potentially violating hole pair with pinned native fixtures	2026-10-09T17:31:54.6208558Z 06396e02790e: Pulling fs layer
hole-audit	Audit every potentially violating hole pair with pinned native fixtures	2026-10-09T17:31:54.6208953Z 2378ea4a3f01: Pulling fs layer
hole-audit	Audit every potentially violating hole pair with pinned native fixtures	2026-10-09T17:31:54.6209333Z a5fac0bcdf2f: Pulling fs layer
hole-audit	Audit every potentially violating hole pair with pinned native fixtures	2026-10-09T17:31:54.6209708Z 2a4cad830bcc: Pulling fs layer
hole-audit	Audit every potentially violating hole pair with pinned native fixtures	2026-10-09T17:31:54.6210073Z 247e0200b7e4: Pulling fs layer
hole-audit	Audit every potentially violating hole pair with pinned native fixtures	2026-10-09T17:31:54.6210441Z 9a99e09d41bb: Pulling fs layer
hole-audit	Audit every potentially violating hole pair with pinned native fixtures	2026-10-09T17:31:54.6210819Z 51707baaa5e0: Pulling fs layer
hole-audit	Audit every potentially violating hole pair with pinned native fixtures	2026-10-09T17:31:54.6211367Z b5ecfc164241: Pulling fs layer
hole-audit	Audit every potentially violating hole pair with pinned native fixtures	2026-10-09T17:31:54.6211722Z 2c012cda8801: Pulling fs layer
hole-audit	Audit every potentially violating hole pair with pinned native fixtures	2026-10-09T17:31:54.6212074Z d59c8d6b4ee3: Waiting
hole-audit	Audit every potentially violating hole pair with pinned native fixtures	2026-10-09T17:31:54.6212450Z 247e0200b7e4: Waiting
hole-audit	Audit every potentially violating hole pair with pinned native fixtures	2026-10-09T17:31:54.6212769Z 9a99e09d41bb: Waiting
hole-audit	Audit every potentially violating hole pair with pinned native fixtures	2026-10-09T17:31:54.6213069Z 06396e02790e: Waiting
hole-audit	Audit every potentially violating hole pair with pinned native fixtures	2026-10-09T17:31:54.6213373Z 2378ea4a3f01: Waiting
hole-audit	Audit every potentially violating hole pair with pinned native fixtures	2026-10-09T17:31:54.6213675Z a5fac0bcdf2f: Waiting
hole-audit	Audit every potentially violating hole pair with pinned native fixtures	2026-10-09T17:31:54.6213983Z 2a4cad830bcc: Waiting
hole-audit	Audit every potentially violating hole pair with pinned native fixtures	2026-10-09T17:31:54.6214300Z 51707baaa5e0: Waiting
hole-audit	Audit every potentially violating hole pair with pinned native fixtures	2026-10-09T17:31:54.6214614Z b5ecfc164241: Waiting
hole-audit	Audit every potentially violating hole pair with pinned native fixtures	2026-10-09T17:31:54.6214928Z 2c012cda8801: Waiting
hole-audit	Audit every potentially violating hole pair with pinned native fixtures	2026-10-09T17:31:54.9734413Z f072f58012e5: Verifying Checksum
hole-audit	Audit every potentially violating hole pair with pinned native fixtures	2026-10-09T17:31:54.9743339Z f072f58012e5: Download complete
hole-audit	Audit every potentially violating hole pair with pinned native fixtures	2026-10-09T17:31:55.2319485Z 2a725967b0c1: Verifying Checksum
hole-audit	Audit every potentially violating hole pair with pinned native fixtures	2026-10-09T17:31:55.2361553Z 2a725967b0c1: Download complete
hole-audit	Audit every potentially violating hole pair with pinned native fixtures	2026-10-09T17:31:55.4970622Z 06396e02790e: Verifying Checksum
hole-audit	Audit every potentially violating hole pair with pinned native fixtures	2026-10-09T17:31:55.4972411Z 06396e02790e: Download complete
hole-audit	Audit every potentially violating hole pair with pinned native fixtures	2026-10-09T17:31:55.5899307Z d59c8d6b4ee3: Verifying Checksum
hole-audit	Audit every potentially violating hole pair with pinned native fixtures	2026-10-09T17:31:55.5901940Z d59c8d6b4ee3: Download complete
hole-audit	Audit every potentially violating hole pair with pinned native fixtures	2026-10-09T17:31:55.6699491Z a5fac0bcdf2f: Verifying Checksum
hole-audit	Audit every potentially violating hole pair with pinned native fixtures	2026-10-09T17:31:55.6699916Z a5fac0bcdf2f: Download complete
hole-audit	Audit every potentially violating hole pair with pinned native fixtures	2026-10-09T17:31:55.7394635Z 2a4cad830bcc: Verifying Checksum
hole-audit	Audit every potentially violating hole pair with pinned native fixtures	2026-10-09T17:31:55.7396525Z 2a4cad830bcc: Download complete
hole-audit	Audit every potentially violating hole pair with pinned native fixtures	2026-10-09T17:31:55.8132032Z 247e0200b7e4: Verifying Checksum
hole-audit	Audit every potentially violating hole pair with pinned native fixtures	2026-10-09T17:31:55.8138736Z 247e0200b7e4: Download complete
hole-audit	Audit every potentially violating hole pair with pinned native fixtures	2026-10-09T17:31:55.8891348Z 9a99e09d41bb: Verifying Checksum
hole-audit	Audit every potentially violating hole pair with pinned native fixtures	2026-10-09T17:31:55.8892262Z 9a99e09d41bb: Download complete
hole-audit	Audit every potentially violating hole pair with pinned native fixtures	2026-10-09T17:31:55.9691663Z 51707baaa5e0: Verifying Checksum
hole-audit	Audit every potentially violating hole pair with pinned native fixtures	2026-10-09T17:31:55.9695374Z 51707baaa5e0: Download complete
hole-audit	Audit every potentially violating hole pair with pinned native fixtures	2026-10-09T17:31:56.0369577Z b5ecfc164241: Verifying Checksum
hole-audit	Audit every potentially violating hole pair with pinned native fixtures	2026-10-09T17:31:56.0382130Z b5ecfc164241: Download complete
hole-audit	Audit every potentially violating hole pair with pinned native fixtures	2026-10-09T17:31:56.1186896Z 2c012cda8801: Verifying Checksum
hole-audit	Audit every potentially violating hole pair with pinned native fixtures	2026-10-09T17:31:56.1187680Z 2c012cda8801: Download complete
hole-audit	Audit every potentially violating hole pair with pinned native fixtures	2026-10-09T17:31:56.1317944Z 2378ea4a3f01: Verifying Checksum
hole-audit	Audit every potentially violating hole pair with pinned native fixtures	2026-10-09T17:31:56.1319041Z 2378ea4a3f01: Download complete
hole-audit	Audit every potentially violating hole pair with pinned native fixtures	2026-10-09T17:31:57.0783425Z f072f58012e5: Pull complete
hole-audit	Audit every potentially violating hole pair with pinned native fixtures	2026-10-09T17:31:57.2277248Z 7a697221ed08: Verifying Checksum
hole-audit	Audit every potentially violating hole pair with pinned native fixtures	2026-10-09T17:31:57.2278107Z 7a697221ed08: Download complete
hole-audit	Audit every potentially violating hole pair with pinned native fixtures	2026-10-09T17:32:14.2858209Z 7a697221ed08: Pull complete
hole-audit	Audit every potentially violating hole pair with pinned native fixtures	2026-10-09T17:32:16.0188522Z 2a725967b0c1: Pull complete
hole-audit	Audit every potentially violating hole pair with pinned native fixtures	2026-10-09T17:32:23.5570485Z d59c8d6b4ee3: Pull complete
hole-audit	Audit every potentially violating hole pair with pinned native fixtures	2026-10-09T17:32:23.8517805Z 06396e02790e: Pull complete
hole-audit	Audit every potentially violating hole pair with pinned native fixtures	2026-10-09T17:32:25.2319532Z 2378ea4a3f01: Pull complete
hole-audit	Audit every potentially violating hole pair with pinned native fixtures	2026-10-09T17:32:27.1925064Z a5fac0bcdf2f: Pull complete
hole-audit	Audit every potentially violating hole pair with pinned native fixtures	2026-10-09T17:32:27.2252340Z 2a4cad830bcc: Pull complete
hole-audit	Audit every potentially violating hole pair with pinned native fixtures	2026-10-09T17:32:27.2401591Z 247e0200b7e4: Pull complete
hole-audit	Audit every potentially violating hole pair with pinned native fixtures	2026-10-09T17:32:27.2577902Z 9a99e09d41bb: Pull complete
hole-audit	Audit every potentially violating hole pair with pinned native fixtures	2026-10-09T17:32:27.2675686Z 51707baaa5e0: Pull complete
hole-audit	Audit every potentially violating hole pair with pinned native fixtures	2026-10-09T17:32:27.2765315Z b5ecfc164241: Pull complete
hole-audit	Audit every potentially violating hole pair with pinned native fixtures	2026-10-09T17:32:27.2854450Z 2c012cda8801: Pull complete
hole-audit	Audit every potentially violating hole pair with pinned native fixtures	2026-10-09T17:32:27.2905415Z Digest: sha256:18693567392b80da435f9fa952ce3a3e534c66eb5a6033f5b9c80aa3b19dd3ec
hole-audit	Audit every potentially violating hole pair with pinned native fixtures	2026-10-09T17:32:27.2912763Z Status: Downloaded newer image for kicad/kicad@sha256:18693567392b80da435f9fa952ce3a3e534c66eb5a6033f5b9c80aa3b19dd3ec
hole-audit	Audit every potentially violating hole pair with pinned native fixtures	2026-10-09T17:34:23.7168562Z Traceback (most recent call last):
hole-audit	Audit every potentially violating hole pair with pinned native fixtures	2026-10-09T17:34:23.7183647Z   File "/work/scripts/pcbgen/audit_hole_pairs.py", line 171, in <module>
hole-audit	Audit every potentially violating hole pair with pinned native fixtures	2026-10-09T17:34:23.7184140Z     args=parser.parse_args(); audit(args.board,args.output)
hole-audit	Audit every potentially violating hole pair with pinned native fixtures	2026-10-09T17:34:23.7184596Z                               ~~~~~^^^^^^^^^^^^^^^^^^^^^^^^
hole-audit	Audit every potentially violating hole pair with pinned native fixtures	2026-10-09T17:34:23.7185153Z   File "/work/scripts/pcbgen/audit_hole_pairs.py", line 126, in audit
hole-audit	Audit every potentially violating hole pair with pinned native fixtures	2026-10-09T17:34:23.7186002Z     holes, objects = native_holes(source, pcbnew)
hole-audit	Audit every potentially violating hole pair with pinned native fixtures	2026-10-09T17:34:23.7186400Z                      ~~~~~~~~~~~~^^^^^^^^^^^^^^^^
hole-audit	Audit every potentially violating hole pair with pinned native fixtures	2026-10-09T17:34:23.7186922Z   File "/work/scripts/pcbgen/audit_hole_pairs.py", line 75, in native_holes
hole-audit	Audit every potentially violating hole pair with pinned native fixtures	2026-10-09T17:34:23.7187405Z     raise ValueError('duplicate hole UUID cannot identify native pair: ' + uid)
hole-audit	Audit every potentially violating hole pair with pinned native fixtures	2026-10-09T17:34:23.7187931Z ValueError: duplicate hole UUID cannot identify native pair: 068d8b75-2a29-587e-ad91-2a5fd680fc8e
hole-audit	Audit every potentially violating hole pair with pinned native fixtures	2026-10-09T17:34:23.8435980Z ##[error]Process completed with exit code 1.

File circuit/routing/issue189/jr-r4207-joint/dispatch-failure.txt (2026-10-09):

adopt	Replay reviewed JR copper through the native gate	2026-10-09T16:39:03.8430013Z ##[group]Run mkdir -p .circuit-cache
adopt	Replay reviewed JR copper through the native gate	2026-10-09T16:39:03.8430382Z [36;1mmkdir -p .circuit-cache[0m
adopt	Replay reviewed JR copper through the native gate	2026-10-09T16:39:03.8430644Z [36;1mset -o pipefail[0m
adopt	Replay reviewed JR copper through the native gate	2026-10-09T16:39:03.8430898Z [36;1mcase "$JR_REPLAY" in[0m
adopt	Replay reviewed JR copper through the native gate	2026-10-09T16:39:03.8432082Z [36;1m  return-restored|original-ground|u7509-on-ground|rail-finer|two-on-supply|bounded-one|bounded-two|three-compatible|two-without-d7504|next-three|three-protected|two-after-protected|d7504-via-avoid|three-remaining|d7504-outer-avoid|d7208-no-via|two-no-via|r8487-no-via|two-fine-ground|u8303-endpoints) ;;[0m
adopt	Replay reviewed JR copper through the native gate	2026-10-09T16:39:03.8433297Z [36;1m  *) exit 1 ;;[0m
adopt	Replay reviewed JR copper through the native gate	2026-10-09T16:39:03.8433503Z [36;1mesac[0m
adopt	Replay reviewed JR copper through the native gate	2026-10-09T16:39:03.8433804Z [36;1mreplay="circuit/routing/issue189/jr-${JR_REPLAY}-copper.json"[0m
adopt	Replay reviewed JR copper through the native gate	2026-10-09T16:39:03.8435844Z [36;1mif [[ $JR_REPLAY == bounded-one || $JR_REPLAY == bounded-two || $JR_REPLAY == three-compatible || $JR_REPLAY == two-without-d7504 || $JR_REPLAY == next-three || $JR_REPLAY == three-protected || $JR_REPLAY == two-after-protected || $JR_REPLAY == d7504-via-avoid || $JR_REPLAY == three-remaining || $JR_REPLAY == d7504-outer-avoid || $JR_REPLAY == d7208-no-via || $JR_REPLAY == two-no-via || $JR_REPLAY == r8487-no-via || $JR_REPLAY == two-fine-ground || $JR_REPLAY == u8303-endpoints || $JR_REPLAY == r4207-joint ]]; then[0m
adopt	Replay reviewed JR copper through the native gate	2026-10-09T16:39:03.8437638Z [36;1m  python "circuit/routing/issue189/jr-${JR_REPLAY}/prepare.py"[0m
adopt	Replay reviewed JR copper through the native gate	2026-10-09T16:39:03.8438083Z [36;1m  replay=".circuit-cache/issue189-jr-${JR_REPLAY}/copper.json"[0m
adopt	Replay reviewed JR copper through the native gate	2026-10-09T16:39:03.8438438Z [36;1mfi[0m
adopt	Replay reviewed JR copper through the native gate	2026-10-09T16:39:03.8438885Z [36;1mtimeout --signal=INT --kill-after=2m 80m python -u scripts/pcbgen/route_shards.py merge osc-jack-right \[0m
adopt	Replay reviewed JR copper through the native gate	2026-10-09T16:39:03.8439438Z [36;1m  "$replay" --label "issue189-${JR_REPLAY}" \[0m
adopt	Replay reviewed JR copper through the native gate	2026-10-09T16:39:03.8439774Z [36;1m  2>&1 | tee .circuit-cache/adoption.log[0m
adopt	Replay reviewed JR copper through the native gate	2026-10-09T16:39:03.8504471Z shell: /usr/bin/bash -e {0}
adopt	Replay reviewed JR copper through the native gate	2026-10-09T16:39:03.8504738Z env:
adopt	Replay reviewed JR copper through the native gate	2026-10-09T16:39:03.8504937Z   BOARD: osc-jack-right
adopt	Replay reviewed JR copper through the native gate	2026-10-09T16:39:03.8505173Z   BENCHMARK_RUN:
adopt	Replay reviewed JR copper through the native gate	2026-10-09T16:39:03.8505382Z   RECOVER_CORE: false
adopt	Replay reviewed JR copper through the native gate	2026-10-09T16:39:03.8505602Z   CORE_REPLAY: aggregate
adopt	Replay reviewed JR copper through the native gate	2026-10-09T16:39:03.8505814Z   REPLAY_JR: true
adopt	Replay reviewed JR copper through the native gate	2026-10-09T16:39:03.8506176Z   JR_REPLAY: r4207-joint
adopt	Replay reviewed JR copper through the native gate	2026-10-09T16:39:03.8506388Z   REPLAY_JL: false
adopt	Replay reviewed JR copper through the native gate	2026-10-09T16:39:03.8506589Z   JL_REPLAY: rail-leaf
adopt	Replay reviewed JR copper through the native gate	2026-10-09T16:39:03.8506869Z   pythonLocation: /opt/hostedtoolcache/Python/3.10.22/x64
adopt	Replay reviewed JR copper through the native gate	2026-10-09T16:39:03.8507322Z   PKG_CONFIG_PATH: /opt/hostedtoolcache/Python/3.10.22/x64/lib/pkgconfig
adopt	Replay reviewed JR copper through the native gate	2026-10-09T16:39:03.8507745Z   Python_ROOT_DIR: /opt/hostedtoolcache/Python/3.10.22/x64
adopt	Replay reviewed JR copper through the native gate	2026-10-09T16:39:03.8508123Z   Python2_ROOT_DIR: /opt/hostedtoolcache/Python/3.10.22/x64
adopt	Replay reviewed JR copper through the native gate	2026-10-09T16:39:03.8508505Z   Python3_ROOT_DIR: /opt/hostedtoolcache/Python/3.10.22/x64
adopt	Replay reviewed JR copper through the native gate	2026-10-09T16:39:03.8508883Z   LD_LIBRARY_PATH: /opt/hostedtoolcache/Python/3.10.22/x64/lib
adopt	Replay reviewed JR copper through the native gate	2026-10-09T16:39:03.8509203Z ##[endgroup]
adopt	Replay reviewed JR copper through the native gate	2026-10-09T16:39:03.8613839Z ##[error]Process completed with exit code 1.

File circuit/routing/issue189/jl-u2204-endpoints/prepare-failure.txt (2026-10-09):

adopt	Replay reviewed JL copper through full native gates	2026-10-09T14:52:36.2449180Z ##[group]Run mkdir -p .circuit-cache
adopt	Replay reviewed JL copper through full native gates	2026-10-09T14:52:36.2449586Z [36;1mmkdir -p .circuit-cache[0m
adopt	Replay reviewed JL copper through full native gates	2026-10-09T14:52:36.2449904Z [36;1mset -o pipefail[0m
adopt	Replay reviewed JL copper through full native gates	2026-10-09T14:52:36.2450188Z [36;1mif [[ $JL_REPLAY == paired-corridors ]]; then[0m
adopt	Replay reviewed JL copper through full native gates	2026-10-09T14:52:36.2450641Z [36;1m  python circuit/routing/issue189/jl-paired-corridors-prepare.py[0m
adopt	Replay reviewed JL copper through full native gates	2026-10-09T14:52:36.2451190Z [36;1m  replay=circuit/routing/issue189/jl-paired-corridors-copper.json[0m
adopt	Replay reviewed JL copper through full native gates	2026-10-09T14:52:36.2451942Z [36;1m  label=issue189-paired-corridors[0m
adopt	Replay reviewed JL copper through full native gates	2026-10-09T14:52:36.2452293Z [36;1melif [[ $JL_REPLAY == corridor ]]; then[0m
adopt	Replay reviewed JL copper through full native gates	2026-10-09T14:52:36.2452701Z [36;1m  replay=circuit/routing/issue189/jl-corridor-copper.json[0m
adopt	Replay reviewed JL copper through full native gates	2026-10-09T14:52:36.2453089Z [36;1m  label=issue189-corridor[0m
adopt	Replay reviewed JL copper through full native gates	2026-10-09T14:52:36.2453392Z [36;1melif [[ $JL_REPLAY == rail-leaf ]]; then[0m
adopt	Replay reviewed JL copper through full native gates	2026-10-09T14:52:36.2453793Z [36;1m  replay=circuit/routing/issue189/jl-rail-leaf-copper.json[0m
adopt	Replay reviewed JL copper through full native gates	2026-10-09T14:52:36.2454185Z [36;1m  label=issue189-rail-leaf[0m
adopt	Replay reviewed JL copper through full native gates	2026-10-09T14:52:36.2454552Z [36;1melif [[ $JL_REPLAY == ground-junction ]]; then[0m
adopt	Replay reviewed JL copper through full native gates	2026-10-09T14:52:36.2455003Z [36;1m  replay=circuit/routing/issue189/jl-ground-junction-copper.json[0m
adopt	Replay reviewed JL copper through full native gates	2026-10-09T14:52:36.2455431Z [36;1m  label=issue189-ground-junction[0m
adopt	Replay reviewed JL copper through full native gates	2026-10-09T14:52:36.2455753Z [36;1melif [[ $JL_REPLAY == rail-finer ]]; then[0m
adopt	Replay reviewed JL copper through full native gates	2026-10-09T14:52:36.2456159Z [36;1m  replay=circuit/routing/issue189/jl-rail-finer-copper.json[0m
adopt	Replay reviewed JL copper through full native gates	2026-10-09T14:52:36.2456563Z [36;1m  label=issue189-rail-finer[0m
adopt	Replay reviewed JL copper through full native gates	2026-10-09T14:52:36.2457516Z [36;1melif [[ $JL_REPLAY == u106-outer || $JL_REPLAY == u2119-outer || $JL_REPLAY == u2119-via-avoid || $JL_REPLAY == u2119-ground-corridor || $JL_REPLAY == c8143-fanout || $JL_REPLAY == three-finer-ground || $JL_REPLAY == u2204-endpoints ]]; then[0m
adopt	Replay reviewed JL copper through full native gates	2026-10-09T14:52:36.2458586Z [36;1m  python "circuit/routing/issue189/jl-$JL_REPLAY/prepare.py"[0m
adopt	Replay reviewed JL copper through full native gates	2026-10-09T14:52:36.2459060Z [36;1m  replay=".circuit-cache/issue189-jl-$JL_REPLAY/copper.json"[0m
adopt	Replay reviewed JL copper through full native gates	2026-10-09T14:52:36.2459444Z [36;1m  label="issue189-$JL_REPLAY"[0m
adopt	Replay reviewed JL copper through full native gates	2026-10-09T14:52:36.2459746Z [36;1melif [[ $JL_REPLAY == d2326 ]]; then[0m
adopt	Replay reviewed JL copper through full native gates	2026-10-09T14:52:36.2460313Z [36;1m  replay=circuit/routing/issue189/jl-d2326-copper.json[0m
adopt	Replay reviewed JL copper through full native gates	2026-10-09T14:52:36.2460656Z [36;1m  label=issue189-d2326[0m
adopt	Replay reviewed JL copper through full native gates	2026-10-09T14:52:36.2460899Z [36;1melse[0m
adopt	Replay reviewed JL copper through full native gates	2026-10-09T14:52:36.2461088Z [36;1m  exit 1[0m
adopt	Replay reviewed JL copper through full native gates	2026-10-09T14:52:36.2461285Z [36;1mfi[0m
adopt	Replay reviewed JL copper through full native gates	2026-10-09T14:52:36.2461868Z [36;1mtimeout --signal=INT --kill-after=2m 80m python -u scripts/pcbgen/route_shards.py merge osc-jack-left \[0m
adopt	Replay reviewed JL copper through full native gates	2026-10-09T14:52:36.2462402Z [36;1m  "$replay" --label "$label" \[0m
adopt	Replay reviewed JL copper through full native gates	2026-10-09T14:52:36.2462701Z [36;1m  2>&1 | tee .circuit-cache/adoption.log[0m
adopt	Replay reviewed JL copper through full native gates	2026-10-09T14:52:36.2527908Z shell: /usr/bin/bash -e {0}
adopt	Replay reviewed JL copper through full native gates	2026-10-09T14:52:36.2528181Z env:
adopt	Replay reviewed JL copper through full native gates	2026-10-09T14:52:36.2528394Z   BOARD: osc-jack-left
adopt	Replay reviewed JL copper through full native gates	2026-10-09T14:52:36.2528640Z   BENCHMARK_RUN:
adopt	Replay reviewed JL copper through full native gates	2026-10-09T14:52:36.2528872Z   RECOVER_CORE: false
adopt	Replay reviewed JL copper through full native gates	2026-10-09T14:52:36.2529117Z   CORE_REPLAY: aggregate
adopt	Replay reviewed JL copper through full native gates	2026-10-09T14:52:36.2529377Z   REPLAY_JR: false
adopt	Replay reviewed JL copper through full native gates	2026-10-09T14:52:36.2529618Z   JR_REPLAY: return-restored
adopt	Replay reviewed JL copper through full native gates	2026-10-09T14:52:36.2529885Z   REPLAY_JL: true
adopt	Replay reviewed JL copper through full native gates	2026-10-09T14:52:36.2530110Z   JL_REPLAY: u2204-endpoints
adopt	Replay reviewed JL copper through full native gates	2026-10-09T14:52:36.2530443Z   pythonLocation: /opt/hostedtoolcache/Python/3.10.22/x64
adopt	Replay reviewed JL copper through full native gates	2026-10-09T14:52:36.2530934Z   PKG_CONFIG_PATH: /opt/hostedtoolcache/Python/3.10.22/x64/lib/pkgconfig
adopt	Replay reviewed JL copper through full native gates	2026-10-09T14:52:36.2531420Z   Python_ROOT_DIR: /opt/hostedtoolcache/Python/3.10.22/x64
adopt	Replay reviewed JL copper through full native gates	2026-10-09T14:52:36.2532037Z   Python2_ROOT_DIR: /opt/hostedtoolcache/Python/3.10.22/x64
adopt	Replay reviewed JL copper through full native gates	2026-10-09T14:52:36.2532478Z   Python3_ROOT_DIR: /opt/hostedtoolcache/Python/3.10.22/x64
adopt	Replay reviewed JL copper through full native gates	2026-10-09T14:52:36.2532923Z   LD_LIBRARY_PATH: /opt/hostedtoolcache/Python/3.10.22/x64/lib
adopt	Replay reviewed JL copper through full native gates	2026-10-09T14:52:36.2533291Z ##[endgroup]
adopt	Replay reviewed JL copper through full native gates	2026-10-09T14:52:36.4372632Z Unable to find image 'kicad/kicad@sha256:18693567392b80da435f9fa952ce3a3e534c66eb5a6033f5b9c80aa3b19dd3ec' locally
adopt	Replay reviewed JL copper through full native gates	2026-10-09T14:52:37.0421989Z docker.io/kicad/kicad@sha256:18693567392b80da435f9fa952ce3a3e534c66eb5a6033f5b9c80aa3b19dd3ec: Pulling from kicad/kicad
adopt	Replay reviewed JL copper through full native gates	2026-10-09T14:52:37.3118291Z f072f58012e5: Pulling fs layer
adopt	Replay reviewed JL copper through full native gates	2026-10-09T14:52:37.3118951Z 7a697221ed08: Pulling fs layer
adopt	Replay reviewed JL copper through full native gates	2026-10-09T14:52:37.3119677Z 2a725967b0c1: Pulling fs layer
adopt	Replay reviewed JL copper through full native gates	2026-10-09T14:52:37.3120185Z d59c8d6b4ee3: Pulling fs layer
adopt	Replay reviewed JL copper through full native gates	2026-10-09T14:52:37.3120611Z 06396e02790e: Pulling fs layer
adopt	Replay reviewed JL copper through full native gates	2026-10-09T14:52:37.3120993Z 2378ea4a3f01: Pulling fs layer
adopt	Replay reviewed JL copper through full native gates	2026-10-09T14:52:37.3121276Z a5fac0bcdf2f: Pulling fs layer
adopt	Replay reviewed JL copper through full native gates	2026-10-09T14:52:37.3123537Z 2a4cad830bcc: Pulling fs layer
adopt	Replay reviewed JL copper through full native gates	2026-10-09T14:52:37.3124038Z 247e0200b7e4: Pulling fs layer
adopt	Replay reviewed JL copper through full native gates	2026-10-09T14:52:37.3124331Z 9a99e09d41bb: Pulling fs layer
adopt	Replay reviewed JL copper through full native gates	2026-10-09T14:52:37.3124607Z 51707baaa5e0: Pulling fs layer
adopt	Replay reviewed JL copper through full native gates	2026-10-09T14:52:37.3125011Z b5ecfc164241: Pulling fs layer
adopt	Replay reviewed JL copper through full native gates	2026-10-09T14:52:37.3125284Z 2c012cda8801: Pulling fs layer
adopt	Replay reviewed JL copper through full native gates	2026-10-09T14:52:37.3125553Z 2a4cad830bcc: Waiting
adopt	Replay reviewed JL copper through full native gates	2026-10-09T14:52:37.3125796Z d59c8d6b4ee3: Waiting
adopt	Replay reviewed JL copper through full native gates	2026-10-09T14:52:37.3126147Z 06396e02790e: Waiting
adopt	Replay reviewed JL copper through full native gates	2026-10-09T14:52:37.3126414Z 247e0200b7e4: Waiting
adopt	Replay reviewed JL copper through full native gates	2026-10-09T14:52:37.3126874Z 2378ea4a3f01: Waiting
adopt	Replay reviewed JL copper through full native gates	2026-10-09T14:52:37.3127304Z 9a99e09d41bb: Waiting
adopt	Replay reviewed JL copper through full native gates	2026-10-09T14:52:37.3127621Z 51707baaa5e0: Waiting
adopt	Replay reviewed JL copper through full native gates	2026-10-09T14:52:37.3127855Z a5fac0bcdf2f: Waiting
adopt	Replay reviewed JL copper through full native gates	2026-10-09T14:52:37.3128083Z 2c012cda8801: Waiting
adopt	Replay reviewed JL copper through full native gates	2026-10-09T14:52:37.3128309Z b5ecfc164241: Waiting
adopt	Replay reviewed JL copper through full native gates	2026-10-09T14:52:37.6264452Z f072f58012e5: Verifying Checksum
adopt	Replay reviewed JL copper through full native gates	2026-10-09T14:52:37.6269289Z f072f58012e5: Download complete
adopt	Replay reviewed JL copper through full native gates	2026-10-09T14:52:37.7564664Z 2a725967b0c1: Verifying Checksum
adopt	Replay reviewed JL copper through full native gates	2026-10-09T14:52:37.7565615Z 2a725967b0c1: Download complete
adopt	Replay reviewed JL copper through full native gates	2026-10-09T14:52:37.9968719Z d59c8d6b4ee3: Verifying Checksum
adopt	Replay reviewed JL copper through full native gates	2026-10-09T14:52:37.9970032Z d59c8d6b4ee3: Download complete
adopt	Replay reviewed JL copper through full native gates	2026-10-09T14:52:38.0291468Z 06396e02790e: Verifying Checksum
adopt	Replay reviewed JL copper through full native gates	2026-10-09T14:52:38.0292221Z 06396e02790e: Download complete
adopt	Replay reviewed JL copper through full native gates	2026-10-09T14:52:38.2492620Z a5fac0bcdf2f: Verifying Checksum
adopt	Replay reviewed JL copper through full native gates	2026-10-09T14:52:38.2493286Z a5fac0bcdf2f: Download complete
adopt	Replay reviewed JL copper through full native gates	2026-10-09T14:52:38.4611608Z 2a4cad830bcc: Download complete
adopt	Replay reviewed JL copper through full native gates	2026-10-09T14:52:38.6682309Z 247e0200b7e4: Verifying Checksum
adopt	Replay reviewed JL copper through full native gates	2026-10-09T14:52:38.6683065Z 247e0200b7e4: Download complete
adopt	Replay reviewed JL copper through full native gates	2026-10-09T14:52:38.7424467Z 2378ea4a3f01: Verifying Checksum
adopt	Replay reviewed JL copper through full native gates	2026-10-09T14:52:38.7425075Z 2378ea4a3f01: Download complete
adopt	Replay reviewed JL copper through full native gates	2026-10-09T14:52:38.8783548Z 9a99e09d41bb: Verifying Checksum
adopt	Replay reviewed JL copper through full native gates	2026-10-09T14:52:38.8784258Z 9a99e09d41bb: Download complete
adopt	Replay reviewed JL copper through full native gates	2026-10-09T14:52:38.9555445Z 51707baaa5e0: Verifying Checksum
adopt	Replay reviewed JL copper through full native gates	2026-10-09T14:52:38.9556889Z 51707baaa5e0: Download complete
adopt	Replay reviewed JL copper through full native gates	2026-10-09T14:52:39.0117534Z f072f58012e5: Pull complete
adopt	Replay reviewed JL copper through full native gates	2026-10-09T14:52:39.0874582Z b5ecfc164241: Verifying Checksum
adopt	Replay reviewed JL copper through full native gates	2026-10-09T14:52:39.0874976Z b5ecfc164241: Download complete
adopt	Replay reviewed JL copper through full native gates	2026-10-09T14:52:39.1859281Z 2c012cda8801: Download complete
adopt	Replay reviewed JL copper through full native gates	2026-10-09T14:52:39.5557157Z 7a697221ed08: Verifying Checksum
adopt	Replay reviewed JL copper through full native gates	2026-10-09T14:52:39.5557711Z 7a697221ed08: Download complete
adopt	Replay reviewed JL copper through full native gates	2026-10-09T14:52:51.9348477Z 7a697221ed08: Pull complete
adopt	Replay reviewed JL copper through full native gates	2026-10-09T14:52:52.8450231Z 2a725967b0c1: Pull complete
adopt	Replay reviewed JL copper through full native gates	2026-10-09T14:52:59.0933935Z d59c8d6b4ee3: Pull complete
adopt	Replay reviewed JL copper through full native gates	2026-10-09T14:52:59.2417234Z 06396e02790e: Pull complete
adopt	Replay reviewed JL copper through full native gates	2026-10-09T14:53:01.2933784Z 2378ea4a3f01: Pull complete
adopt	Replay reviewed JL copper through full native gates	2026-10-09T14:53:01.3025968Z a5fac0bcdf2f: Pull complete
adopt	Replay reviewed JL copper through full native gates	2026-10-09T14:53:01.3173217Z 2a4cad830bcc: Pull complete
adopt	Replay reviewed JL copper through full native gates	2026-10-09T14:53:01.3320809Z 247e0200b7e4: Pull complete
adopt	Replay reviewed JL copper through full native gates	2026-10-09T14:53:01.3448745Z 9a99e09d41bb: Pull complete
adopt	Replay reviewed JL copper through full native gates	2026-10-09T14:53:01.3564716Z 51707baaa5e0: Pull complete
adopt	Replay reviewed JL copper through full native gates	2026-10-09T14:53:01.3685334Z b5ecfc164241: Pull complete
adopt	Replay reviewed JL copper through full native gates	2026-10-09T14:53:01.3771732Z 2c012cda8801: Pull complete
adopt	Replay reviewed JL copper through full native gates	2026-10-09T14:53:01.3810744Z Digest: sha256:18693567392b80da435f9fa952ce3a3e534c66eb5a6033f5b9c80aa3b19dd3ec
adopt	Replay reviewed JL copper through full native gates	2026-10-09T14:53:01.3820039Z Status: Downloaded newer image for kicad/kicad@sha256:18693567392b80da435f9fa952ce3a3e534c66eb5a6033f5b9c80aa3b19dd3ec
adopt	Replay reviewed JL copper through full native gates	2026-10-09T14:53:04.2140669Z Traceback (most recent call last):
adopt	Replay reviewed JL copper through full native gates	2026-10-09T14:53:04.2190312Z   File "/work/scripts/pcbgen/grid_apply.py", line 56, in <module>
adopt	Replay reviewed JL copper through full native gates	2026-10-09T14:53:04.2191195Z     if __name__=='__main__':main()
adopt	Replay reviewed JL copper through full native gates	2026-10-09T14:53:04.2191950Z                             ~~~~^^
adopt	Replay reviewed JL copper through full native gates	2026-10-09T14:53:04.2192973Z   File "/work/scripts/pcbgen/grid_apply.py", line 54, in main
adopt	Replay reviewed JL copper through full native gates	2026-10-09T14:53:04.2193755Z     apply(a.board,json.loads(a.proposal.read_text()),a.output)
adopt	Replay reviewed JL copper through full native gates	2026-10-09T14:53:04.2194427Z     ~~~~~^^^^^^^^^^^^^^^^^^^^^^^^^^^^^^^^^^^^^^^^^^^^^^^^^^^^^
adopt	Replay reviewed JL copper through full native gates	2026-10-09T14:53:04.2195133Z   File "/work/scripts/pcbgen/grid_apply.py", line 34, in apply
adopt	Replay reviewed JL copper through full native gates	2026-10-09T14:53:04.2196013Z     if not project.exists():raise ValueError(f'{project} missing: net classes unknown')
adopt	Replay reviewed JL copper through full native gates	2026-10-09T14:53:04.2196827Z                             ^^^^^^^^^^^^^^^^^^^^^^^^^^^^^^^^^^^^^^^^^^^^^^^^^^^^^^^^^^^
adopt	Replay reviewed JL copper through full native gates	2026-10-09T14:53:04.2197835Z ValueError: .circuit-cache/issue189-jl-u2204-endpoints/osc-jack-left.kicad_pro missing: net classes unknown
adopt	Replay reviewed JL copper through full native gates	2026-10-09T14:53:04.2861868Z Traceback (most recent call last):
adopt	Replay reviewed JL copper through full native gates	2026-10-09T14:53:04.2863319Z   File "/home/runner/work/zudo-osc-hole-field/zudo-osc-hole-field/circuit/routing/issue189/jl-u2204-endpoints/prepare.py", line 43, in <module>
adopt	Replay reviewed JL copper through full native gates	2026-10-09T14:53:04.2864185Z     main()
adopt	Replay reviewed JL copper through full native gates	2026-10-09T14:53:04.2864969Z   File "/home/runner/work/zudo-osc-hole-field/zudo-osc-hole-field/circuit/routing/issue189/jl-u2204-endpoints/prepare.py", line 29, in main
adopt	Replay reviewed JL copper through full native gates	2026-10-09T14:53:04.2865887Z     subprocess.run(['bash', 'scripts/kicad/run.sh', 'python3',
adopt	Replay reviewed JL copper through full native gates	2026-10-09T14:53:04.2866570Z   File "/opt/hostedtoolcache/Python/3.10.22/x64/lib/python3.10/subprocess.py", line 526, in run
adopt	Replay reviewed JL copper through full native gates	2026-10-09T14:53:04.3431099Z     raise CalledProcessError(retcode, process.args,
adopt	Replay reviewed JL copper through full native gates	2026-10-09T14:53:04.3434220Z subprocess.CalledProcessError: Command '['bash', 'scripts/kicad/run.sh', 'python3', 'scripts/pcbgen/grid_apply.py', 'boards/osc-jack-left/osc-jack-left.kicad_pcb', 'circuit/routing/issue189/jl-u2204-endpoints/proposal.json', '--output', '.circuit-cache/issue189-jl-u2204-endpoints/osc-jack-left.kicad_pcb']' returned non-zero exit status 1.
adopt	Replay reviewed JL copper through full native gates	2026-10-09T14:53:04.3509690Z ##[error]Process completed with exit code 1.

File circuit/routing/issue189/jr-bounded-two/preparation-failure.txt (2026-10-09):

adopt	Replay reviewed JR copper through the native gate	2026-10-09T09:13:47.9953808Z ##[group]Run mkdir -p .circuit-cache
adopt	Replay reviewed JR copper through the native gate	2026-10-09T09:13:47.9954191Z [36;1mmkdir -p .circuit-cache[0m
adopt	Replay reviewed JR copper through the native gate	2026-10-09T09:13:47.9954486Z [36;1mset -o pipefail[0m
adopt	Replay reviewed JR copper through the native gate	2026-10-09T09:13:47.9954723Z [36;1mcase "$JR_REPLAY" in[0m
adopt	Replay reviewed JR copper through the native gate	2026-10-09T09:13:47.9955226Z [36;1m  return-restored|original-ground|u7509-on-ground|rail-finer|two-on-supply|bounded-one|bounded-two) ;;[0m
adopt	Replay reviewed JR copper through the native gate	2026-10-09T09:13:47.9955744Z [36;1m  *) exit 1 ;;[0m
adopt	Replay reviewed JR copper through the native gate	2026-10-09T09:13:47.9955955Z [36;1mesac[0m
adopt	Replay reviewed JR copper through the native gate	2026-10-09T09:13:47.9956251Z [36;1mreplay="circuit/routing/issue189/jr-${JR_REPLAY}-copper.json"[0m
adopt	Replay reviewed JR copper through the native gate	2026-10-09T09:13:47.9956723Z [36;1mif [[ $JR_REPLAY == bounded-one || $JR_REPLAY == bounded-two ]]; then[0m
adopt	Replay reviewed JR copper through the native gate	2026-10-09T09:13:47.9957212Z [36;1m  python "circuit/routing/issue189/jr-${JR_REPLAY}/prepare.py"[0m
adopt	Replay reviewed JR copper through the native gate	2026-10-09T09:13:47.9957682Z [36;1m  replay=".circuit-cache/issue189-jr-${JR_REPLAY}/copper.json"[0m
adopt	Replay reviewed JR copper through the native gate	2026-10-09T09:13:47.9958035Z [36;1mfi[0m
adopt	Replay reviewed JR copper through the native gate	2026-10-09T09:13:47.9958482Z [36;1mtimeout --signal=INT --kill-after=2m 80m python -u scripts/pcbgen/route_shards.py merge osc-jack-right \[0m
adopt	Replay reviewed JR copper through the native gate	2026-10-09T09:13:47.9959076Z [36;1m  "$replay" --label "issue189-${JR_REPLAY}" \[0m
adopt	Replay reviewed JR copper through the native gate	2026-10-09T09:13:47.9959417Z [36;1m  2>&1 | tee .circuit-cache/adoption.log[0m
adopt	Replay reviewed JR copper through the native gate	2026-10-09T09:13:48.0022312Z shell: /usr/bin/bash -e {0}
adopt	Replay reviewed JR copper through the native gate	2026-10-09T09:13:48.0022569Z env:
adopt	Replay reviewed JR copper through the native gate	2026-10-09T09:13:48.0022765Z   BOARD: osc-jack-right
adopt	Replay reviewed JR copper through the native gate	2026-10-09T09:13:48.0022993Z   BENCHMARK_RUN: 
adopt	Replay reviewed JR copper through the native gate	2026-10-09T09:13:48.0023195Z   RECOVER_CORE: false
adopt	Replay reviewed JR copper through the native gate	2026-10-09T09:13:48.0023410Z   CORE_REPLAY: aggregate
adopt	Replay reviewed JR copper through the native gate	2026-10-09T09:13:48.0023636Z   REPLAY_JR: true
adopt	Replay reviewed JR copper through the native gate	2026-10-09T09:13:48.0023841Z   JR_REPLAY: bounded-two
adopt	Replay reviewed JR copper through the native gate	2026-10-09T09:13:48.0024060Z   REPLAY_JL: false
adopt	Replay reviewed JR copper through the native gate	2026-10-09T09:13:48.0024258Z   JL_REPLAY: rail-leaf
adopt	Replay reviewed JR copper through the native gate	2026-10-09T09:13:48.0024540Z   pythonLocation: /opt/hostedtoolcache/Python/3.10.22/x64
adopt	Replay reviewed JR copper through the native gate	2026-10-09T09:13:48.0024984Z   PKG_CONFIG_PATH: /opt/hostedtoolcache/Python/3.10.22/x64/lib/pkgconfig
adopt	Replay reviewed JR copper through the native gate	2026-10-09T09:13:48.0025412Z   Python_ROOT_DIR: /opt/hostedtoolcache/Python/3.10.22/x64
adopt	Replay reviewed JR copper through the native gate	2026-10-09T09:13:48.0025818Z   Python2_ROOT_DIR: /opt/hostedtoolcache/Python/3.10.22/x64
adopt	Replay reviewed JR copper through the native gate	2026-10-09T09:13:48.0026418Z   Python3_ROOT_DIR: /opt/hostedtoolcache/Python/3.10.22/x64
adopt	Replay reviewed JR copper through the native gate	2026-10-09T09:13:48.0026807Z   LD_LIBRARY_PATH: /opt/hostedtoolcache/Python/3.10.22/x64/lib
adopt	Replay reviewed JR copper through the native gate	2026-10-09T09:13:48.0027132Z ##[endgroup]
adopt	Replay reviewed JR copper through the native gate	2026-10-09T09:13:48.0564812Z Traceback (most recent call last):
adopt	Replay reviewed JR copper through the native gate	2026-10-09T09:13:48.0573371Z   File "/opt/hostedtoolcache/Python/3.10.22/x64/lib/python3.10/subprocess.py", line 69, in <module>
adopt	Replay reviewed JR copper through the native gate	2026-10-09T09:13:48.0713974Z     import msvcrt
adopt	Replay reviewed JR copper through the native gate	2026-10-09T09:13:48.0714526Z ModuleNotFoundError: No module named 'msvcrt'
adopt	Replay reviewed JR copper through the native gate	2026-10-09T09:13:48.0714853Z 
adopt	Replay reviewed JR copper through the native gate	2026-10-09T09:13:48.0715124Z During handling of the above exception, another exception occurred:
adopt	Replay reviewed JR copper through the native gate	2026-10-09T09:13:48.0715546Z 
adopt	Replay reviewed JR copper through the native gate	2026-10-09T09:13:48.0715694Z Traceback (most recent call last):
adopt	Replay reviewed JR copper through the native gate	2026-10-09T09:13:48.0716957Z   File "/home/runner/work/zudo-osc-hole-field/zudo-osc-hole-field/circuit/routing/issue189/jr-bounded-two/prepare.py", line 9, in <module>
adopt	Replay reviewed JR copper through the native gate	2026-10-09T09:13:48.0718181Z     import subprocess
adopt	Replay reviewed JR copper through the native gate	2026-10-09T09:13:48.0719197Z   File "/opt/hostedtoolcache/Python/3.10.22/x64/lib/python3.10/subprocess.py", line 75, in <module>
adopt	Replay reviewed JR copper through the native gate	2026-10-09T09:13:48.0719987Z     import select
adopt	Replay reviewed JR copper through the native gate	2026-10-09T09:13:48.0720783Z   File "/home/runner/work/zudo-osc-hole-field/zudo-osc-hole-field/circuit/routing/issue189/jr-bounded-two/select.py", line 8, in <module>
adopt	Replay reviewed JR copper through the native gate	2026-10-09T09:13:48.0722141Z     a=(cache/'osc-jack-right-grid-shards-start/osc-jack-right.kicad_pcb').read_text()
adopt	Replay reviewed JR copper through the native gate	2026-10-09T09:13:48.0723060Z   File "/opt/hostedtoolcache/Python/3.10.22/x64/lib/python3.10/pathlib.py", line 1134, in read_text
adopt	Replay reviewed JR copper through the native gate	2026-10-09T09:13:48.1043546Z     with self.open(mode='r', encoding=encoding, errors=errors) as f:
adopt	Replay reviewed JR copper through the native gate	2026-10-09T09:13:48.1044331Z   File "/opt/hostedtoolcache/Python/3.10.22/x64/lib/python3.10/pathlib.py", line 1119, in open
adopt	Replay reviewed JR copper through the native gate	2026-10-09T09:13:48.1045191Z     return self._accessor.open(self, mode, buffering, encoding, errors,
adopt	Replay reviewed JR copper through the native gate	2026-10-09T09:13:48.1046480Z FileNotFoundError: [Errno 2] No such file or directory: '/home/runner/work/zudo-osc-hole-field/zudo-osc-hole-field/.circuit-cache/issue189-downloaded/jr-bounded-one/.circuit-cache/osc-jack-right-grid-shards-start/osc-jack-right.kicad_pcb'
adopt	Replay reviewed JR copper through the native gate	2026-10-09T09:13:48.1117860Z ##[error]Process completed with exit code 1.

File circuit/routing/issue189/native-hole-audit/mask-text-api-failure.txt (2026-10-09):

mask-audit	Audit new via mask interactions against unchanged native artwork	2026-10-09T17:49:45.8646341Z ##[group]Run bash scripts/kicad/run.sh python3 scripts/pcbgen/audit_added_mask.py \
mask-audit	Audit new via mask interactions against unchanged native artwork	2026-10-09T17:49:45.8646932Z [36;1mbash scripts/kicad/run.sh python3 scripts/pcbgen/audit_added_mask.py \[0m
mask-audit	Audit new via mask interactions against unchanged native artwork	2026-10-09T17:49:45.8647525Z [36;1m  .circuit-cache/hole-audit-input/.circuit-cache/osc-core-grid-shards-start/osc-core.kicad_pcb \[0m
mask-audit	Audit new via mask interactions against unchanged native artwork	2026-10-09T17:49:45.8648203Z [36;1m  .circuit-cache/hole-audit-input/.circuit-cache/osc-core-grid-shards-merge/osc-core.kicad_pcb \[0m
mask-audit	Audit new via mask interactions against unchanged native artwork	2026-10-09T17:49:45.8648881Z [36;1m  .circuit-cache/added-mask-audit[0m
mask-audit	Audit new via mask interactions against unchanged native artwork	2026-10-09T17:49:45.8684178Z shell: /usr/bin/bash -e {0}
mask-audit	Audit new via mask interactions against unchanged native artwork	2026-10-09T17:49:45.8684444Z ##[endgroup]
mask-audit	Audit new via mask interactions against unchanged native artwork	2026-10-09T17:49:45.9586075Z Unable to find image 'kicad/kicad@sha256:18693567392b80da435f9fa952ce3a3e534c66eb5a6033f5b9c80aa3b19dd3ec' locally
mask-audit	Audit new via mask interactions against unchanged native artwork	2026-10-09T17:49:46.4945295Z docker.io/kicad/kicad@sha256:18693567392b80da435f9fa952ce3a3e534c66eb5a6033f5b9c80aa3b19dd3ec: Pulling from kicad/kicad
mask-audit	Audit new via mask interactions against unchanged native artwork	2026-10-09T17:49:46.7097034Z f072f58012e5: Pulling fs layer
mask-audit	Audit new via mask interactions against unchanged native artwork	2026-10-09T17:49:46.7098000Z 7a697221ed08: Pulling fs layer
mask-audit	Audit new via mask interactions against unchanged native artwork	2026-10-09T17:49:46.7099835Z 2a725967b0c1: Pulling fs layer
mask-audit	Audit new via mask interactions against unchanged native artwork	2026-10-09T17:49:46.7100313Z d59c8d6b4ee3: Pulling fs layer
mask-audit	Audit new via mask interactions against unchanged native artwork	2026-10-09T17:49:46.7100944Z 06396e02790e: Pulling fs layer
mask-audit	Audit new via mask interactions against unchanged native artwork	2026-10-09T17:49:46.7101573Z 2378ea4a3f01: Pulling fs layer
mask-audit	Audit new via mask interactions against unchanged native artwork	2026-10-09T17:49:46.7102234Z a5fac0bcdf2f: Pulling fs layer
mask-audit	Audit new via mask interactions against unchanged native artwork	2026-10-09T17:49:46.7102701Z 2a4cad830bcc: Pulling fs layer
mask-audit	Audit new via mask interactions against unchanged native artwork	2026-10-09T17:49:46.7103289Z 247e0200b7e4: Pulling fs layer
mask-audit	Audit new via mask interactions against unchanged native artwork	2026-10-09T17:49:46.7103859Z 9a99e09d41bb: Pulling fs layer
mask-audit	Audit new via mask interactions against unchanged native artwork	2026-10-09T17:49:46.7104326Z 51707baaa5e0: Pulling fs layer
mask-audit	Audit new via mask interactions against unchanged native artwork	2026-10-09T17:49:46.7104760Z b5ecfc164241: Pulling fs layer
mask-audit	Audit new via mask interactions against unchanged native artwork	2026-10-09T17:49:46.7105176Z 2c012cda8801: Pulling fs layer
mask-audit	Audit new via mask interactions against unchanged native artwork	2026-10-09T17:49:46.7106513Z d59c8d6b4ee3: Waiting
mask-audit	Audit new via mask interactions against unchanged native artwork	2026-10-09T17:49:46.7106879Z 06396e02790e: Waiting
mask-audit	Audit new via mask interactions against unchanged native artwork	2026-10-09T17:49:46.7107185Z 2378ea4a3f01: Waiting
mask-audit	Audit new via mask interactions against unchanged native artwork	2026-10-09T17:49:46.7107423Z a5fac0bcdf2f: Waiting
mask-audit	Audit new via mask interactions against unchanged native artwork	2026-10-09T17:49:46.7107748Z 247e0200b7e4: Waiting
mask-audit	Audit new via mask interactions against unchanged native artwork	2026-10-09T17:49:46.7108026Z 9a99e09d41bb: Waiting
mask-audit	Audit new via mask interactions against unchanged native artwork	2026-10-09T17:49:46.7108276Z 2a4cad830bcc: Waiting
mask-audit	Audit new via mask interactions against unchanged native artwork	2026-10-09T17:49:46.7108603Z 51707baaa5e0: Waiting
mask-audit	Audit new via mask interactions against unchanged native artwork	2026-10-09T17:49:46.7109063Z b5ecfc164241: Waiting
mask-audit	Audit new via mask interactions against unchanged native artwork	2026-10-09T17:49:46.7109382Z 2c012cda8801: Waiting
mask-audit	Audit new via mask interactions against unchanged native artwork	2026-10-09T17:49:47.1163897Z f072f58012e5: Verifying Checksum
mask-audit	Audit new via mask interactions against unchanged native artwork	2026-10-09T17:49:47.1164858Z f072f58012e5: Download complete
mask-audit	Audit new via mask interactions against unchanged native artwork	2026-10-09T17:49:47.1706421Z 2a725967b0c1: Verifying Checksum
mask-audit	Audit new via mask interactions against unchanged native artwork	2026-10-09T17:49:47.1707570Z 2a725967b0c1: Download complete
mask-audit	Audit new via mask interactions against unchanged native artwork	2026-10-09T17:49:47.4878788Z 06396e02790e: Verifying Checksum
mask-audit	Audit new via mask interactions against unchanged native artwork	2026-10-09T17:49:47.4881302Z 06396e02790e: Download complete
mask-audit	Audit new via mask interactions against unchanged native artwork	2026-10-09T17:49:47.5116810Z d59c8d6b4ee3: Verifying Checksum
mask-audit	Audit new via mask interactions against unchanged native artwork	2026-10-09T17:49:47.5117358Z d59c8d6b4ee3: Download complete
mask-audit	Audit new via mask interactions against unchanged native artwork	2026-10-09T17:49:47.7035323Z a5fac0bcdf2f: Verifying Checksum
mask-audit	Audit new via mask interactions against unchanged native artwork	2026-10-09T17:49:47.7038805Z a5fac0bcdf2f: Download complete
mask-audit	Audit new via mask interactions against unchanged native artwork	2026-10-09T17:49:47.8906262Z 2a4cad830bcc: Verifying Checksum
mask-audit	Audit new via mask interactions against unchanged native artwork	2026-10-09T17:49:47.8907143Z 2a4cad830bcc: Download complete
mask-audit	Audit new via mask interactions against unchanged native artwork	2026-10-09T17:49:48.0957581Z 247e0200b7e4: Verifying Checksum
mask-audit	Audit new via mask interactions against unchanged native artwork	2026-10-09T17:49:48.0959388Z 247e0200b7e4: Download complete
mask-audit	Audit new via mask interactions against unchanged native artwork	2026-10-09T17:49:48.1167778Z 2378ea4a3f01: Verifying Checksum
mask-audit	Audit new via mask interactions against unchanged native artwork	2026-10-09T17:49:48.1169598Z 2378ea4a3f01: Download complete
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

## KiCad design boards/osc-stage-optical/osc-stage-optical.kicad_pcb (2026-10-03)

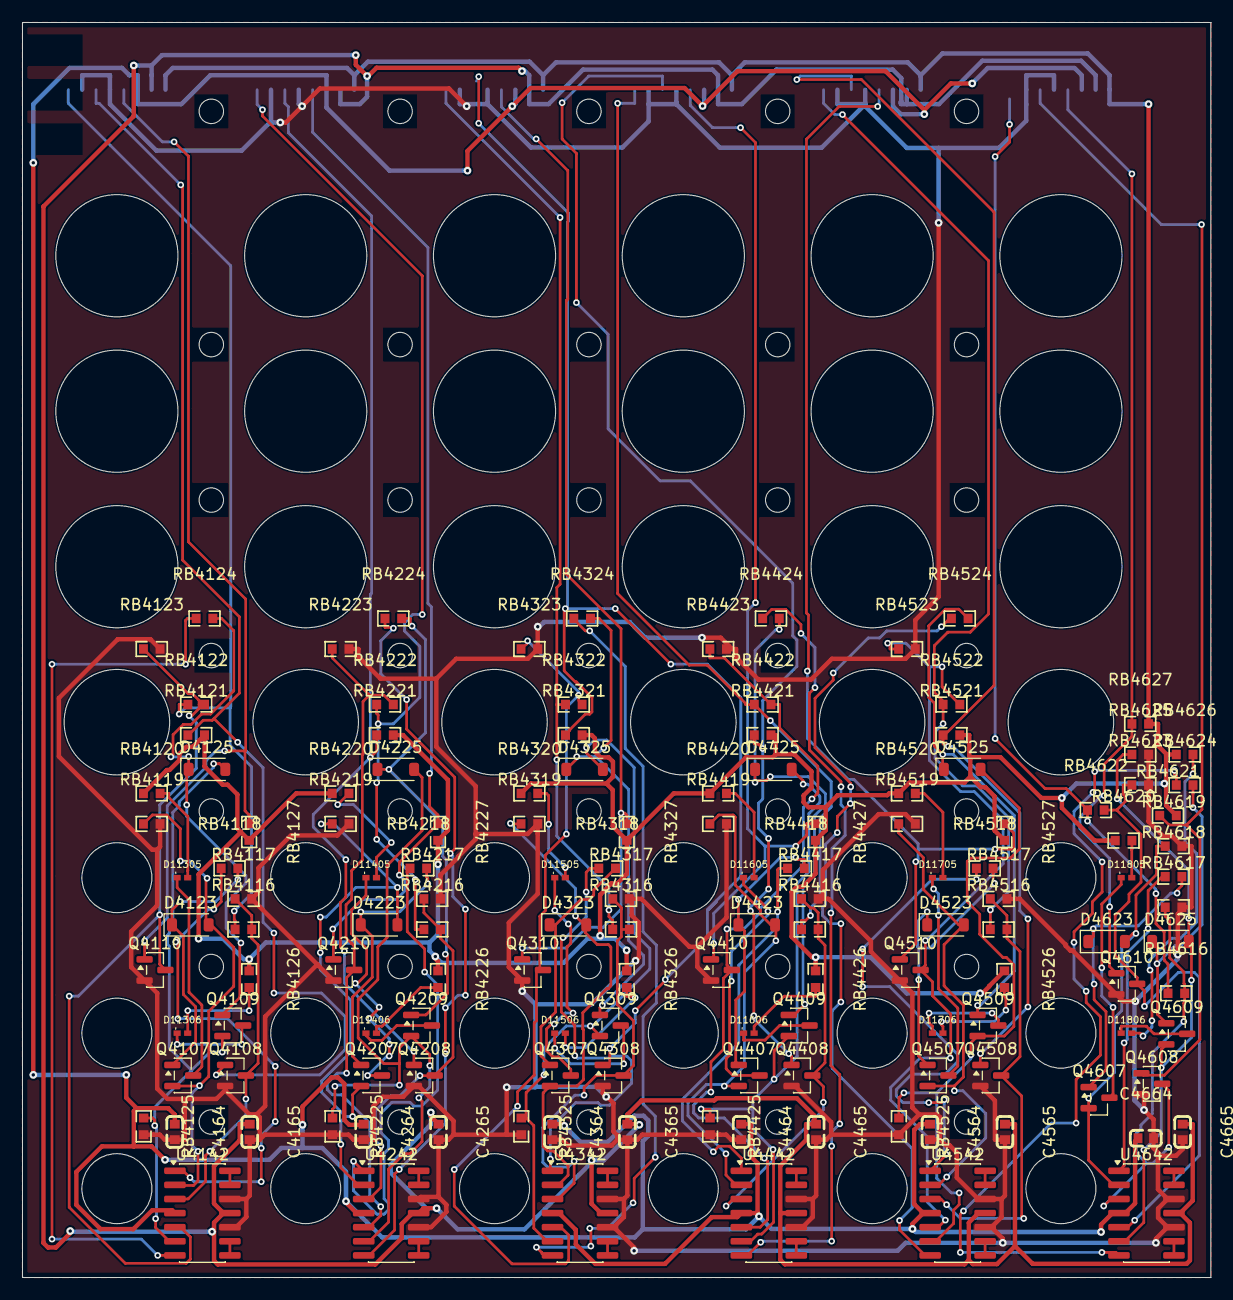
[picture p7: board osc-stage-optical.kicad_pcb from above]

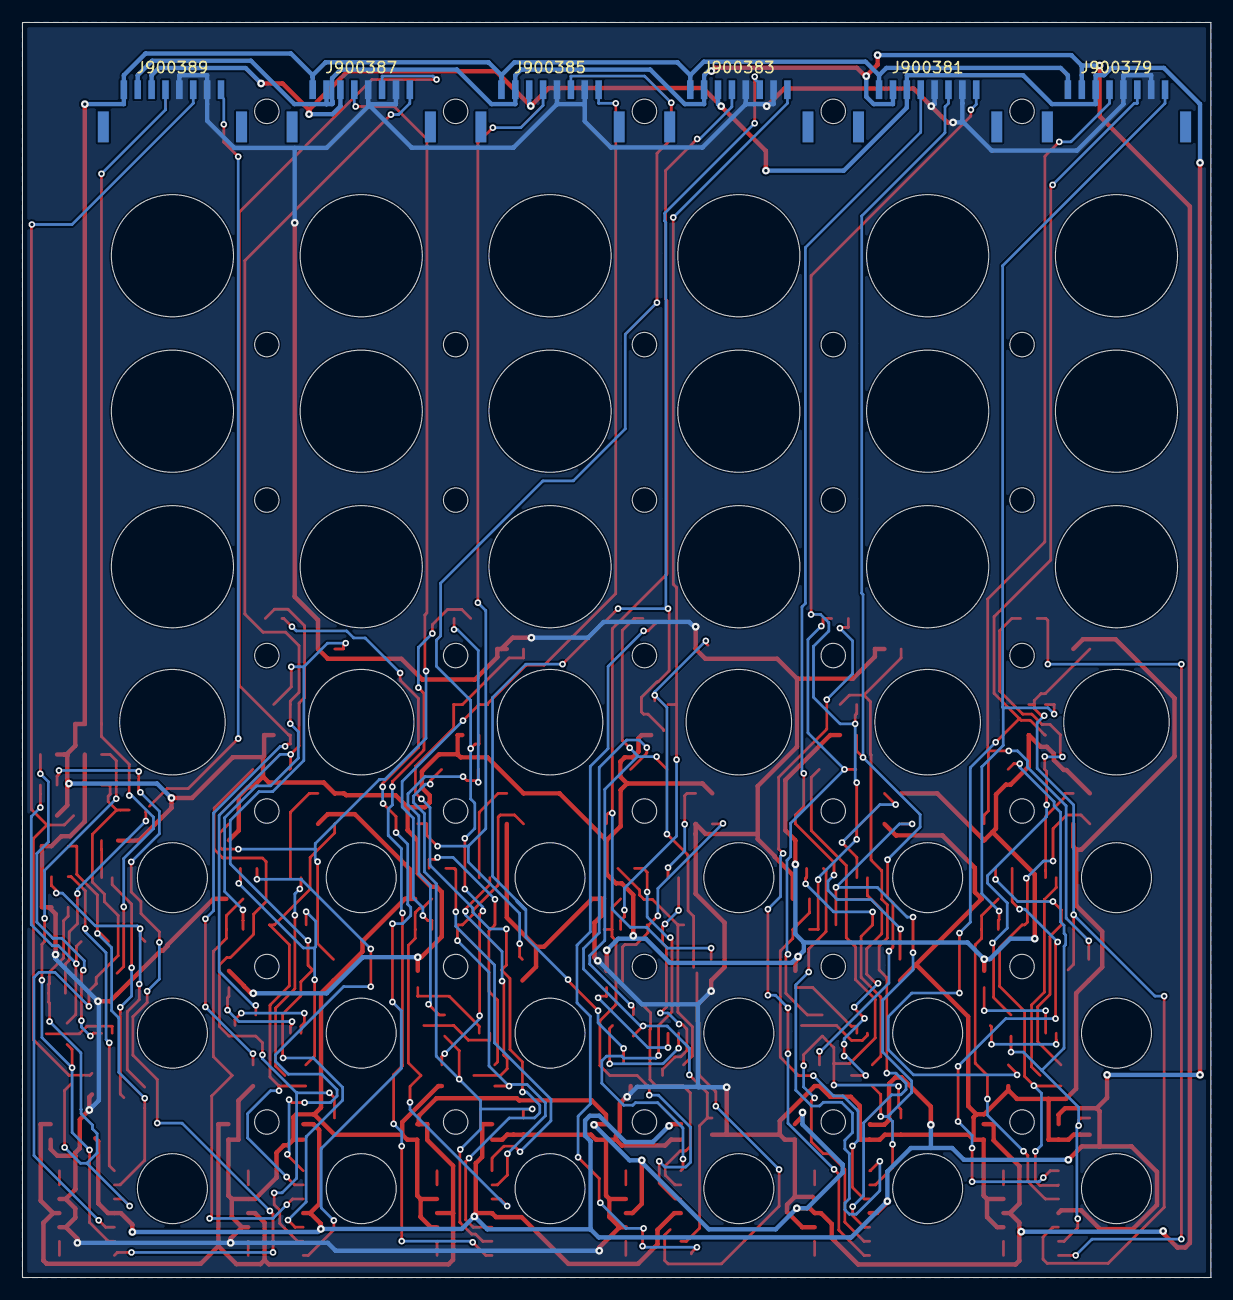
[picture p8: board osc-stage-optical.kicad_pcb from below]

Board: 2 copper layers, 107.0 x 113.0 mm, 221 parts (6 on the bottom side), 106 nets.

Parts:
C4164, C4165, C4264, C4265, C4364, C4365, C4464, C4465, C4564, C4565, C4664, C4665: 100 nF; C0603
D4123, D4125, D4223, D4225, D4323, D4325, D4423, D4425, D4523, D4525, D4623, D4625: BAS16GW-QX; SOD-123
D11305, D11306, D11405, D11406, D11505, D11506, D11605, D11606, D11705, D11706, D11805, D11806: APHHS1005QWF/D; LED0402-Kingbright-White
J900379, J900381, J900383, J900385, J900387, J900389: BM08B-GHS-TBT(LF)(SN); JST_GH8_BM_TopEntry
MH_EL-OPT-1, MH_EL-OPT-2, MH_EL-OPT-3, MH_EL-OPT-4, MH_EL-OPT-5, MH_EL-OPT-6, MH_EL-OPT-7, MH_EL-OPT-8, MH_EL-OPT-9, MH_EL-OPT-10, MH_EL-OPT-11, MH_EL-OPT-12, MH_EL-OPT-13, MH_EL-OPT-14, MH_EL-OPT-15, MH_EL-OPT-16, MH_EL-OPT-17, MH_EL-OPT-18, MH_EL-OPT-19, MH_EL-OPT-20, MH_EL-OPT-21, MH_EL-OPT-22, MH_EL-OPT-23, MH_EL-OPT-24, MH_EL-OPT-25, MH_EL-OPT-26, MH_EL-OPT-27, MH_EL-OPT-28, MH_EL-OPT-29, MH_EL-OPT-30, MH_EL-OPT-31, MH_EL-OPT-32, MH_EL-OPT-33, MH_EL-OPT-34, MH_EL-OPT-35: NPTH mounting hole
MH_EL-PASSAGE-1, MH_EL-PASSAGE-2, MH_EL-PASSAGE-3, MH_EL-PASSAGE-4, MH_EL-PASSAGE-5, MH_EL-PASSAGE-6, MH_EL-PASSAGE-7, MH_EL-PASSAGE-8, MH_EL-PASSAGE-9, MH_EL-PASSAGE-10, MH_EL-PASSAGE-11, MH_EL-PASSAGE-12, MH_EL-PASSAGE-13, MH_EL-PASSAGE-14, MH_EL-PASSAGE-15, MH_EL-PASSAGE-16, MH_EL-PASSAGE-17, MH_EL-PASSAGE-18, MH_EL-PASSAGE-19, MH_EL-PASSAGE-20, MH_EL-PASSAGE-21, MH_EL-PASSAGE-22, MH_EL-PASSAGE-23, MH_EL-PASSAGE-24, MH_EL-PASSAGE-25, MH_EL-PASSAGE-26, MH_EL-PASSAGE-27, MH_EL-PASSAGE-28, MH_EL-PASSAGE-29, MH_EL-PASSAGE-30, MH_EL-PASSAGE-31, MH_EL-PASSAGE-32, MH_EL-PASSAGE-33, MH_EL-PASSAGE-34, MH_EL-PASSAGE-35, MH_EL-PASSAGE-36, MH_EL-PASSAGE-37, MH_EL-PASSAGE-38, MH_EL-PASSAGE-39, MH_EL-PASSAGE-40, MH_EL-PASSAGE-41, MH_EL-PASSAGE-42: NPTH mounting hole
Q4107, Q4109, Q4207, Q4209, Q4307, Q4309, Q4407, Q4409, Q4507, Q4509, Q4607, Q4609: MMBT3904,215; SOT-23
Q4108, Q4110, Q4208, Q4210, Q4308, Q4310, Q4408, Q4410, Q4508, Q4510, Q4608, Q4610: 2N7002,215; SOT-23
RB4116, RB4122, RB4216, RB4222, RB4316, RB4322, RB4416, RB4422, RB4516, RB4522, RB4616, RB4622: 150000 Ω; R0603
RB4117, RB4118, RB4123, RB4124, RB4217, RB4218, RB4223, RB4224, RB4317, RB4318, RB4323, RB4324, RB4417, RB4418, RB4423, RB4424, RB4517, RB4518, RB4523, RB4524, RB4617, RB4618, RB4623, RB4624: 10000 Ω; R0603
RB4119, RB4125, RB4219, RB4225, RB4319, RB4325, RB4419, RB4425, RB4519, RB4525, RB4619, RB4625: 1000 Ω; R0603
RB4120, RB4126, RB4220, RB4226, RB4320, RB4326, RB4420, RB4426, RB4520, RB4526, RB4620, RB4626: 1200 Ω; R0603
RB4121, RB4127, RB4221, RB4227, RB4321, RB4327, RB4421, RB4427, RB4521, RB4527, RB4621, RB4627: 100000 Ω; R0603
U4142, U4242, U4342, U4442, U4542, U4642: OPA4196IDR; SOIC-14_3.9x8.7mm_P1.27mm

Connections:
+5V: J900379.8, J900381.8, J900383.8, J900385.8, J900387.8, J900389.8, RB4120.1, RB4121.2, RB4126.1, RB4127.2, RB4220.1, RB4221.2, RB4226.1, RB4227.2, RB4320.1, RB4321.2, RB4326.1, RB4327.2, RB4420.1, RB4421.2, RB4426.1, RB4427.2, RB4520.1, RB4521.2, RB4526.1, RB4527.2, RB4620.1, RB4621.2, RB4626.1, RB4627.2
+12V: C4164.1, C4264.1, C4364.1, C4464.1, C4564.1, C4664.1, J900379.6, J900381.6, J900383.6, J900385.6, J900387.6, J900389.6, U4142.4, U4242.4, U4342.4, U4442.4, U4542.4, U4642.4
-12V: C4165.1, C4265.1, C4365.1, C4465.1, C4565.1, C4665.1, J900379.7, J900381.7, J900383.7, J900385.7, J900387.7, J900389.7, U4142.11, U4242.11, U4342.11, U4442.11, U4542.11, U4642.11
AGND: C4164.2, C4165.2, C4264.2, C4265.2, C4364.2, C4365.2, C4464.2, C4465.2, C4564.2, C4565.2, C4664.2, C4665.2, J900379.2, J900379.4, J900381.2, J900381.4, J900383.2, J900383.4, J900385.2, J900385.4, J900387.2, J900387.4, J900389.2, J900389.4, Q4108.2, Q4110.2, Q4208.2, Q4210.2, Q4308.2, Q4310.2, Q4408.2, Q4410.2, Q4508.2, Q4510.2, Q4608.2, Q4610.2, RB4117.2, RB4119.2, RB4123.2, RB4125.2, RB4217.2, RB4219.2, RB4223.2, RB4225.2, RB4317.2, RB4319.2, RB4323.2, RB4325.2, RB4417.2, RB4419.2, RB4423.2, RB4425.2, RB4517.2, RB4519.2, RB4523.2, RB4525.2, RB4617.2, RB4619.2, RB4623.2, RB4625.2, U4142.10, U4142.12, U4242.10, U4242.12, U4342.10, U4342.12, U4442.10, U4442.12, U4542.10, U4542.12, U4642.10, U4642.12
X00BF5622D64D21A15AC7: J900389.3, Q4608.1, RB4621.1
X1AC60263070127D75110: D4225.1, Q4209.1, RB4224.2
X1BBA3C5B996B98DC88F4: J900383.5, Q4310.1, RB4327.1
X1D82190ED747CF04DE0E: RB4624.1, U4642.7
X1DC1CF348CA9F3663A68: Q4410.3, RB4422.2, RB4423.1, U4442.5
X1E1A841AE6BDBA6F12FD: D4423.1, Q4407.1, RB4418.2
X1E3069D9C725A8540F2B: Q4210.3, RB4222.2, RB4223.1, U4242.5
X1FFAABFEE1FB66BF068E: D4325.2, Q4309.2, RB4325.1, U4342.6
X2AC9B8A8C44204D4DCFE: D4423.2, Q4407.2, RB4419.1, U4442.2
X2E5349539AD45B40EC09: D4125.1, Q4109.1, RB4124.2
X4B6E43806072E34C24A9: D11505.2, RB4320.2
X5EF5AA803DEECA814BD8: D11605.2, RB4420.2
X6A8CD0115BB6A0D0366E: D11706.1, Q4509.3
X6A51B6341523E19D8CF4: D11806.1, Q4609.3
X6B20A2AEE7A32617CD3E: D11405.1, Q4207.3
X6C1DA0497CB43057E117: Q4608.3, RB4616.2, RB4617.1, U4642.3
X6E9F88B4B3BE457C0226: U4342.13, U4342.14
X7E65864BB7CF7411DC10: U4442.13, U4442.14
X8A939B676B6F87E5F9A3: J900383.1, RB4316.1, RB4322.1
X8ECADF7A8E0F09B77152: D11305.2, RB4120.2
X9A280F085D66F529A415: D11706.2, RB4526.2
X9B81034A8BEE6B2EBDA4: J900385.3, Q4408.1, RB4421.1
X9C2EA2BC9623A3E6139C: D11606.2, RB4426.2
X9E4D82CA4412C9189909: Q4508.3, RB4516.2, RB4517.1, U4542.3
X9E76C286BAE34857728C: D4323.2, Q4307.2, RB4319.1, U4342.2
X9F3B44E9C4F1B46F49CF: RB4124.1, U4142.7
X9F61A7055EEEA35F62E7: J900389.1, RB4616.1, RB4622.1
X10C845ED7B7C5BB89B7C: RB4224.1, U4242.7
X47BB1FB0495EA911FAB2: D4325.1, Q4309.1, RB4324.2
X61E1C31F3ACE5341D7D3: Q4408.3, RB4416.2, RB4417.1, U4442.3
X71B9E05195347FA9C8C2: J900387.1, RB4516.1, RB4522.1
X87EB8972925CDC4B1D2E: J900381.3, Q4208.1, RB4221.1
X88DA5861B6BCC3B653DE: D11606.1, Q4409.3
X95E38523BB35DF833AE9: J900385.1, RB4416.1, RB4422.1
X131A163062BE66F69054: J900385.5, Q4410.1, RB4427.1
X244B291CBC2C7076AA07: D11605.1, Q4407.3
X419B40DA0975D322AD5F: D11405.2, RB4220.2
X498F1E66A5FADE06B7E4: Q4308.3, RB4316.2, RB4317.1, U4342.3
X688ECBAA39258DC2D00D: D11805.2, RB4620.2
X789C67863FBCE430DA0E: RB4518.1, U4542.1
X799DB867A3031F5AB77F: RB4618.1, U4642.1
X853F40255E51475DF7A1: D4523.2, Q4507.2, RB4519.1, U4542.2
X867ABDC689D5BFF10061: Q4110.3, RB4122.2, RB4123.1, U4142.5
X2504E7ECC0354FA168E7: D4223.2, Q4207.2, RB4219.1, U4242.2
X3295DB827CE8AAE574FD: RB4324.1, U4342.7
X3439E778D35CDF6DFDF1: Q4108.3, RB4116.2, RB4117.1, U4142.3
X04963B7F211123194254: RB4318.1, U4342.1
X7307E027BF83453C3524: D11705.2, RB4520.2
X9141FD25BB2109174A88: U4442.8, U4442.9
X9858BBCA9970C9FCB86B: RB4524.1, U4542.7
X10852B4E217E1D395843: J900381.1, RB4216.1, RB4222.1
X25962DC0D080647130A4: U4542.13, U4542.14
X43904EB1FC7EDB0AA335: D11406.2, RB4226.2
X61003EE13806AD930803: J900387.5, Q4510.1, RB4527.1
X63613ECE89F282A509B6: J900383.3, Q4308.1, RB4321.1
X138812A99E0187B8D67A: D4625.2, Q4609.2, RB4625.1, U4642.6
X332730C2FDDA08CAED83: D4125.2, Q4109.2, RB4125.1, U4142.6
X634047C9CD5843892462: U4342.8, U4342.9
X4422711AFCCDBA718D4A: D4525.1, Q4509.1, RB4524.2
X53746081A37DAC301ADD: D11705.1, Q4507.3
X797009172D71EAFEBB1A: U4142.13, U4142.14
XA9DE434B9AA0F8C536DE: D11406.1, Q4209.3
XA68EA9E2F5379B7D8F08: D11305.1, Q4107.3
XAA0301884F69AD0E7337: J900379.5, Q4110.1, RB4127.1
XADBE90B291D159BD3BB1: D4523.1, Q4507.1, RB4518.2
XB2EBA66DAA21CB8551C8: RB4424.1, U4442.7
XB3B9A2AF2F7FA0D340E0: U4642.8, U4642.9
XB7B603420FD77620332F: D4425.1, Q4409.1, RB4424.2
XB7C2F315B2A72C7196F7: J900379.1, RB4116.1, RB4122.1
XB8D83C764066FEA571D7: J900381.5, Q4210.1, RB4227.1
XB9F0BC4557B5B5EF0AEC: Q4310.3, RB4322.2, RB4323.1, U4342.5
XB9FF60B0A66F70D425BE: D11805.1, Q4607.3
XB42EEE9219CFC7A853BD: D4323.1, Q4307.1, RB4318.2
XB899437C2EA9066F92F1: D4623.1, Q4607.1, RB4618.2
XBE667D2100526CFBC980: Q4510.3, RB4522.2, RB4523.1, U4542.5
XBED0A5748F4252A15663: D11306.2, RB4126.2
XC63C4BF13BA35D8AB361: D11806.2, RB4626.2
XCBB338FD60809F1C4554: U4242.13, U4242.14
XCF0902D8596AED7F7C86: D11505.1, Q4307.3
XCF44320172AB28A8C69A: U4642.13, U4642.14
XD5D1FFC8551A1CE41366: RB4418.1, U4442.1
XDCA4AB4D7D77D8669D15: Q4610.3, RB4622.2, RB4623.1, U4642.5
XDFCEC6E90F901E5E001F: D11506.2, RB4326.2
XE0FCBC3BB1F0803DF2AA: RB4218.1, U4242.1
XE1BE3DF4F60D2EE008D3: U4242.8, U4242.9
XE56B22348305C8B48C30: D4225.2, Q4209.2, RB4225.1, U4242.6
XE88A58D060DEC4E258C1: D4623.2, Q4607.2, RB4619.1, U4642.2
XE5206E58490CA0C0DF9B: D11506.1, Q4309.3
XE81531DE199582BE1344: J900389.5, Q4610.1, RB4627.1
XE1168244D1DE58C973DA: J900387.3, Q4508.1, RB4521.1
XEBD613C7EBC4FC656B12: D4223.1, Q4207.1, RB4218.2
XEE002239713F1E6CFAB6: D4123.1, Q4107.1, RB4118.2
XEEC69D3919A8A746094D: U4142.8, U4142.9
XEEFC9E5D4F8B5267F230: D4425.2, Q4409.2, RB4425.1, U4442.6
XF03AEC4C984C52D7EB57: D4525.2, Q4509.2, RB4525.1, U4542.6
XF5E48AE779812F227AE3: D4625.1, Q4609.1, RB4624.2
XF14FD29BB5FDF6626F7F: U4542.8, U4542.9
XF217E605C28C4AFFF4AE: D11306.1, Q4109.3
XFB651FD5AA7E9ACFDC9E: Q4208.3, RB4216.2, RB4217.1, U4242.3
XFC4750185D5F3794B5AF: D4123.2, Q4107.2, RB4119.1, U4142.2
XFD5706614908F1E1329B: J900379.3, Q4108.1, RB4121.1
XFF1B5FFC9904605776EA: RB4118.1, U4142.1

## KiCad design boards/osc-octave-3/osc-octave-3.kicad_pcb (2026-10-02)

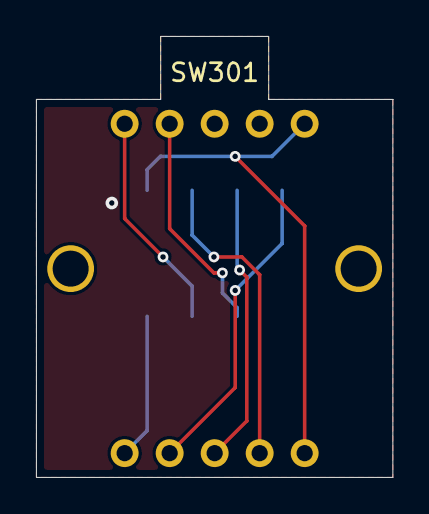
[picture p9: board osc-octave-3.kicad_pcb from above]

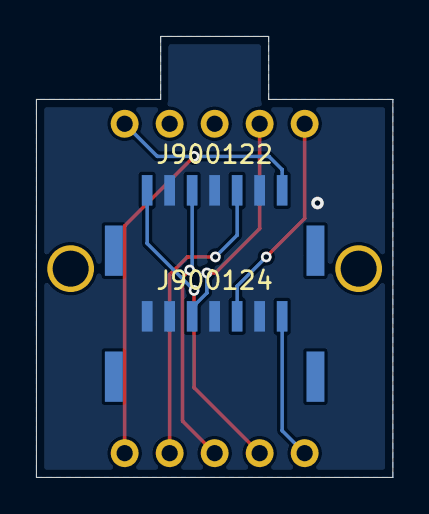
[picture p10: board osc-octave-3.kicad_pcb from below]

Board: 2 copper layers, 19.8 x 24.5 mm, 3 parts (2 on the bottom side), 8 nets.

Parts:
J900122, J900124: BM07B-GHS-TBT(LF)(SN); JST_GH7_BM_TopEntry
SW301: SRBV160803

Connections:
AGND: J900122.2, J900122.4, J900122.6, J900124.2, J900124.4, J900124.6, J900124.7
X5CF52A5D3BDB84554948: J900122.3, SW301.2
X5D31DD5D6E642F7542A9: J900122.1, SW301.1, SW301.10
X9CC58764476721DDB0F8: J900124.3, SW301.6
X56C3D53C39023A952E08: J900122.7, SW301.4
XA9392E54A81C8E2987E0: J900122.5, SW301.3
XE979A9D83B4902B292ED: J900124.1, SW301.5
XFE31B748A31181E56A8B: J900124.5, SW301.7

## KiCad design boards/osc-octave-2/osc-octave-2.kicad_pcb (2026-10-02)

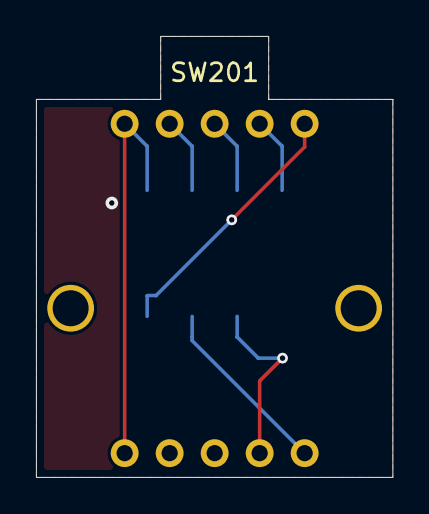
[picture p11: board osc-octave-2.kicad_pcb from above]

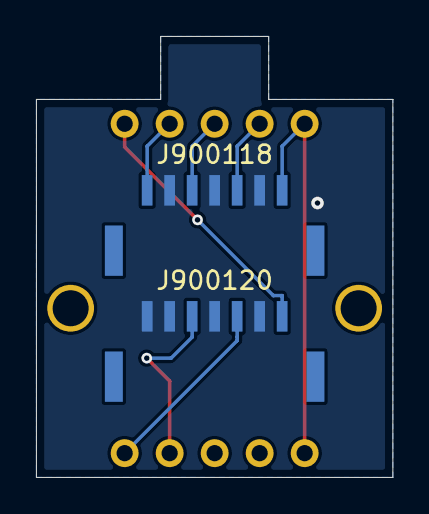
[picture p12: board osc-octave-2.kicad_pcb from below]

Board: 2 copper layers, 19.8 x 24.5 mm, 3 parts (2 on the bottom side), 8 nets.

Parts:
J900118, J900120: BM07B-GHS-TBT(LF)(SN); JST_GH7_BM_TopEntry
SW201: SRBV160803

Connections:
AGND: J900118.2, J900118.4, J900118.6, J900120.2, J900120.4, J900120.6, J900120.7
X5CF52A5D3BDB84554948: J900118.3, SW201.2
X9CC58764476721DDB0F8: J900120.3, SW201.6
X56C3D53C39023A952E08: J900118.7, SW201.4
X64D220928EDA3905C0D6: J900118.1, SW201.1, SW201.10
XA9392E54A81C8E2987E0: J900118.5, SW201.3
XE979A9D83B4902B292ED: J900120.1, SW201.5
XFE31B748A31181E56A8B: J900120.5, SW201.7

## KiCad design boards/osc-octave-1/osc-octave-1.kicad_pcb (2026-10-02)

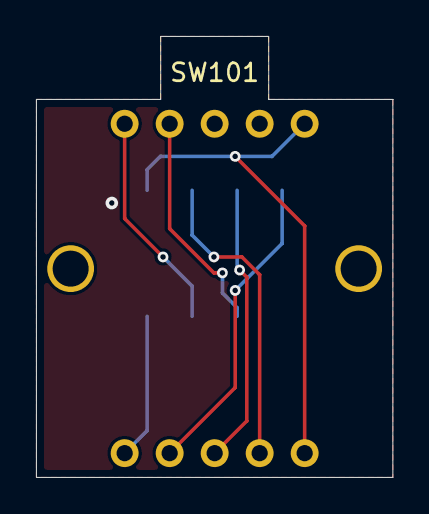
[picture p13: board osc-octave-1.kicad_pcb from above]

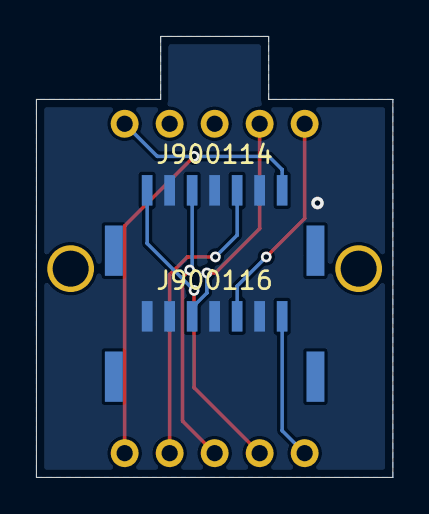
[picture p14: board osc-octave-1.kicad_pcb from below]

Board: 2 copper layers, 19.8 x 24.5 mm, 3 parts (2 on the bottom side), 8 nets.

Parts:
J900114, J900116: BM07B-GHS-TBT(LF)(SN); JST_GH7_BM_TopEntry
SW101: SRBV160803

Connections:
AGND: J900114.2, J900114.4, J900114.6, J900116.2, J900116.4, J900116.6, J900116.7
X5CF52A5D3BDB84554948: J900114.3, SW101.2
X9CC58764476721DDB0F8: J900116.3, SW101.6
X56C3D53C39023A952E08: J900114.7, SW101.4
X90EEDB72A75DC6F13F0D: J900114.1, SW101.1, SW101.10
XA9392E54A81C8E2987E0: J900114.5, SW101.3
XE979A9D83B4902B292ED: J900116.1, SW101.5
XFE31B748A31181E56A8B: J900116.5, SW101.7

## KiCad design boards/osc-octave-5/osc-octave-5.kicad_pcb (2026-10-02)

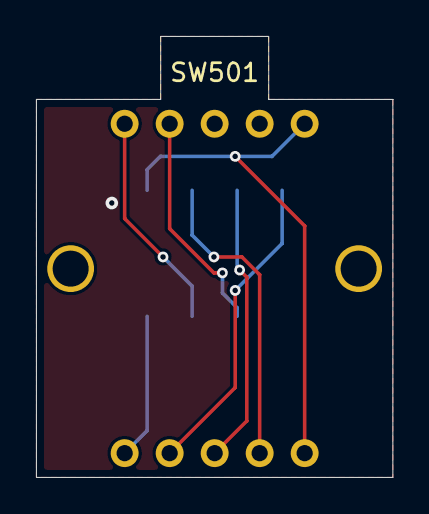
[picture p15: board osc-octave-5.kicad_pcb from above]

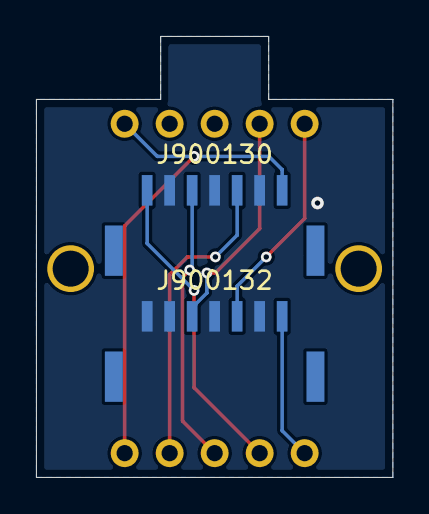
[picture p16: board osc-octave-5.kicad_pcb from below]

Board: 2 copper layers, 19.8 x 24.5 mm, 3 parts (2 on the bottom side), 8 nets.

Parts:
J900130, J900132: BM07B-GHS-TBT(LF)(SN); JST_GH7_BM_TopEntry
SW501: SRBV160803

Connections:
AGND: J900130.2, J900130.4, J900130.6, J900132.2, J900132.4, J900132.6, J900132.7
X5CF52A5D3BDB84554948: J900130.3, SW501.2
X9CC58764476721DDB0F8: J900132.3, SW501.6
X56C3D53C39023A952E08: J900130.7, SW501.4
X570616CB52B08D70FD0C: J900130.1, SW501.1, SW501.10
XA9392E54A81C8E2987E0: J900130.5, SW501.3
XE979A9D83B4902B292ED: J900132.1, SW501.5
XFE31B748A31181E56A8B: J900132.5, SW501.7

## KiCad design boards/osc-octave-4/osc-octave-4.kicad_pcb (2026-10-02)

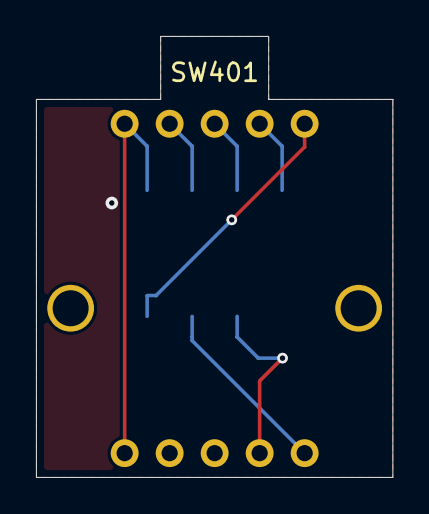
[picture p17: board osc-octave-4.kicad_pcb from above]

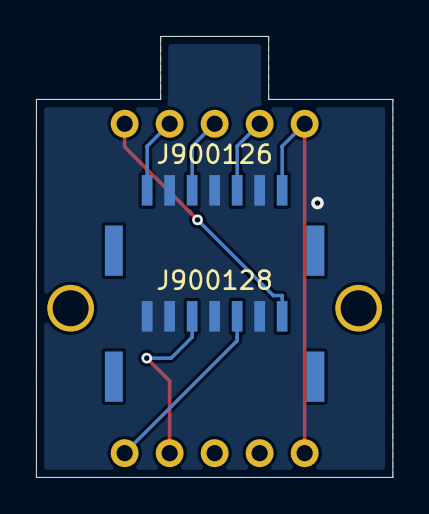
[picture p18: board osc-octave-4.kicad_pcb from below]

Board: 2 copper layers, 19.8 x 24.5 mm, 3 parts (2 on the bottom side), 8 nets.

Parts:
J900126, J900128: BM07B-GHS-TBT(LF)(SN); JST_GH7_BM_TopEntry
SW401: SRBV160803

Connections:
AGND: J900126.2, J900126.4, J900126.6, J900128.2, J900128.4, J900128.6, J900128.7
X5CF52A5D3BDB84554948: J900126.3, SW401.2
X9CC58764476721DDB0F8: J900128.3, SW401.6
X56C3D53C39023A952E08: J900126.7, SW401.4
X62232080C40C3946475B: J900126.1, SW401.1, SW401.10
XA9392E54A81C8E2987E0: J900126.5, SW401.3
XE979A9D83B4902B292ED: J900128.1, SW401.5
XFE31B748A31181E56A8B: J900128.5, SW401.7

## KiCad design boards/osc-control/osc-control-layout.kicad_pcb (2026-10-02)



Board: 4 copper layers, 316.0 x 116.0 mm, 454 parts (279 on the bottom side), 348 nets, no tracks yet.

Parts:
C103, C203, C4104, C4105, C4106, C4107, C4204, C4205, C4206, C4207, C4304, C4305, C4306, C4307, C4404, C4405, C4406, C4407, C4504, C4505, C4506, C4507, C4604, C4605, C4606, C4607: 1e-07 F; C0603
C107, C108, C109, C110, C111, C207, C208, C209, C210, C211: 1e-07 F; C1206
C121, C122, C130, C221, C222, C230, C3306, C3307, C3406, C3407, C4156, C4256, C4356, C4456, C4556, C4656: 100 nF; C0603
C4103, C4203, C4303, C4403, C4503, C4603: 1 µF; C0603
J900052, J900054, J900056, J900058, J900134, J900136, J900138, J900140, J900142, J900144, J900146, J900148, J900150, J900152, J900154, J900156, J900158, J900160, J900162, J900164, J900166, J900168, J900170, J900172, J900174, J900176, J900178, J900180, J900182, J900184, J900186, J900188, J900190, J900192, J900194, J900196, J900198, J900200, J900202, J900204, J900206, J900208, J900210, J900212, J900214, J900216, J900218, J900220, J900222, J900224, J900226, J900228, J900230, J900232, J900234, J900236, J900238, J900240, J900242, J900244, J900246, J900248, J900250, J900252, J900254, J900256, J900258, J900260, J900262, J900264, J900266, J900268, J900270, J900272, J900274, J900276, J900278, J900280, J900282, J900284, J900286, J900288, J900290, J900292, J900294, J900296, J900298, J900300, J900302, J900304, J900306, J900308, J900310, J900312, J900314, J900316, J900318, J900320, J900322, J900324, J900326, J900328, J900330, J900332, J900334, J900336, J900338, J900340, J900342, J900344, J900346, J900348, J900350, J900352, J900354, J900356, J900358, J900360, J900362, J900364, J900366, J900368, J900370, J900372, J900374, J900376, J900378: BM03B-GHS-TBT(LF)(SN); JST_GH3_BM_TopEntry
MH_P-OPT-2, MH_P-OPT-3, MH_P-OPT-4, MH_P-OPT-5, MH_P-OPT-6, MH_P-OPT-7, MH_P-OPT-9, MH_P-OPT-10, MH_P-OPT-11, MH_P-OPT-12, MH_P-OPT-13, MH_P-OPT-14, MH_P-OPT-16, MH_P-OPT-17, MH_P-OPT-18, MH_P-OPT-19, MH_P-OPT-20, MH_P-OPT-21, MH_P-OPT-23, MH_P-OPT-24, MH_P-OPT-25, MH_P-OPT-26, MH_P-OPT-27, MH_P-OPT-28, MH_P-OPT-30, MH_P-OPT-31, MH_P-OPT-32, MH_P-OPT-33, MH_P-OPT-34, MH_P-OPT-35: NPTH mounting hole
MH_P-SUP-1, MH_P-SUP-2, MH_P-SUP-3, MH_P-SUP-4, MH_P-SUP-5, MH_P-SUP-6: NPTH mounting hole
R118, R218, R4122, R4124, R4126, R4128, R4130, R4222, R4224, R4226, R4228, R4230, R4322, R4324, R4326, R4328, R4330, R4422, R4424, R4426, R4428, R4430, R4522, R4524, R4526, R4528, R4530, R4622, R4624, R4626, R4628, R4630: 10000 Ω; R0603
R119, R219, R4123, R4125, R4127, R4129, R4131, R4223, R4225, R4227, R4229, R4231, R4323, R4325, R4327, R4329, R4331, R4423, R4425, R4427, R4429, R4431, R4523, R4525, R4527, R4529, R4531, R4623, R4625, R4627, R4629, R4631: 1000 Ω; R0603
R124, R224: 2200 Ω; R0603
R3309, R3310, R3409, R3410: 2.2 kΩ; R0603
R3311, R3411: 10 MΩ; R0603
R3312, R3313, R3412, R3413: 499 Ω; R_1210_3225Metric
RV104, RV105, RV107, RV204, RV205, RV207, RV304, RV305, RV307, RV404, RV405, RV407, RV504, RV505, RV507, RV601, RV602, RV605, RV701, RV702, RV705, RV801, RV802, RV805, RV907, RV908, RV1106, RV1107, RV1108, RV1206, RV1305, RV1306, RV1308, RV1405, RV1406, RV1408, RV1505, RV1506, RV1508, RV1605, RV1606, RV1608, RV1705, RV1706, RV1708, RV1805, RV1806, RV1808: PTV09A-4020F-B104; PTV09A-4020F
RV106, RV108, RV206, RV208, RV306, RV308, RV406, RV408, RV506, RV508, RV603, RV604, RV606, RV703, RV704, RV706, RV803, RV804, RV806, RV901, RV902, RV903, RV904, RV905, RV906, RV1001, RV1002, RV1003, RV1004, RV1005, RV1006, RV1007, RV1008, RV1101, RV1102, RV1103, RV1104, RV1105, RV1201, RV1202, RV1203, RV1204, RV1205, RV1207, RV1208, RV1307, RV1407, RV1507, RV1607, RV1707, RV1807: PTV09A-4020F-B103; PTV09A-4020F
RV807, RV808: PTV09A-4020F-B504; PTV09A-4020F
SW102, SW202, SW302, SW402, SW502, SW608, SW708, SW1302, SW1303, SW1402, SW1403, SW1502, SW1503, SW1602, SW1603, SW1702, SW1703, SW1802, SW1803: 2MS1T1B1M2QES-5; Toggle_Dailywell_2MS_T1B1M2
SW103, SW203, SW303, SW403, SW503, SW1301, SW1401, SW1501, SW1601, SW1701, SW1801: 2MS3T1B1M2QES; Toggle_Dailywell_2MS_T1B1M2
SW607, SW707, SW1304, SW1404, SW1504, SW1604, SW1704, SW1804: B3F-1020; Button_Omron_B3F_6x6_P6.5x4.5
TP990025, TP990027, TP990029, TP990031, TP990033, TP990035: LOAD WIRE SOLDER LAND; LoadWireTerminal_4x4mm
U102, U202, U3303, U3403: OPA4197IPWR; TSSOP-14_4.4x5mm_P0.65mm
U108, U208, U4111, U4211, U4311, U4411, U4511, U4611: SN74HC14DR; SOIC-14_3.9x8.7mm_P1.27mm

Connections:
+5V: C130.1, C230.1, C4156.1, C4256.1, C4356.1, C4456.1, C4556.1, C4656.1, R118.1, R218.1, R4122.1, R4124.1, R4126.1, R4128.1, R4130.1, R4222.1, R4224.1, R4226.1, R4228.1, R4230.1, R4322.1, R4324.1, R4326.1, R4328.1, R4330.1, R4422.1, R4424.1, R4426.1, R4428.1, R4430.1, R4522.1, R4524.1, R4526.1, R4528.1, R4530.1, R4622.1, R4624.1, R4626.1, R4628.1, R4630.1, TP990029.1, U108.14, U208.14, U4111.14, U4211.14, U4311.14, U4411.14, U4511.14, U4611.14
+12V: C122.1, C222.1, C3306.1, C3406.1, TP990025.1, U102.4, U202.4, U3303.4, U3403.4
-12V: C121.1, C221.1, C3307.1, C3407.1, TP990027.1, U102.11, U202.11, U3303.11, U3403.11
AGND: C103.2, C107.2, C108.2, C109.2, C110.2, C111.2, C121.2, C122.2, C130.2, C203.2, C207.2, C208.2, C209.2, C210.2, C211.2, C221.2, C222.2, C230.2, C3306.2, C3307.2, C3406.2, C3407.2, C4103.2, C4104.2, C4105.2, C4106.2, C4107.2, C4156.2, C4203.2, C4204.2, C4205.2, C4206.2, C4207.2, C4256.2, C4303.2, C4304.2, C4305.2, C4306.2, C4307.2, C4356.2, C4403.2, C4404.2, C4405.2, C4406.2, C4407.2, C4456.2, C4503.2, C4504.2, C4505.2, C4506.2, C4507.2, C4556.2, C4603.2, C4604.2, C4605.2, C4606.2, C4607.2, C4656.2, J900052.2, J900054.2, J900056.2, J900058.2, J900134.2, J900136.2, J900138.2, J900140.2, J900142.2, J900144.2, J900146.2, J900148.2, J900150.2, J900152.2, J900154.2, J900156.2, J900158.2, J900160.2, J900162.2, J900164.2, J900166.2, J900168.2, J900170.2, J900172.2, J900174.2, J900176.2, J900178.2, J900180.2, J900182.2, J900184.2, J900186.2, J900188.2, J900190.2, J900192.2, J900194.2, J900196.2, J900198.2, J900200.2, J900202.2, J900204.2, J900206.2, J900208.2, J900210.2, J900212.2, J900214.2, J900216.2, J900218.2, J900220.2, J900222.2, J900224.2, J900226.2, J900228.2, J900230.2, J900232.2, J900234.2, J900236.2, J900238.2, J900240.2, J900242.2, J900244.2, J900246.2, J900248.2, J900250.2, J900252.2, J900254.2, J900256.2, J900258.2, J900260.2, J900262.2, J900264.2, J900266.2, J900268.2, J900270.2, J900272.2, J900274.2, J900276.2, J900278.2, J900280.2, J900282.2, J900284.2, J900286.2, J900288.2, J900290.2, J900292.2, J900294.2, J900296.2, J900298.2, J900300.2, J900302.2, J900304.2, J900306.2, J900308.2, J900310.2, J900312.2, J900314.2, J900316.2, J900318.2, J900320.2, J900322.2, J900324.2, J900326.2, J900328.2, J900330.2, J900332.2, J900334.2, J900336.2, J900338.2, J900340.2, J900342.2, J900344.2, J900346.2, J900348.2, J900350.2, J900352.2, J900354.2, J900356.2, J900358.2, J900360.2, J900362.2, J900364.2, J900366.2, J900368.2, J900370.2, J900372.2, J900374.2, J900376.2, J900378.2, R3311.2, R3411.2, RV106.1, RV107.1, RV108.1, RV206.1, RV207.1, RV208.1, RV306.1, RV307.1, RV308.1, RV406.1, RV407.1, RV408.1, RV506.1, RV507.1, RV508.1, RV601.1, RV602.1, RV603.1, RV604.1, RV605.1, RV606.1, RV701.1, RV702.1, RV703.1, RV704.1, RV705.1, RV706.1, RV801.1, RV802.1, RV803.1, RV804.1, RV805.1, RV806.1, RV901.1, RV902.1, RV903.1, RV904.1, RV905.1, RV906.1, RV907.1, RV1001.1, RV1002.1, RV1003.1, RV1004.1, RV1005.1, RV1006.1, RV1007.1, RV1008.1, RV1101.1, RV1102.1, RV1103.1, RV1104.1, RV1105.1, RV1106.1, RV1107.1, RV1201.1, RV1202.1, RV1203.1, RV1204.1, RV1205.1, RV1206.1, RV1207.1, RV1208.1, RV1305.1, RV1306.1, RV1307.1, RV1405.1, RV1406.1, RV1407.1, RV1505.1, RV1506.1, RV1507.1, RV1605.1, RV1606.1, RV1607.1, RV1705.1, RV1706.1, RV1707.1, RV1805.1, RV1806.1, RV1807.1, SW102.1, SW202.1, SW302.1, SW402.1, SW502.1, SW607.1, SW607.2, SW707.1, SW707.2, SW1301.2, SW1302.2, SW1303.2, SW1304.1, SW1304.2, SW1401.2, SW1402.2, SW1403.2, SW1404.1, SW1404.2, SW1501.2, SW1502.2, SW1503.2, SW1504.1, SW1504.2, SW1601.2, SW1602.2, SW1603.2, SW1604.1, SW1604.2, SW1701.2, SW1702.2, SW1703.2, SW1704.1, SW1704.2, SW1801.2, SW1802.2, SW1803.2, SW1804.1, SW1804.2, TP990031.1, TP990033.1, TP990035.1, U102.10, U102.12, U108.3, U108.5, U108.7, U108.9, U108.11, U108.13, U202.10, U202.12, U208.3, U208.5, U208.7, U208.9, U208.11, U208.13, U3303.5, U3303.10, U3303.12, U3403.5, U3403.10, U3403.12, U4111.7, U4111.13, U4211.7, U4211.13, U4311.7, U4311.13, U4411.7, U4411.13, U4511.7, U4511.13, U4611.7, U4611.13
X0B4A0A5D45814E9D95C7: U3303.13, U3303.14
X0B332CC3F3D75834394B: J900344.1, RV404.3, RV405.3, RV407.3
X0B475DAB16A59C025E35: J900170.1, U4111.10
X0C487389EDA1C803A833: J900304.3, SW102.2
X00D3BCB5E0AFD29A84DF: J900314.1, SW203.1
X0E3CA1A11E5FE92DB152: J900242.1, U108.2
X0F98EC836B304857ABC5: C4404.1, R4425.2, U4411.3
X01A05DBEFB68471D9824: J900186.1, U4311.10
X1A9EF65F44F4B29DE1DC: J900368.1, RV1207.3
X1B3E855D0EAF37C63927: J900326.3, RV306.3
X1B80C209713652D469B7: J900328.3, SW302.3
X1B787BB4D565EE8CF824: R4226.2, R4227.1, SW1401.3
X1C49E274E70449E3D265: R3309.2, SW608.3
X1C545F78A9EEA47275D3: J900148.3, RV1608.2
X1CB7E660D7B486B8C4E6: J900056.1, R3313.2
X1D7C13EF0F0429C157CA: J900212.3, RV603.2
X1DA6F66C3F8A34A27A5F: U3403.6, U3403.7
X1DA464D505A944A51104: J900360.1, RV508.3
X1E5E726E8BFBF2C8D7CB: J900198.3, RV1706.2
X1EA7A310545B3EA7B872: C4603.1, R4623.2, U4611.1
X1F3BE2B0C54B7392AAD2: J900214.1, RV602.2
X1FFDC49339C7C2982F1A: J900256.1, RV1102.2
X2B2FD6CD1D1554A8B31B: J900164.1, U4111.4
X2BCD7805C65AE3992EDF: R4628.2, R4629.1, SW1802.3
X2CA281339CB17909B79A: J900332.1, RV308.3
X02CB8FF55279DAA45A09: J900196.1, U4511.4
X2D597327EED2D1A7509E: J900162.3, RV1808.1
X2DAE1746253A01B64F3C: J900346.1, RV408.3
X2F4053E8598569E6249E: J900362.3, SW503.2
X3A090CBB9D59BF6BFA74: C103.1, R119.2, U108.1
X3AACF3FE67214DD30896: R4422.2, R4423.1, SW1604.3, SW1604.4
X3B8BA61DD852C09F9593: J900182.1, RV1505.2
X3B24EF7B17B8D143C1C5: J900058.3, R3413.2
X3BE215420217265BBCC4: J900330.3, RV304.1, RV305.1
X3C4EB2F54BEF66A2BDCD: J900372.1, RV908.2
X3C30CF4F46CC9EAA54FD: C4405.1, R4427.2, U4411.5
X3CB093BB7419E86B97DC: J900198.1, RV1705.2
X3D9DB9D8CDF65F493A37: J900208.1, U4611.6
X3DAC76D7A558264A3F1B: J900260.3, RV1204.3
X3F9931ACD1A8A527BDB6: J900274.3, RV906.2
X3FCBFC999FCAA257D324: R4622.2, R4623.1, SW1804.3, SW1804.4
X4AD789F56C4006DE7DA9: J900264.1, RV1206.2
X4C73DFC1A892FFD889F5: C4205.1, R4227.2, U4211.5
X4E9DA5171986B7A73694: J900292.1, RV1004.2
X04EB6B3DC069E08BFECF: J900310.3, RV207.2
X4F82C77EF7F47F31A68A: J900306.3, SW103.2
X5AC892F0D8CDA44E7E18: J900322.3, RV308.2
X05B3B6DFB0CF591143F1: J900374.1, RV907.2
X5BC1C28EAF5D67603036: J900340.3, RV406.3
X5BDE0CC9A020C6F2E113: J900136.3, RV1308.3
X5E1E2BAA433858C2BF43: U202.8, U202.9
X5EE2EC8E69809DDC2E3E: C4306.1, R4329.2, U4311.9
X5FA328E898DBF1047AD9: J900140.3, RV1407.3
X06C7F5D4F085BBED1E86: J900370.3, RV1108.1
X6C227D1A4FFD615CE3B4: J900152.1, RV1608.3
X6EAF3E6A330509674504: R4426.2, R4427.1, SW1601.3
X6F1E82B9DD7E6011E5A7: U3403.8, U3403.9
X7B5C74E08F15CF029DD6: J900256.3, RV1106.3
X7B7BDD1C1DB4BA20302F: C4106.1, R4129.2, U4111.9
X7B6418A02124BE1D6A53: J900346.3, SW402.2
X7CA4825DF75BA1068B88: J900312.3, RV206.3
X7DF116D877C176D3E3C1: R4230.2, R4231.1, SW1403.3
X7EC00F55D7B5A706ABE8: J900160.1, RV1807.2
X7EED3C2496125C7B4C01: J900226.3, RV704.2
X7FF164FB414EE3E69E00: J900348.1, SW403.3
X8A7D7D29E8DC52F3CE4A: J900206.1, RV1805.2
X8A58565164C7AD5DB771: J900210.3, U4611.2
X08AB1FE396D2383E44F4: J900210.1, U4611.10
X8B9429ACCBF48C55D3C2: C4607.1, R4631.2, U4611.11
X8BE7E102E23D65C3BAE8: C4304.1, R4325.2, U4311.3
X8D47F4038AE6E42915B2: J900300.3, SW102.3
X8D097FC3EE080878BFAC: J900234.3, RV805.2
X8EE69A8E59E4947794DE: R224.2, RV808.1
X8F338CC60323B9942D2C: C4103.1, R4123.2, U4111.1
X8FFBDC9C42EC02C29B2F: J900278.1, RV902.2
X9A2A689D1C741BE6AFED: J900280.1, RV904.2
X9A343D229ADA66A13020: J900176.3, RV1405.3, RV1406.3
X9A815A035049F63C9E88: J900244.1, U208.2
X9B0D87C92BF046274E53: U202.13, U202.14
X9C285D3C07BA239ADB72: J900324.3, RV307.2
X9D8BBA8996899EAF9E11: R4424.2, R4425.1, SW1601.1
X9D084A84DCD90DC3DD20: R218.2, R219.1, SW707.3, SW707.4
X9D0800DA698428AE22E5: J900366.1, RV1107.2
X9F7D653AF2B7E248C875: J900232.1, RV801.2
X9F175A89D847BE3F6D46: J900226.1, RV706.2
X9F47443B516E90FF872D: J900302.3, RV104.1, RV105.1
X10EF5F2EA06ABBC332A2: J900146.1, RV1507.3
X11FD029782B329BAC0F5: J900192.1, U4411.6
X14E3C0C55CB1C4A95F24: J900286.1, RV1005.3
X17D4FDC40CFD180B1BD2: J900168.1, U4111.6
X21BEBE4AB581C385D0B8: R4130.2, R4131.1, SW1303.3
X24E3C16307B2FAA35477: J900222.3, RV703.2
X27B80377B6C412E86A02: J900286.3, RV1006.2
X27C28FDCAA9450E228E6: J900272.1, RV903.3
X32DCB2CFC06DB06B386F: R4228.2, R4229.1, SW1402.3
X33CA5B7F1AD1677C7737: J900254.1, RV1103.2
X0034A88A682FE94105E3: R224.1, U202.1, U202.2
X35C328C82C2EDBE601ED: J900182.3, RV1506.2
X35E86F1B470C2BA578A1: J900354.3, RV506.3
X36A08C40CCEBB620DE23: R3412.2, R3413.1
X37C0D40E8793B92EA1B7: J900330.1, RV304.3, RV305.3, RV307.3
X37DEB0D3B35ED7C3B732: J900054.1, R3309.1
X41B88AA72B8A732B279A: J900316.3, RV204.1, RV205.1
X44CC9CDFCD3CBADF5D00: J900298.1, RV105.2
X45AEDA7EA8DE3AE9B3ED: J900162.1, RV1808.3
X47A1F716E3FE17CD7494: J900142.3, RV1408.1
X47F88BF45C5E2E011545: J900218.3, RV606.3
X48EC6FDDD901F447E0D7: J900138.3, RV1408.2
X48FE18B13B6BACB7D2F3: J900150.1, RV1607.2
X53E6848A29A94622ABBC: J900332.3, SW302.2
X056B4CC99FD47B93EDCC: J900224.3, RV705.2
X57F83BC709B895AAD727: R4430.2, R4431.1, SW1603.3
X59AF92DF21D7A5330CF8: C4207.1, R4231.2, U4211.11
X61C55F327009ADDFA763: J900348.3, SW403.2
X65AE667238FA95A8F74F: J900338.3, RV407.2
X65E4D2E1B5D6DE7493A2: J900242.3, U102.3
X65EF910626D86173FCAE: R3312.1, U3303.1, U3303.2
X67D9684AF7D381D085BB: J900150.3, RV1607.3
X69F956D2CD0D8F7D7812: J900184.3, RV1505.3, RV1506.3
X70DC76294A6404803334: J900282.1, RV1001.3
X70FF44125622536BA5C7: J900052.3, U202.6, U202.7
X73DBDA5E90E6EB5C88CC: J900160.3, RV1807.3
X73DCD6567A68738230C2: C4605.1, R4627.2, U4611.5
X74FE612A599C88EF9232: J900202.3, U4511.2
X76CBC2A15ACB37487709: J900250.3, RV1104.2
X76D81676C30D329CC9B5: J900288.3, RV1003.2
X77E7E88701ED796DE532: C107.1, C108.1, C109.1, C110.1, C111.1, RV807.2, RV807.3, U102.5
X78C1702B66BDCEBC593E: J900276.3, RV903.2
X79AAE9302AB11BB4C973: J900144.3, RV1507.2
X80E184FE788FFBE8EA58: J900378.3, RV908.1
X84A4FF7293A182F02A4A: R4524.2, R4525.1, SW1701.1
X85E738180F5C70F1A457: J900222.1, RV701.2
X89D5E3CA45DE92E8F54F: J900192.3, RV1605.3, RV1606.3
X91AB2074CD577F2FF2D8: J900248.1, RV1103.3
X92D58D65DA2819F30731: J900216.3, RV604.2
X92F7EC5BF13E7E12AB51: J900320.1, SW203.3
X93B85254A7CAE093D017: J900368.3, RV1208.3
X94AE1057F6F6F403AA12: R4522.2, R4523.1, SW1704.3, SW1704.4
X97ED0B30E9679E8FC3C2: J900218.1, RV603.3
X110EF417EBA43801D3CA: J900298.3, RV106.3
X130E2D2473EEC58833A8: J900184.1, U4311.6
X144C922A18FA87072963: J900350.1, RV506.2
X146B2E086CDC142CF6D6: J900356.1, SW503.1
X214ED5A8892039CF8AA7: J900168.3, RV1305.3, RV1306.3
X387EC52CA3999BB128B1: J900244.3, U202.3
X476A0733582A82F0AEB8: C4307.1, R4331.2, U4311.11
X489F21AF98C74FBB046F: J900252.3, RV1105.2
X494A69F57398E0094B88: J900318.3, SW202.2
X514AF48BBD9C212363F8: J900134.3, RV1307.2
X547DC548216A545CE445: R3310.2, SW608.1
X567D5C752D604876B08A: J900276.1, RV901.2
X595CFB34B72941F8A5A8: C203.1, R219.2, U208.1
X599D6F008ACD4AF9DBB6: J900240.3, RV804.3
X652F7E92722B07CC611F: C4604.1, R4625.2, U4611.3
X664ED05EACC39FA0A717: C4204.1, R4225.2, U4211.3
X665F99D69A5D3F2A216F: J900246.3, RV1102.3
X695F4CDA5CB45DBBBA8D: J900364.1, RV1108.2
X741DF1C2056440887FCB: J900312.1, RV205.2
X763E77DF6D4025E687FA: J900300.1, SW103.1
X849EE8C41DE7382BA070: J900234.1, RV802.2
X927D723306618B2FA404: R4526.2, R4527.1, SW1701.3
X937C92F685B83C082055: J900366.3, RV1207.2
X1080B5575AB1BB1A0248: J900314.3, SW202.3
X1675C414E0F088C8B0F2: J900376.3, RV1008.3
X1897FA4CC6D2320FE9FC: R4530.2, R4531.1, SW1703.3
X2116EAF991E4FD59E329: J900052.1, U102.6, U102.7
X2235AA409133311006A2: J900268.3, RV1206.3
X2781F3EA18C148791B18: J900202.1, U4511.10
X2842A95258EB703DE67C: J900302.1, RV104.3, RV105.3, RV107.3
X3878A543A34D0072B9DD: J900260.1, RV1203.3
X03899EF77CFB15DF4250: J900306.1, SW103.3
X3977E5498D871E0002C5: C4105.1, R4127.2, U4111.5
X4838A855AA88CEFB49D1: J900354.1, RV505.2
X5270B2A325DCFA73F65F: J900236.1, RV806.2
X5585D1E58EEAC7D5FB9D: C4303.1, R4323.2, U4311.1
X05736A904C0279F1CE63: J900148.1, RV1508.1
X5768B5A3D3AC9B88DB51: J900352.3, RV507.2
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

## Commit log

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2026-09-27 Fix schematic label placement around pins
    [power.kicad_sch, synthetic.kicad_sch]
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2026-09-27 Add audited pot family and octave selector draft assets
    Retain manufacturer drawings and exact part records, generate library symbols and previews, and verify fixed control pitches in KiCad 10. Keep the selector mounting-hole collision open under issue #47.
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2026-09-27 Add deterministic update-in-place PCB draft generator
    Sync footprints and board geometry from netlist and fixed placement lock, preserve unowned board items, and verify parity and repeatability through the KiCad 10 oracle fixture.
    [fixture-jacks.kicad_pcb, fixture-jacks.kicad_sch, jacks.kicad_sch]
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2026-09-27 Implement OSC-ES-1 standard cell library
    Generate and verify all 19 reusable cells, retain a source-backed BAS16GW-QX diode correction, and record partial current and ideal-model results with open qualification gates.
    [bipolar_attenuverter.kicad_sch, clip_detector.kicad_sch, dc_control_source.kicad_sch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]
2026-09-27 Capture H1 and H2 sample-hold pilot module
    Compose OSC-ES-1 cells on one shared sheet with exact panel bindings, local hold/slew islands, source-level generator support, KiCad parity checks, and bounded current/SPICE reports.
    [pilot_power.kicad_sch, power.kicad_sch, sample_hold.kicad_sch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]
2026-09-27 Capture five AS3340 oscillators with shared octave reference
    [octave_reference.kicad_sch, oscillator.kicad_sch, zudo-osc-hole-field.kicad_sch]
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2026-09-28 Add generated front-panel PCB and visual evidence for issue #20
    [panel.kicad_pcb]
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2026-09-28 Capture four-colour noise source draft for issue #28
    [noise.kicad_sch, zudo-osc-hole-field.kicad_sch]
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2026-09-28 Capture MIX5 and MIX4 VCA draft families
    Bind all locked mixer hardware, generate shared KiCad sheets, and document current, ERC and model evidence. Keep the LM13700 full-scale model failure and bench gates explicit.
    [mix4_vca.kicad_sch, mix5.kicad_sch, zudo-osc-hole-field.kicad_sch]
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2026-09-28 Capture six attenuverter and offset cells for issue #26
    [offset.kicad_sch, zudo-osc-hole-field.kicad_sch]
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2026-09-28 Close master schematic integration gates
    Audit locked panel coverage, netlist parity, sensitive islands and all active units; terminate spare cells, refresh evidence, and record rail budget overshoot and draft exports.
    [bipolar_attenuverter.kicad_sch, clip_detector.kicad_sch, dc_control_source.kicad_sch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]
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2026-09-28 Calibrate MIX4 vendor model within captured trim ranges
    Freeze the offset and TIA settings across command and input vectors, fail model checks on headroom or gain regression, and retain the open feedthrough diagnostic.
2026-09-28 Define fixed-centre stepped selector assembly draft
    [panel.kicad_pcb]
2026-09-28 Resolve precision output model sweep and compensation
    [manual_ab.kicad_sch, mult.kicad_sch, offset.kicad_sch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]
2026-09-28 fix(pcbgen): close and reproduce the dense routing fixture gate
    [fixture-route-dense.kicad_pcb]
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2026-09-28 Implement bounded local oscillator reference fanout
    [oscillator.kicad_sch]
2026-09-28 Select exact compact indicator LEDs and audit fixed centres
    [clip_detector.kicad_sch, envelope.kicad_sch, filter.kicad_sch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]
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2026-09-28 Record unvalidated jack PCB draft and routing failure evidence
    [osc-jack.kicad_pcb]
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2026-09-30 fix(pcbgen): reconcile native routing gate with complete connectivity
    Integrate PR 67 while preserving issue-38 per-net connectivity. Require fresh matching native receipts, reject inconsistent named counts, retain timeout failures, and make refresh-only reports diagnostic. Exercise native success, replication, unchanged rerun and timeout fixtures; preserve the remaining issue-38 WIP.
2026-10-01 Checkpoint issue-38 engineering sources and preserve local artifact identities
    Retain unselected ground and rail candidate generators, source/contact models, recovery checkpoints, evidence corrections and prior reviews. Keep 555 MB of experimental native boards local with a SHA-256 inventory. Separate portable tests from mandatory retained-artifact regressions without dropping assertions. This is an unvalidated source checkpoint, not issue-38 acceptance or a hardware release.
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2026-10-01 Add exact current-observation and regional transfer witness bounds
    Keep both global source budgets, preserve zero-net redistribution, and bound regional reciprocal transfers without subtracting private diagonals. Exercise closed-network current objectives against exact signed resistor-network solutions. These are conditional mathematical helpers; physical conductor admission and all issue-38 electrical limits remain open.
2026-10-01 Tighten main-wire cuts and derive core service depths
    Retain the ten-board K100/enclosure120 draft while requiring 110 mm main-wire cuts with the complete preparation allowance. Bind connector and loom receipts to their source and preserve historical electrical evidence at its original epoch. Joined electrical acceptance and physical qualification remain open.
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2026-10-01 Route negative fault veto through supervisor reset timing
    [MonitorPermit-p2.kicad_sch, MonitorPermit.kicad_sch]
2026-10-01 Fix IC display model axes and DIP body offset (#86)
    * Align provisional IC models with footprint body geometry
    * Verify aggregate source regeneration in CI
    * Refresh the generated DIP footprint receipt after placement correction
    * Prove peripheral source equivalence after display model correction
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2026-10-02 fix(pcbgen): require complete native reports and current project rules
    [fixture-route-dense.kicad_pcb]
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2026-10-02 Bind AO ideal model to captured wiring and correct partial error budget
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2026-10-02 fix(pcb): place complete slew circuits near fixed controls
    [sample_hold_H1_P.kicad_sch, sample_hold_H2_P.kicad_sch]
2026-10-02 Add five routed octave adapter PCB drafts with native source checks (#132)
    * Add five routed octave adapter PCB drafts and native source gates
    * Bind octave routing transition to regenerated ground net classes
    * test(pcb): preserve fixed faces in placer regression
    [osc-octave-1.kicad_pcb, osc-octave-2.kicad_pcb, osc-octave-3.kicad_pcb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]
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2026-10-02 Place complete slew circuits beside their fixed controls (#133)
    * fix(pcb): place complete slew circuits near fixed controls
    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
    [sample_hold_H1_P.kicad_sch, sample_hold_H2_P.kicad_sch]
2026-10-02 Add a reproducible unrouted control-board layout draft (#134)
    * feat(pcb): add reproducible unrouted control layout
    * fix(pcb): initialize cache for standalone control replay
    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
    [osc-control-layout.kicad_pcb, osc-control-layout.kicad_sch]
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2026-10-02 Connect 23 local control paths and verify per-net refill stability
    [osc-control-routed-draft.kicad_pcb]
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2026-10-03 Complete native connectivity of the control-board routed draft
    Close the last 15 native open edges of osc-control. The draft now has
    0 open edges, 0 DRC violations, 0 schematic-parity findings, 344/344
    ground contacts and 16/16 local bypass pairs after independent refill.
    - Re-check three multilayer signal links from the earlier batch one at a
    time (the old subset trials ran in a folder where the footprint library
    path did not resolve); adopt the passing ones.
    - Route the +12V/-12V terminal feeds, the last +5V pins and four long
    panel-signal links with a four-layer grid A* router at the source
    0.4 mm rail / 0.3 mm signal widths.
    - Free three boxed pins by rip-up and reroute of four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
    [osc-control-routed-draft.kicad_pcb]
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2026-10-03 Add placed and fully routed stage-optical PCB draft (#42)
    - Add draft routing classes (signals 0.25 mm, rails/AGND 0.4 mm, 0.25 mm
    clearance) and F.Cu/B.Cu AGND pours for osc-stage-optical.
    - Move free stage parts below the 11 mm passages: bottom-up packing,
    0.7 mm spacing, 1.5 mm around fixed LEDs, bypass capacitors nearest
    their amplifier. Fixed LEDs, passages and connectivity are unchanged.
    - Extend the peripheral source epoch with an exact stage-optical layout
    transition proof (free-part origins/angles, regions, routing only).
    - Sync representative multi-unit fields so schematic parity is clean.
    - Strip the SES placement block before import, add --max-passes, and add
    a grid maz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
    [envelope_E1_EL.kicad_sch, envelope_E2_EL.kicad_sch, envelope_E3_EL.kicad_sch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]
2026-10-03 Keep the connector-locality epoch byte-stable; add a stage-optical epoch
    The GH foil-collar proposal binds the connector-locality epoch by hash, so
    the stage-optical layout transition now writes its own epoch file that
    chains to it instead of rewriting it.
2026-10-03 Move jack halves to six layers with locality placement and grid routing
    Owner decision 2026-10-03 (#38): a cut-line bound showed the four-layer
    jack halves could not carry their signal nets with intact planes, so both
    halves move to six layers and their free packages are re-placed for
    locality.
    - Placement: scripts/checks/jack_locality.py replaces the
    connectivity-blind first-fit J placer. Packages are pulled toward the
    fixed jacks, LEDs and headers on their nets and toward their own
    module's hardware, then legalized; IC/bypass clusters stay aligned.
    Panel hardware and headers do not move.
    - Stack: F/In2/In3/B signals, In1 AGND plane, -12V fill on In3, +12V
    plane on In4; +5V as tr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
    [envelope_E1_JR.kicad_sch, envelope_E2_JR.kicad_sch, envelope_E3_JR.kicad_sch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]
2026-10-03 Restore ripped nets on rollback and tighten the -12V fill guard
    - route_jack_grid.py: when a stage drops links for DRC errors or a
    -12V split, a ripped net loses its whole new route and keeps its
    original copper, so a rollback can no longer leave it open (the cause
    of the non-adopted JL rrr-01 411 -> 421 trial). Receipts now record
    whether a stage was adopted.
    - grid_router.py: the fill guard models the native fill more
    conservatively (0.45 mm) and rip-up attempts log why they were
    skipped or undone.
    - osc-jack-right: checked rip-up stage 518 -> 516 open edges, 0 DRC
    errors, 0 parity; routed draft, qualification NOT RUN.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
2026-10-03 WIP: resumable negotiated routing with per-route footprints
    Soft via costs, own-pad exclusion from conflicts, bounded search windows,
    failure reasons for unroutable nets, and saved state between runs.
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2026-10-04 Revert the IC routing ring in the jack locality placer
    The ring raised JL net length (HPWL 25.5 -> 29.4 m, nets over 100 mm 4 -> 30)
    and negotiated routing on that placement plateaued at 648 open edges.
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2026-10-04 Add a same-footprint swap pass to the jack locality placer
    After legalization, packages with one footprint trade slots (side and rotation
    travel with the slot, so every swap stays legal) to cut span-weighted wire
    length with a quadratic penalty above 60 mm. Floorplan estimate: JL HPWL
    25.5 -> 18.1 m, nets over 60 mm 79 -> 21; JR 25.1 -> 18.0 m, 53 -> 13.
2026-10-04 Route jack-left with negotiated congestion to 360 open edges
    Locality placement with a 0.8 mm IC keep-clear ring on JL (JR keeps none),
    a native C grid A*, a PathFinder negotiated-congestion stage on a 0.05 mm
    grid, then rip-up-and-reroute and AGND stitching. Native: 360 open edges
    (main 411), 0 DRC errors, 0 schematic parity findings. Routed draft;
    electrical/physical qualification NOT RUN.
    [filter_F1_JL.kicad_sch, filter_F2_JL.kicad_sch, filter_F3_JL.kicad_sch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]
2026-10-04 Place and rail-route the six-layer core draft (#43)
    - Core through-hole packages (NOISE2 U6101) block both faces in the
    locality legalizer; the core POWER-* reserves are the TP load lands
    themselves and no longer emit keepouts over them.
    - sync projects the netlist's representative multi-unit fields on the
    core so schematic parity is clean.
    - route_jack_grid.py refuses an unclean start board, runs up to 40
    signal batches and skips empty ones.
    - Synced, placed and prepared osc-core board; rail plane fanout, rail
    links and rail escapes: 7355 -> 5849 native open edges with 0 DRC
    errors and 0 parity per stage. Routed draft in progress.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
    [envelope_E1_K.kicad_sch, envelope_E2_K.kicad_sch, envelope_E3_K.kicad_sch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]
2026-10-04 Regenerate after the main merge and add core native reports (#43)
    - Regenerated partition, orientation oracle, source epoch and foil-collar
    binding after merging main; the core netlist is unchanged.
    - Re-synced the core board (canonical block order) and ran the native
    check: 0 DRC errors, 0 parity, 5849 open edges.
    - Negotiated routing uses a 0.075 mm raster on the core for memory.
    - Add the core verification page.
2026-10-04 Place jack halves with span-aware swaps and route jack-left to 173 open edges
    [filter_F1_JL.kicad_sch, filter_F2_JL.kicad_sch, filter_F3_JL.kicad_sch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]
2026-10-04 Add an open-net negotiate stage; keep the swap pass on JL until JR is rebuilt
    negotiate-open renegotiates the still-open signal nets together with the nets
    whose copper lies within 1.5 mm of their pads; a net left in conflict keeps
    its old copper.
2026-10-04 WIP: spread core module homes and legalize module by module (#43)
    The first core negotiation stalled (2501/2727 nets in conflict after 7
    iterations). A RUDY map showed placement congestion: header-anchored
    homes crowded ~1300 E/A packages into one corner, so modules were
    scattered and 751 nets spanned 80 mm or more. Module home discs are now
    spread inside the outline and notch, packages are legalized one module
    at a time, and the core uses a 0.6 mm courtyard gap with a 0.5 mm IC
    channel. Floorplan proxy: HPWL 162 -> 139 m, peak RUDY 1.39 -> 1.09 of
    ideal four-signal-layer supply, tiles above 0.7 682 -> 160.
    [01_power_interfaces_POWER_K.kicad_sch, envelope_E1_K.kicad_sch, envelope_E2_K.kicad_sch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]
2026-10-04 WIP: same-footprint swap pass for the core placement (#43)
    Ported span-penalized slot swaps (nets over 60 mm pay a quadratic
    penalty), limited to same-footprint slots within 25 mm of each package's
    net median. Floorplan proxy: HPWL 139 -> 105 m, median span 28.8 mm,
    RUDY p99 0.78 with 68 tiles above 0.7 (JL with swaps: p99 0.81, 42).
    [01_power_interfaces_POWER_K.kicad_sch, envelope_E1_K.kicad_sch, envelope_E2_K.kicad_sch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]
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2026-10-05 Checkpoint the core draft at 2975 native open edges (#43)
    Re-placed v3 board: rail fanout and links, then the negotiated signal
    pass finalized at its saved iteration-44 state (conflicted nets left for
    rip-up). Every adopted stage passed native DRC with 0 errors and 0
    schematic parity issues. Routed draft in progress.
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2026-10-05 Rip up and reroute the core draft to 2077 native open edges (#43)
    rrr-01..08 after the negotiated pass: 2975 -> 2077 open edges, each stage
    natively checked with 0 DRC errors and 0 schematic parity issues.
2026-10-05 Gate the jack halves and core on native KiCad DRC in CI
    Runs pinned KiCad DRC with schematic parity and zone refill per board in
    parallel with the existing jobs, so routing sessions can rely on CI as the
    gate instead of running the native check locally. Unconnected items are
    reported; DRC errors and parity findings fail.
2026-10-05 Place jack-right with span-aware swaps and route it to 190 open edges
    Rebuilt from the swap-pass placement; rails, negotiated routing (1236 -> 283),
    re-offered rip-up, signal batches, AGND stitching and escapes. Reports come
    from the adopted stage's native DRC (0 errors, 0 parity) and native ratsnest.
    [envelope_E1_JR.kicad_sch, envelope_E2_JR.kicad_sch, envelope_E3_JR.kicad_sch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]
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2026-10-05 Route core signal batches to 1843 native open edges (#43)
    signals-local and signals-01..09 after rip-up: 2077 -> 1843, each stage
    natively checked with 0 DRC errors and 0 schematic parity issues. Batch
    yield fell to about 7 edges per stage, so rip-up re-offer rounds follow.
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2026-10-05 Reject a stage whose DRC errors cannot be dropped instead of aborting
    A candidate that keeps unattributable or persistent DRC errors, or splits a
    plane fill without attributable copper, now gets a rejected receipt; the
    previous board is kept and the run continues with the next stage.
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2026-10-05 Report jack-right at 177 open edges after CI routing
    Native DRC (0 errors, 0 parity), native ratsnest, routing.json, renders and the
    status table for the CI-routed board.
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2026-10-06 Add neck-down rule areas at jack IC pin rows
    Every IC with a pin on an open signal net gets a rule area over its pads plus
    2 mm (design/partition/neckdown-areas.json, scripts/pcbgen/neckdown_areas.py).
    The board .kicad_dru lets Default-class signal copper inside use 0.15 mm width
    and 0.15 mm signal-to-signal clearance; rails and AGND keep 0.25 mm. route()
    and negotiate() honour the rule per raster cell and draw neck segments at the
    neck width. Native DRC stays at 0 errors and 0 parity on both halves.
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2026-10-06 Start the core neck-down attempt from the 1841-edge board (#43)
    Board and stage receipts from ea407c4 (rrr-03 after the signal batches:
    1841 native open edges, 0 DRC errors, 0 schematic parity issues).
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2026-10-06 Add neck-down rule-area tooling and settle zone refills in stage checks
    - neckdown_areas.py: --select records the ICs with pads on open Default-class
    nets; the default mode draws pcbgen:<board>:neckdown rule areas over their
    pads plus 2 mm and writes <board>.kicad_dru (0.15 mm Default-class width and
    signal-to-signal clearance; rails and AGND keep their net-class clearance).
    - grid_router: route() and negotiate() honour the areas per raster cell; path
    points carry a neck flag and copper_rows draws neck segments at 0.15 mm.
    Rip-up unpacks neck-flagged points.
    - route_jack_grid: passes the rule to signal stages, copies .kicad_dru into
    stage workspaces, and refills zones until islan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
2026-10-06 Add neck-down rule areas to the core draft (#43)
    326 ICs with a pad on an open signal net get pads + 2 mm rule areas on the
    signal layers; boards/osc-core/osc-core.kicad_dru allows 0.15 mm
    Default-to-Default clearance and 0.15 mm track width inside them. Rails and
    AGND keep their net-class clearance. Unvalidated draft tooling.
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2026-10-06 Report the jack halves at 156 and 175 open edges after neck-down routing
    Native DRC with refilled zones: 0 errors, 0 schematic parity on both halves.
    Refreshed ratsnest, routing.json, renders and the status table.
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2026-10-07 Report the core draft at 1,526 open edges after neck-down routing
    Fresh settled native count 1,526 (+12V 80, -12V 80, +5V 0, AGND 249, signals
    1,117); native DRC 0 errors, 0 schematic parity. Refreshed DRC report,
    renders and the status table.
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2026-10-07 Keep the board's project when grid_apply loads a ripped copy
    LoadBoard on <stem>.ripped.kicad_pcb found no project, loaded default net
    classes, and SaveBoard then wrote that project over the candidate's
    .kicad_pro. Every stage that ripped copper was checked with AGND at the
    default 0.2 mm clearance instead of 0.25 mm: one ripped track on jack-right
    reads 169 open edges (AGND 22) in place versus 175 (AGND 28) with the fix,
    which also matches every fresh check.
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2026-10-07 Route osc-core on CI in 8 region shards: rrr-01..rrr-24, open edges 1526 -> 1523
    Sharded hotspot-region renegotiation from ce33612e719f3083267bad03dc9a7f3d15d3733b, merged and checked natively once.
    Shard jobs: failure. Unvalidated draft; electrical and physical qualification NOT RUN.
    Run: https://github.com/Takazudo/zudo-osc-hole-field/actions/runs/37663117073
2026-10-07 Stitch AGND on a signal candidate before judging it
    With the true AGND clearance, region stages close signal edges but cut as
    many AGND surface-pour islands (jack-left region-05..07: 146 in place with
    the wrong project, 153 fresh). A candidate whose signal edges fell but whose
    total did not now gets an AGND-stitching pass, and the pair is adopted when
    the stitched total falls. Shards skip it: AGND is not a shard-owned net.
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2026-10-08 Route osc-core on CI in 8 region shards: signals-local..signals-40, open edges 1523 -> 1516
    Sharded hotspot-region renegotiation from d40c77cc146b09dfe73662078ca262e7de9c0c6d, merged and checked natively once.
    Run: https://github.com/Takazudo/zudo-osc-hole-field/actions/runs/37705724819
    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
2026-10-08 Report the jack halves at 153 and 175 open edges
    Refreshed reports, renders and the status table.
    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
2026-10-08 Report the core draft at 1,509 open edges
    Fresh settled native count 1,509 (+12V 80, -12V 80, +5V 0, AGND 252, signals
    1,097); native DRC 0 errors, 0 schematic parity.
2026-10-08 Escalate rip-up budgets every round and join islands to their nearest island
    Jack-left diagnosis (main, 153 open edges): every stranded signal island is a
    bare pad, cut lines keep 6x free lanes for the open demand, and each rip-up
    probe found a path but needed 5-20 victim nets; at the 4-net budget all 109
    were skipped, and the 6/8 budgets never ran because escalation required an
    adopted round. Rounds now escalate regardless, with 8, 12 and 20-net budgets.
    route_groups joins each island to the cheapest island of another component
    instead of only the largest, so stranded neighbours such as an op-amp's
    follower pins join each other.
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2026-10-08 Report the jack halves at 140 and 162 open edges after escalated rip-up
    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
2026-10-17 feat: scope musical CV acceptance and retain oscillator calibration controls [skip ci]
2026-10-17 feat: select existing HF trimmer candidate and bound calibration claims [skip ci]
2026-10-17 feat: add Stage28 DIN manufacturing decisions and vendor-completed A01 harness candidate [skip ci]
    Add a D01-D14 HARTING DIN decision table and a 34-conductor plus
    96-contact harness ledger from the Stage15/16 transport contract. Also
    add an assembly drawing candidate, an unsent questionnaire with
    post-answer decisions, and a minimum unpowered measurement checklist.
    A deterministic generator/validator and regression tests cover all of
    these.
    The generator finds the Stage6/Stage10 DIN labels mirrored against the
    HARTING body-side views in the locked frame. Det is -1/+1 where the
    views require +1/-1. A column-reversal candidate is recorded but not
    adopted; D02 stays CONFLICT_REQUIRES_DECISION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
2026-10-17 feat: add Stage29 unadopted DIN column-reversal source correction candidate [skip ci]
    Re-verify both HARTING drawings (same SHA256 as Stage5/Stage28) from their
    vector geometry and readable crops: female view A rows a/b/c with the fixing
    holes 0.3 mm toward row a, male view B rows c/b/a, both seen from the body.
    Propose candidate_position(row, n) = Stage10_position(row, 33 - n) for
    J17909/J17910 so drawing-to-board determinants become +1/-1, keeping nets on
    physical contact IDs, the hole set, planes and fixing holes. Not adopted;
    D02 stays CONFLICT_REQUIRES_DECISION and physical M-01 is NOT RUN.
2026-10-17 feat: add Stage30 design-only provisional DIN integration for A01 [skip ci]
    Record the owner's design-only provisional adoption of the Stage29 DIN
    column-reversal positions, recompute the 34 DIN-incident allocations and
    11 signal paths, add a separate J-PWR route study against the modelled
    Stage10 keep-outs, and prepare 1:1 M-01 prints with an empty record sheet.
    D02 stays CONFLICT_REQUIRES_DECISION; M-01, native and physical NOT RUN.
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
